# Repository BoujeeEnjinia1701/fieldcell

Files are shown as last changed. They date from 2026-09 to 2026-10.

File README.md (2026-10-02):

# FieldCell

     

**Area:** Situational Field Hardware · **TRL:** 3 of 9 (proof of concept on paper) · **Value-engineering target:** about $2,100 USD (estimated parts cost $2,101) · **Difficulty:** 3 of 5

Two-wheel hand cart carrying fold-out PV and a LiFePO4 bank, with an inverter and DC outlets, that one person can deploy in under 10 minutes.

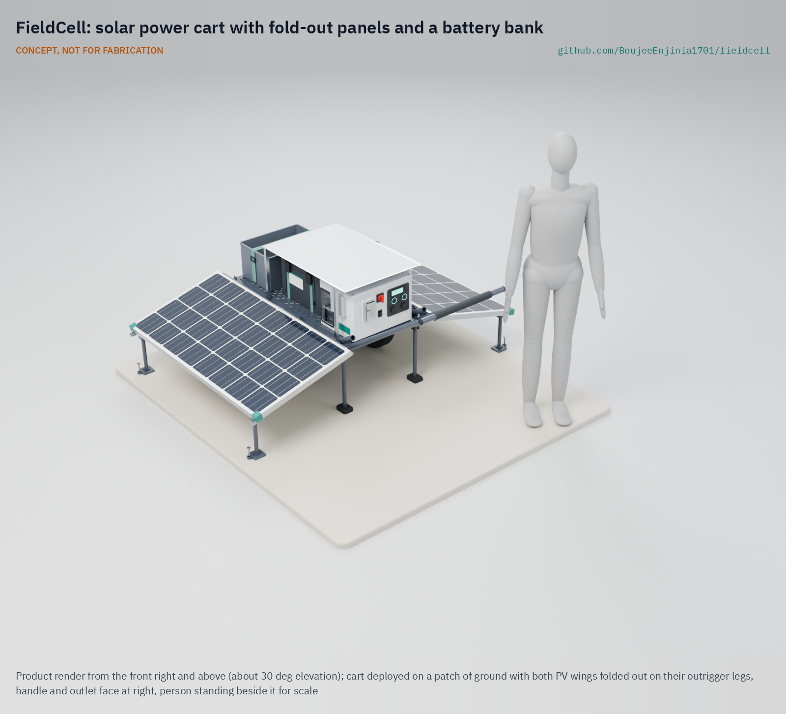
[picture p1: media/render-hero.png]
FieldCell: solar power cart with fold-out panels and a battery bank, product render


[Exploded render](media/render-exploded.png) · [Detail render](media/render-detail.png) · [Interactive 3D model](media/viewer.html) · [Concept blueprint (PDF)](media/concept-blueprint.pdf) · [General arrangement FCL-DWG-002 (PDF)](cad/drawings/FCL-DWG-002.pdf) · [Sizing calculations](docs/04-calcs/01-sizing.md) · [Prototype build plan](docs/05-build-plan.md) · [Design decisions](docs/06-design-decisions.md) · [Review note](docs/REVIEW.md)

## Concept rationale

Most field posts need a few hundred watts, not the several kilowatts of a generator, and they need it quietly, next to people, from the first hour. FieldCell puts about 1.3 kWh of LiFePO4 storage and 400 W of solar on a two-wheel cart whose sides are the panels themselves, so there is nothing to lay out, aim or cable on arrival: one person wheels it in, folds the wings down and switches on. The fixed east-west wings give up some energy against a sun-aimed panel in return for speed and a closed, protected box in travel.

It is open and garage-buildable because the organizations that deploy it, from volunteer fire brigades to small humanitarian teams, need to inspect, repair and adapt it where they work. A welded steel frame, off-the-shelf charge controller, inverter and outlets, and a priced, documented BOM mean it can be built and serviced with common tools and without custom electronics.

## Burning platform

Generators are the default for temporary power, and they kill. In the United States, portable generators were linked to 800 of 931 non-fire carbon monoxide deaths associated with engine-driven tools from 1999 to 2012, more than 85 % ([US Consumer Product Safety Commission, 2013](https://cpsc.gov/content/winter-warning-portable-generators-hold-top-spot-in-cpsc-report-on-carbon-monoxide-deaths)). The outages that send people to generators are getting longer: US electricity customers averaged 11 hours without power in 2024, nearly double the average of the previous decade, and major events such as Hurricanes Beryl, Helene and Milton accounted for 80 % of those hours ([US Energy Information Administration, 2025](https://www.eia.gov/todayinenergy/detail.php?id=66744)).

Where there is no grid at all, field teams start from nothing. In 2023, 666 million people still lacked electricity, 85 % of them in sub-Saharan Africa ([World Bank, *Tracking SDG 7*, 2025](https://www.worldbank.org/en/topic/energy/publication/tracking-sdg-7-the-energy-progress-report-2025)), so relief and survey crews there bring their own power or do without.

## Where it could be used

### By industry

| Industry | Use |
| --- | --- |
| Disaster response and emergency management | Quiet power for radios, lighting, laptops and chargers at incident command posts, shelters and search and rescue bases |
| Humanitarian aid | Registration desks, water points and clinics in camps where fuel is scarce and resupply is slow |
| Utilities and infrastructure | Daytime tool and battery charging for line, pipeline and telecom crews away from vehicle tracks |
| Environmental survey and conservation | Power for instruments, drones and camp electronics in protected areas where generators are unwelcome |
| Events and community resilience hubs | Shared phone charging, lighting and Wi-Fi in parks and schools during outages |
| Education | A teaching platform for PV, batteries, inverters and electrical safety |

### By country or region

| Country or region | Why it matters there |
| --- | --- |
| United States (Southeast and Gulf Coast) | South Carolina customers averaged nearly 53 hours without power in 2024, mainly from Hurricane Helene ([US EIA, 2025](https://www.eia.gov/todayinenergy/detail.php?id=66744)) |
| Philippines | An average of 20 tropical cyclones enter its area of responsibility each year, 8 or 9 of them crossing the country ([PAGASA](https://www.pagasa.dost.gov.ph/climate/tropical-cyclone-information)) |
| Pakistan | The 2022 monsoon floods affected an estimated 33 million people ([UN News, 2022](https://news.un.org/en/story/2022/08/1125752)) |
| Sub-Saharan Africa | Home to 85 % of the 666 million people without electricity in 2023 ([World Bank, 2025](https://www.worldbank.org/en/topic/energy/publication/tracking-sdg-7-the-energy-progress-report-2025)) |
| Caribbean (Puerto Rico and US Virgin Islands) | After Hurricanes Irma and Maria in 2017, restoring power to all customers whose structures were safe to reconnect took about 11 months in Puerto Rico and about 5 months in the US Virgin Islands ([US GAO, 2019](https://www.gao.gov/products/gao-19-296)) |

## What sparked the idea

The idea traces back to the US Marine Corps Experimental Forward Operating Base program, which equipped India Company, 3rd Battalion, 5th Marines in Sangin District, Afghanistan, with portable solar systems such as GREENS and SPACES. At Patrol Base Sparks, the unit reported that generators that typically burned more than 20 gallons (76 L) of fuel a day were down to 2.5 gallons (9.5 L), which meant fewer refuelling convoys exposed to roadside bombs ([DVIDS, January 6, 2011](https://www.dvidshub.net/news/63126/india-company-3-5-dark-horse-marines-use-solar-power-brighten-mission-accomplishment)). The same logic holds for a disaster zone, where every fuel run competes with rescue traffic. Those were military kits issued to trained units. FieldCell asks what an open, one-person version for civilian responders would look like: panels, battery and outlets on one cart, working minutes after arrival.

## Problem

Disaster responders and remote crews rely on noisy, fuel-hungry generators.

## Concept

Two-wheel hand cart carrying fold-out PV and a LiFePO4 bank, with an inverter and DC outlets, that one person can deploy in under 10 minutes.

FieldCell is the portfolio's mobile field-site unit: PV only, 1 kW AC, a one-person cart and its own 25.6 V pack. PowerBox is the household outage unit (multi-input, indoor, on a SwapCell pack), and SwapCell is the shared pack standard.

Full design precis: [docs/02-concept.md](docs/02-concept.md)

## Key components

- Folding PV panels 200 W (2)
- LiFePO4 bank 1.28 kWh (25.6 V 50 Ah)
- MPPT charge controller
- Inverter 1 kW
- Welded steel cart frame, 16 in flat-free wheels, detachable handle, folding stand legs
- IP65 battery case and IP54 electronics enclosure with thermostat filter fan
- Reflective sun shade over both enclosures, hinge line on a 20 mm spacer
- Two tie bars that hold the folded-up wings together for travel

The priced bill of materials is in [bom/bom.csv](bom/bom.csv) (about $2,101 at TRL 3, USD 1 over the $2,100 value-engineering target set on 2026-09-25, after the parts that make the design buildable; see the [design decisions register](docs/06-design-decisions.md)).

## Building the prototype

The [prototype build plan](docs/05-build-plan.md) (FCL-BLD-001) shows how to build the first FieldCell, component by component and step by step, with a making sketch for every made part and a picture for every assembly step. It is a plan, not a record of a build. The frame is welded from steel tube in a garage; the wings, shade and tie bars are cut and riveted from aluminium tube; the enclosures, electronics, wheels and modules are bought. Making the concept buildable added brackets, sockets, hinge tabs, tie bars and shade uprights (decision record FCL-DDR-003) and brought the cart to about 80 kg, inside the 82 kg limit set on 2026-10-02; the decisions are recorded in the [design decisions register](docs/06-design-decisions.md).

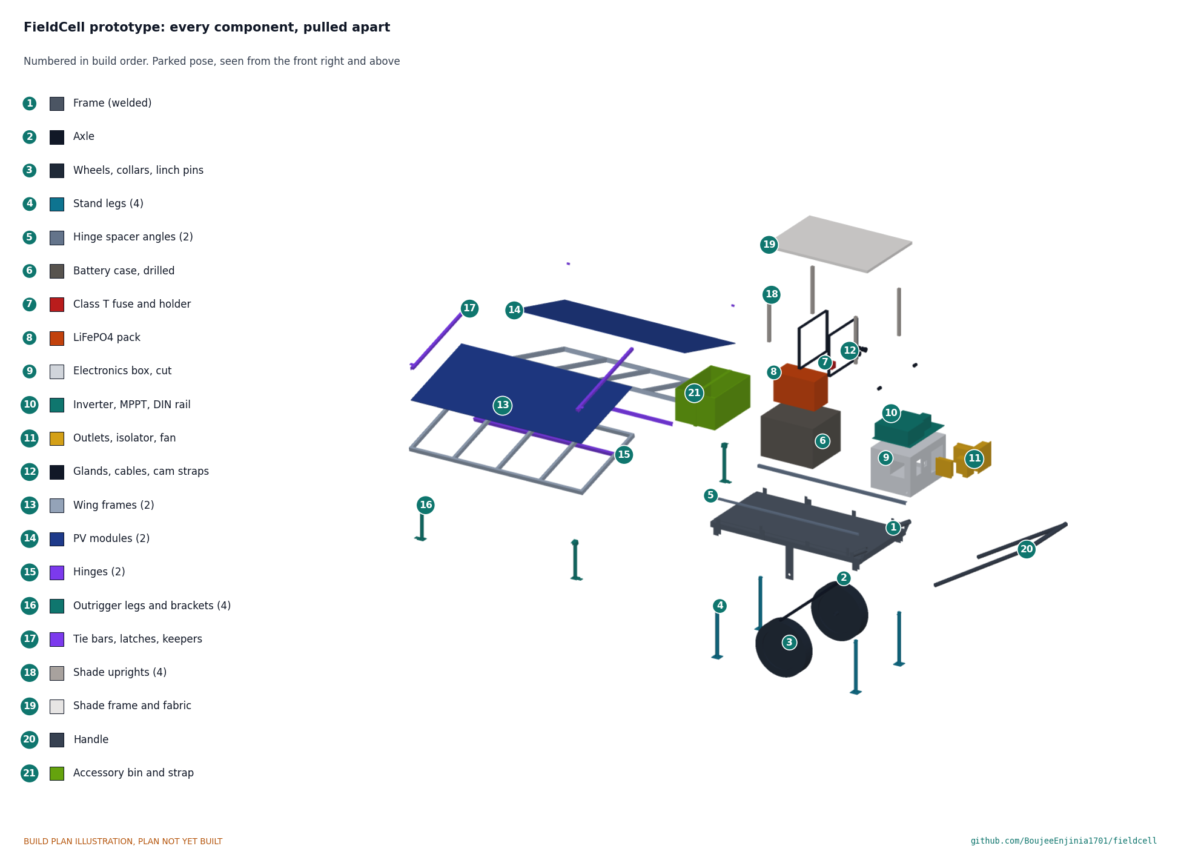
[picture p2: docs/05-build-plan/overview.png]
FieldCell prototype: every component pulled apart and numbered in build order


## Safety

> Contains a high-energy battery and AC output. Fuse every circuit and follow local electrical code.

## Repository layout

| Folder | Contents |
| --- | --- |
| `docs/` | Problem, concept, requirements, calculations and design decisions |
| `cad/src/` | build123d Python source, the source of truth for all geometry |
| `cad/step/`, `cad/stl/` | Exported models for FreeCAD, other CAD tools and printing |
| `cad/drawings/` | 2D sketches and dimensioned drawings |
| `bom/` | Bill of materials |
| `electronics/` | KiCad schematics and PCB layouts |
| `firmware/` | Microcontroller code |
| `media/` | Renders, perspectives and photos |
| `build-log/` | Dated prototyping notes |

## Documentation

Controlled documents follow the portfolio [documentation standard](.kit/STANDARDS.md). Each carries a document ID (FCL-PRC-001 for the precis), a version and a revision history. Branded PDFs are built with `python .kit/render.py` and attached to GitHub Releases when a document is tagged, for example `FCL-PRC-001/v1.0`.

## Credits

Designed by Amish Chadha. See [CONTRIBUTORS.md](CONTRIBUTORS.md) for roles. To cite this design, use [CITATION.cff](CITATION.cff) (GitHub shows it as "Cite this repository").

AI assistance (Claude) was used to accelerate concept renders, prototype documentation and first-pass sizing calculations. Design direction and all decisions are Amish Chadha's, recorded in this repository's decision records (`docs/decisions/`).

## Licenses

- **Hardware** (CAD, drawings, BOM, electronics): [CERN-OHL-S v2](LICENSE)
- **Software** (firmware, scripts, notebooks): [MIT](LICENSE-SOFTWARE)

A project of the [Design Molecule](https://designmolecule.com) lab.

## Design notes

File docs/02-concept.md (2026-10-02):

---
doc_id: FCL-PRC-001
title: FieldCell design precis
project: FieldCell
doc_type: Design precis
version: "0.7"
status: Draft
date: '2026-10-02'
author: Amish Chadha
license: CERN-OHL-S-2.0
revisions:
- version: "0.1"
  date: '2026-09-24'
  author: Amish Chadha
  change: Initial scaffold
- version: "0.2"
  date: '2026-09-24'
  author: Amish Chadha
  change: Populate to TRL 2 (architecture, first-order numbers, design choices, safety, media)
- version: "0.3"
  date: '2026-09-25'
  author: Amish Chadha
  change: TRL 3 update. Decisions of FCL-DDR-001 recorded; numbers replaced by FCL-CAL-001; parametric model, drawing FCL-DWG-002 and priced BOM
- version: "0.4"
  date: '2026-09-25'
  author: Amish Chadha
  change: Recommendations accepted by Amish (DDR-002)
- version: "0.5"
  date: '2026-10-01'
  author: Amish Chadha
  change: Constructable design (FCL-DDR-003); component table, numbers and safety notes follow FCL-CAL-001 v0.3; build plan FCL-BLD-001
- version: "0.6"
  date: '2026-10-01'
  author: Amish Chadha
  change: Budget treated as a value-engineering target
- version: "0.7"
  date: '2026-10-02'
  author: Amish Chadha
  change: "Mass and pull limits, charging inputs and portfolio positioning decided by Amish on 2026-10-02 (FCL-DEC-001)"
---

# FieldCell design precis

FieldCell is a two-wheel hand cart whose two sides are 200 W solar panels. For travel the panels stand up as the cart walls; on site they fold out as wings on outrigger legs. Between them sit a 1.28 kWh LiFePO4 pack, an MPPT charger, a 1 kW inverter and DC outlets. The TRL 3 calculations (FCL-CAL-001) show that it stores about 1.17 kWh a day from its own PV at 4 kWh/m²/day of global horizontal irradiation, carries a 0.9 kWh/day field load for 1.08 days without sun, and deploys in about 6.5 minutes. A reflective sun shade covers the battery and electronics enclosures, and the wing hinges sit on 20 mm spacers to clear the tyres. The design is constructable (FCL-DDR-003): every part can be made or bought and is fixed to its neighbours, as the prototype build plan FCL-BLD-001 shows. The parts that made it buildable bring the cart to about 80 kg against a 75 kg limit (R6) and the pull on a grass grade to 156 N against 150 N (R7), and the parts cost an estimated $2,101 against a $2,100 value-engineering target (R12, USD 1 over); how to close the mass and pull gaps is awaiting Amish and the savings worth trying are in FCL-DEC-001.

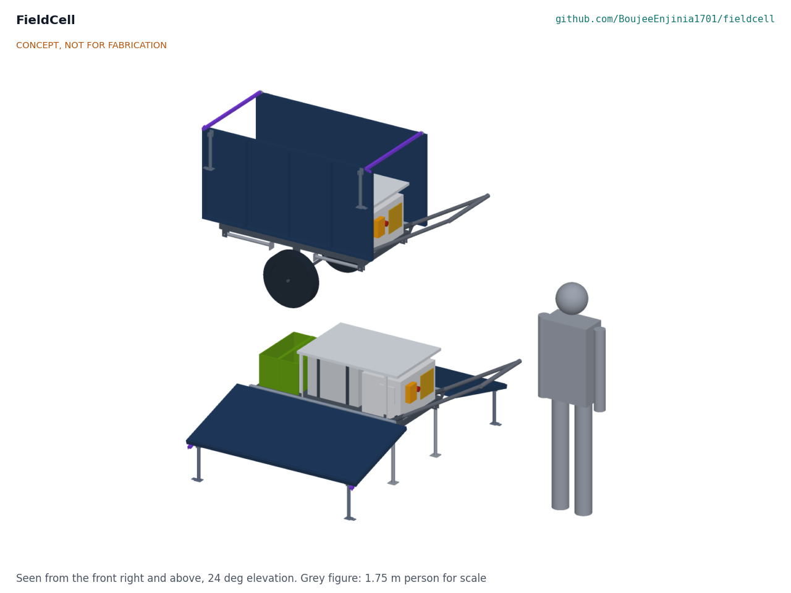
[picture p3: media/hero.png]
Hero render


*Figure 1. FieldCell deployed (front) and stowed for travel (behind), with a 1.75 m person for scale. Generated from the parametric model `cad/src/model.py`.*

## How it works

1. **Travel.** The wings stand upright as the cart sides, over the battery and electronics, held together at the top by two tie bars with over-centre latches. One person pulls or pushes the cart by the T-handle on two 16 in (406 mm) flat-free wheels. The sun shade sits on four uprights on the frame, 50 mm above the enclosures, and stays in place in travel. The center of gravity sits about 54 mm on the handle side of the axle, so the handle carries a light, positive load.
2. **Park.** Four stand legs fold down so the deck sits level at 460 mm.
3. **Deploy.** The tie bars unlatch and fold down the back of the left wing; each wing swings out on a continuous hinge, mounted on a 20 mm spacer angle bolted to tabs on the side rail, coming to rest 15° below horizontal on two fold-down outrigger legs. With the cart's long axis north to south, one wing faces east and one faces west. In wind, the four outrigger feet are staked.
4. **Charge.** The panels are pre-wired in parallel to the MPPT charge controller, which charges the 25.6 V pack. No cable is connected on site.
5. **Power.** The operator switches on the battery isolator and the inverter. Loads plug into the 120 V AC outlet (GFCI protected) and the DC panel (USB-C PD and 12 V sockets) on the handle end of the electronics box. A shunt monitor shows state of charge. A thermostat runs an IP54 filter fan when the box is warm, and the shade keeps direct sun off both enclosures.

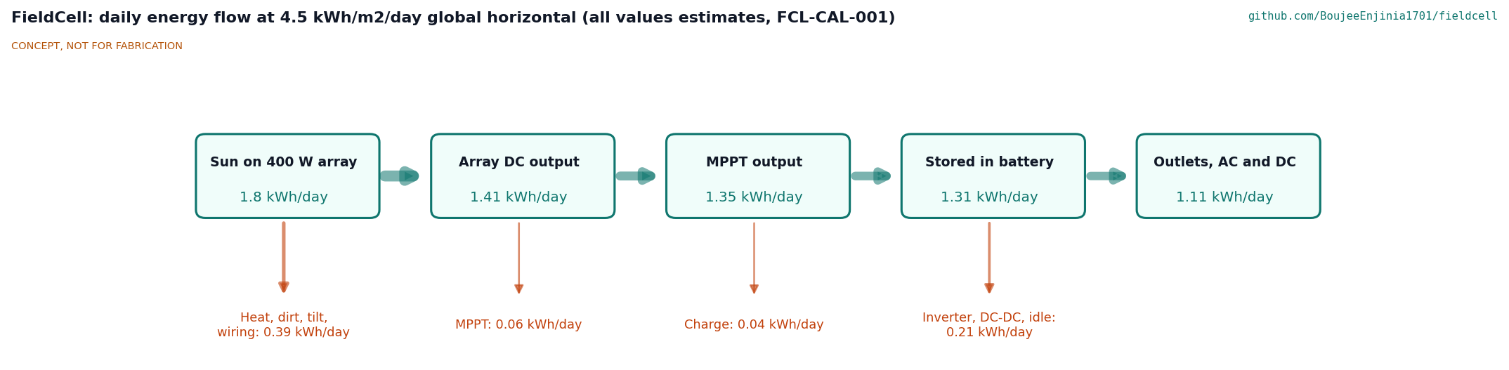
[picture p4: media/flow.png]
Energy flow


*Figure 2. Daily energy flow at 4.5 kWh/m²/day global horizontal irradiation. All values are estimates from FCL-CAL-001.*

## Main components

Numbers match the exploded view (Figure 3) and `bom/bom.csv`. Drawing FCL-DWG-002 gives the general arrangement and main dimensions.

*Table 1. Main components.*

| # | Component | Choice | Notes |
| --- | --- | --- | --- |
| 1 | Cart frame and axle | 40 x 40 x 1.5 mm steel square tube, 1,200 x 600 mm, expanded-metal deck on the cross tubes, braced axle brackets, 20 mm axle, hinge tabs, handle sockets, leg clevises | Welded steel, decided (FCL-DDR-001, D5); about 15.4 kg (FCL-DDR-003) |
| 2 | Wheels (2) | 16 in (406 mm) flat-free, 720 mm track | Flat-free, decided (D5); about 4 kg each |
| 3 | Handle | Steel T-handle, grip at 900 mm, in two welded sockets with quick-release pins | Detaches for vehicle transport |
| 4 | Stand legs (4) | Tube legs on welded clevises, folding along the rails, detent pins | Level the deck when parked |
| 5 | Battery enclosure | IP65 case, about 420 x 360 x 300 mm | Sits over the axle, lowest heavy item |
| 6 | LiFePO4 pack | 25.6 V 50 Ah (1.28 kWh), 100 A BMS with low- and high-temperature charge cutoff | 24 V system, decided (D1) |
| 7 | Electronics enclosure | IP54, about 320 x 460 x 300 mm, IP54 filter fan (about 40 m³/h) and exhaust filter | Outlet face toward the handle; thermostat filter fan decided (FCL-DDR-002) |
| 8 | MPPT charge controller | 100 V, 20 A | At most 15 A from 400 W |
| 9 | Inverter | 1 kW continuous, 2 kW surge, pure sine, high-frequency, 24 V input, 120 V 60 Hz | 120 V first, 230 V 50 Hz variant documented, decided (D4) |
| 10 | DC outlet panel | 2 x USB-C PD 100 W, 2 x 12 V sockets, 24 to 12 V 20 A converter | 440 W DC in total |
| 11 | AC outlet with GFCI | GFCI duplex (120 V), in-use cover; 30 mA RCD socket for the 230 V variant | |
| 12 | Fusing and disconnect | Class T 100 A main fuse in the battery case within 150 mm of the terminal, isolator on the outlet face, DC breakers, shunt monitor | Fuse position fixed by FCL-DDR-003 |
| 13 | PV wings (2) | 200 W semi-flexible module bonded to a 1,400 x 700 mm frame of 30 x 20 mm aluminium tube with three ribs, 35 mm deep, about 6.0 kg, 24 V class (Vmp about 36 V) | Parallel wiring, decided (D3) |
| 14 | Panel hinges, spacers and latches | 1.2 m piano hinge per side on a 20 × 20 × 2 mm aluminium angle spacer bolted to steel tabs on the rail; two over-center latches for the tie bars | Spacer raises the hinge line, decided (FCL-DDR-002); pinch points, see Safety |
| 15 | Outrigger legs (4) | Legs on riveted brackets under the wing's outer edge, folding flat under the wing, with stake loops and stakes; set the 15° tilt | Stakes required above about 9 m/s wind |
| 16 | Accessory and cable bin | Open bin, balances the electronics box | Cords, lights, stakes |
| 17 | Wiring and hardware | 16 mm² (6 AWG) battery cable, PV cable, glands, cam straps, fasteners | Battery cables, glands and straps modeled |
| 18 | Sun shade | Reflective aluminized fabric on a light aluminium frame, about 830 × 580 mm, on four 355 mm uprights bolted to the rails, about 1.55 kg | Over both enclosures, decided (FCL-DDR-002); lifts off to open the battery case |
| 19 | Wing tie bars (2) | 20 × 20 mm aluminium bars pivoted on the left wing, latched to the right wing across the tops in travel | Added by FCL-DDR-003 |

## Key numbers

All values are estimates from FCL-CAL-001 (`docs/04-calcs/sizing.py`), which checks every requirement.

*Table 2. Key numbers.*

| Quantity | Value | Basis | Requirement |
| --- | --- | --- | --- |
| Stored energy | 1.28 kWh nominal, 1.15 kWh usable | 25.6 V x 50 Ah; 90 % depth of discharge | R1 met |
| PV energy into battery | 1.17 kWh/day at 4 kWh/m²/day, 1.31 at 4.5, 1.46 at 5 (25 °C air) | 400 W x GHI x 0.729 (transposition 0.947, temperature 0.915, other losses) | R3 met |
| East-west penalty | About 14 % against one panel aimed south at latitude tilt | Clear-sky model at 15, 30 and 45° N | |
| Peak charge power | About 260 to 290 W | Noon, east-west wings | |
| Full recharge, 10 to 100 %, no load | 0.79 day at 5 kWh/m²/day | 1,152 Wh / daily yield | R3 met |
| Reference load from battery | 1,063 Wh/day | 897 Wh at the outlets, Table 4 | |
| Autonomy with no sun | 1.08 days | 1,152 / 1,063 Wh | R4 met |
| Battery current | 46 A at 1 kW AC; 66 A with full DC; 98 A surge | 24 V at the low end | R2 met |
| Total mass | About 80.0 kg | Table 5 | R6 met (2.0 kg under the 82 kg limit set on 2026-10-02) |
| Center of gravity | 54 mm toward the handle from the axle, 561 mm above ground | Table 5 | R6 |
| Handle force, travel | 34 N level; 14 to 54 N at a 5° pitch | CG offset x weight / 1,240 mm axle to grip | R6 met |
| Lateral static tip angle | 32.7° | atan(360 mm half-track / 564 mm CG height) | R7 met |
| Pull force, 10 % grade | 125 N (gravel) to 156 N (grass) | 785 N weight x (grade + rolling resistance) | R7 met (grass, 160 N limit set on 2026-10-02) |
| Ground clearance | 193 mm | Under the axle, legs folded | R7 met |
| Deploy and stow time | 6.5 and 5.5 min | Table 6 | R5 met |
| Deployed footprint | About 2.0 x 2.0 m including the handle | Model, wings at 15° | |
| Stowed size, handle off | 1,400 x 830 x 1,220 mm | Model | |
| Wing to tyre clearance, deployed | 28 mm | Model, 20 mm hinge spacer | |
| Electronics box at 45 °C ambient | About 53 °C with the fan and shade, 70 °C sealed and unshaded, at 1 kW | Section G of FCL-CAL-001 | R9 at risk |
| Pack under the shade, noon, 45 °C ambient | About 48 °C (55 °C unshaded) | Section G of FCL-CAL-001 | R9 at risk |
| Wing lift-off wind speed, unstaked | About 8.9 m/s | Normal force coefficient 1.2 on 0.98 m², wing weight 59 N | R10 met only staked |
| Parts cost | About $2,101 against the $2,100 value-engineering target | `bom/bom.csv` | **R12 over the value-engineering target by USD 1** |

### PV yield

FCL-CAL-001 reads "peak sun hours" as daily global horizontal irradiation (GHI) and converts it to the wings with a clear-sky transposition model. At 15° the east-west wings collect about 0.95 of GHI, nearly as much as a horizontal panel, but about 14 % less than one panel aimed south at latitude tilt; the penalty is larger in winter at high latitude. With the cells at about 47 °C in 25 °C air, the 400 W array delivers about 0.78 of its rating times GHI at its terminals and 0.73 into the battery. At 4.5 kWh/m²/day that is 1.80 kWh at rating, 1.41 kWh at the array, 1.35 kWh after the MPPT and 1.31 kWh into the battery (Figure 2).

### Load profile and days of autonomy

The reference load is a small field post: a responder team's comms and lighting, one laptop station, and occasional tool use.

*Table 3. Reference load profile (assumed).*

| Load | Power | Hours per day | Energy at outlet | Path |
| --- | --- | --- | --- | --- |
| LED area lighting | 30 W | 8 | 240 Wh | DC |
| Radio, phone and satellite messenger charging | 30 W | 8 | 240 Wh | DC |
| Laptop and Wi-Fi router | 50 W | 6 | 300 Wh | AC |
| Power tool or small pump | 700 W | 1/6 (10 min) | 117 Wh | AC |
| **Total** | | | **897 Wh** | |

*Table 4. Energy drawn from the battery (assumed efficiencies, FCL-CAL-001).*

| Path | At outlet | Efficiency | From battery |
| --- | --- | --- | --- |
| DC (USB-C and 12 V converters) | 480 Wh | 0.93 | 516 Wh |
| AC (inverter), including 10 W idle for 7 h | 417 Wh | 0.92 plus idle | 523 Wh |
| Standby and filter fan | | | 24 Wh |
| **Total** | **897 Wh** | **0.844 overall** | **1,063 Wh** |

With 1.15 kWh usable, the pack carries this load for 1.08 days with no sun. At 4 kWh/m²/day the PV stores 1.17 kWh/day, a surplus of about 10 %; at 4.5 the surplus is about 24 %. The system breaks even at about 3.6 kWh/m²/day. A run of cloudy days is not covered. Inverter idle draw is the most sensitive assumption: each extra 5 W costs about 3 % of the daily load.

### Mass and center of gravity

*Table 5. Mass budget, wings stowed, deck level. X is measured from the deck center toward the handle; the axle is at X = 30 mm. From FCL-CAL-001 v0.3.*

| Item | Mass (kg) | X (mm) | Z (mm) |
| --- | --- | --- | --- |
| Frame, deck and axle (welded steel) | 15.4 | 5 | 420 |
| Wheels, flat-free (2), collars, pins | 8.3 | 30 | 203 |
| Handle | 2.6 | 950 | 700 |
| Stand legs | 2.5 | 0 | 230 |
| Battery enclosure | 3.0 | 0 | 610 |
| LiFePO4 pack | 12.0 | 0 | 576 |
| Electronics enclosure, filter fan, inverter, MPPT, fusing, monitor and outlets | 11.3 | 430 | 568 |
| Accessory bin and cables | 4.0 | −420 | 560 |
| PV wings, stowed (2) | 12.0 | 0 | 845 |
| Hinges, latches, outriggers and stakes | 4.1 | 0 | 820 |
| Hinge spacers (2) | 0.5 | 0 | 484 |
| Sun shade, frame and uprights | 1.6 | 185 | 760 |
| Wing tie bars (2) | 0.5 | 0 | 1,205 |
| Wiring, hardware and straps | 2.3 | 200 | 600 |
| **Total** | **80.0** | **84** | **561** |

The center of gravity is 54 mm on the handle side of the axle. At the 900 mm grip the handle carries about 34 N (3.5 kgf), and it stays positive between 14 and 54 N if the user holds the cart 5° nose-up or nose-down. The load in the accessory bin is the trim: moving 4 kg of cords from the bin to the electronics end raises the handle force by about 27 N. Amish relaxed the R6 limit to 75 kg on 2026-09-25 to keep the decided steel frame and flat-free tyres (FCL-DDR-002). Making the design buildable (FCL-DDR-003) added the brackets, gussets, tabs, sockets, clevises, fixings, tie bars and shade uprights the massing model did not have, about 4.9 kg, so the cart is about 5 kg over the limit and the pull on a 10 % grass grade is 156 N against 150 N. A bolted aluminium frame would bring the cart to about 72.7 kg. How to close the gap is an open decision, awaiting Amish (FCL-DEC-001, item 2).

### Deployment sequence

*Table 6. Deploy and stow time estimates, one person.*

| Deploy step | Time | Stow step | Time |
| --- | --- | --- | --- |
| Turn the cart north to south, drop four stand legs | 1.0 min | Loads off, inverter off, isolator off | 0.5 min |
| Unlatch both tie bars, fold each down the left wing | 0.5 min | Pull four stakes | 1.0 min |
| Fold the first wing out, swing down its two outrigger legs | 1.5 min | Fold the first wing's outriggers, raise it | 1.5 min |
| Same for the second wing | 1.5 min | Same for the second wing | 1.5 min |
| Stake the four outrigger feet (when wind is expected) | 1.0 min | Swing both tie bars over and latch them | 0.5 min |
| Isolator on, check the monitor, inverter on, plug in loads | 1.0 min | Raise four stand legs | 0.5 min |
| **Total** | **6.5 min** | **Total** | **5.5 min** |

## Key design choices

- **Panels as the cart walls, in fixed east-west wings at 15°.** The wings protect the battery and electronics in travel and need no separate storage, cables or aiming on site; they cost about 14 % of the energy a south-aimed panel would collect. Decided by Amish, 2026-09-25 (FCL-DDR-001, D2).
- **24 V class panels in parallel.** With Vmp about 36 V each, the panels can be paralleled into one MPPT and still charge a 25.6 V pack, so the off-sun wing does not limit the other. At 70 °C cell the headroom above the absorption voltage is under 1 V, so the chosen module must have Vmp of at least 36 V at STC. Decided by Amish, 2026-09-25 (D3).
- **25.6 V battery system.** Halves the current of a 12.8 V system (46 A instead of about 90 A at 1 kW), allowing thinner cable and a smaller fuse, while 24 V inverters and MPPT controllers remain common. Decided by Amish, 2026-09-25 (D1).
- **120 V 60 Hz output first.** A 230 V 50 Hz variant swaps the inverter and uses a 30 mA RCD socket. Decided by Amish, 2026-09-25 (D4).
- **Welded steel frame and flat-free tyres.** Easiest garage build and no punctures on debris, at a mass cost that put the cart over the earlier 75 kg R6 limit. Decided by Amish, 2026-09-25 (D5), and kept on 2026-10-02 with R6 set at 82 kg (FCL-DEC-001).
- **SwapCell compatibility as a future option only.** A later variant could take a SwapCell 48 V pack in place of item 6, which would need a 48 V inverter and charger. It would rely on three SwapCell interface v0.3 items approved portfolio-wide: a wake method for hosts without CAN, a charge-while-discharging mode (FieldCell charges from PV while loads run) and a latch vibration rating for vehicles. Decided by Amish, 2026-09-25 (D6).
- **Heavy parts low and over the axle.** The battery sits directly over the axle; the electronics box and the accessory bin balance each other fore and aft. Kept as a layout rule, decided by Amish, 2026-09-25 (FCL-DDR-002).
- **Forced ventilation of the electronics box.** A thermostat-controlled IP54 filter fan (40 to 60 m³/h) and exhaust filter keep the box within about 10 K of ambient at 1 kW; a sealed box would reach about 70 °C at 45 °C ambient. Decided by Amish, 2026-09-25 (FCL-DDR-002).
- **Sun shade over the enclosures.** A reflective shade on four posts keeps direct sun off the battery case and electronics box, holding the pack at about 48 °C instead of 55 °C at 45 °C ambient, for about $30 and 1 kg. Decided by Amish, 2026-09-25 (FCL-DDR-002).
- **Hinge spacer.** A 20 mm aluminium angle under each hinge raises the hinge line from 470 to 490 mm and opens the deployed wing-to-tyre clearance from 8 to 28 mm. Decided by Amish, 2026-09-25 (FCL-DDR-002).
- **Irradiance basis.** "Peak sun hours" in R3 and R4 means daily global horizontal irradiation in kWh/m²/day. Confirmed by Amish, 2026-09-25 (FCL-DDR-002).

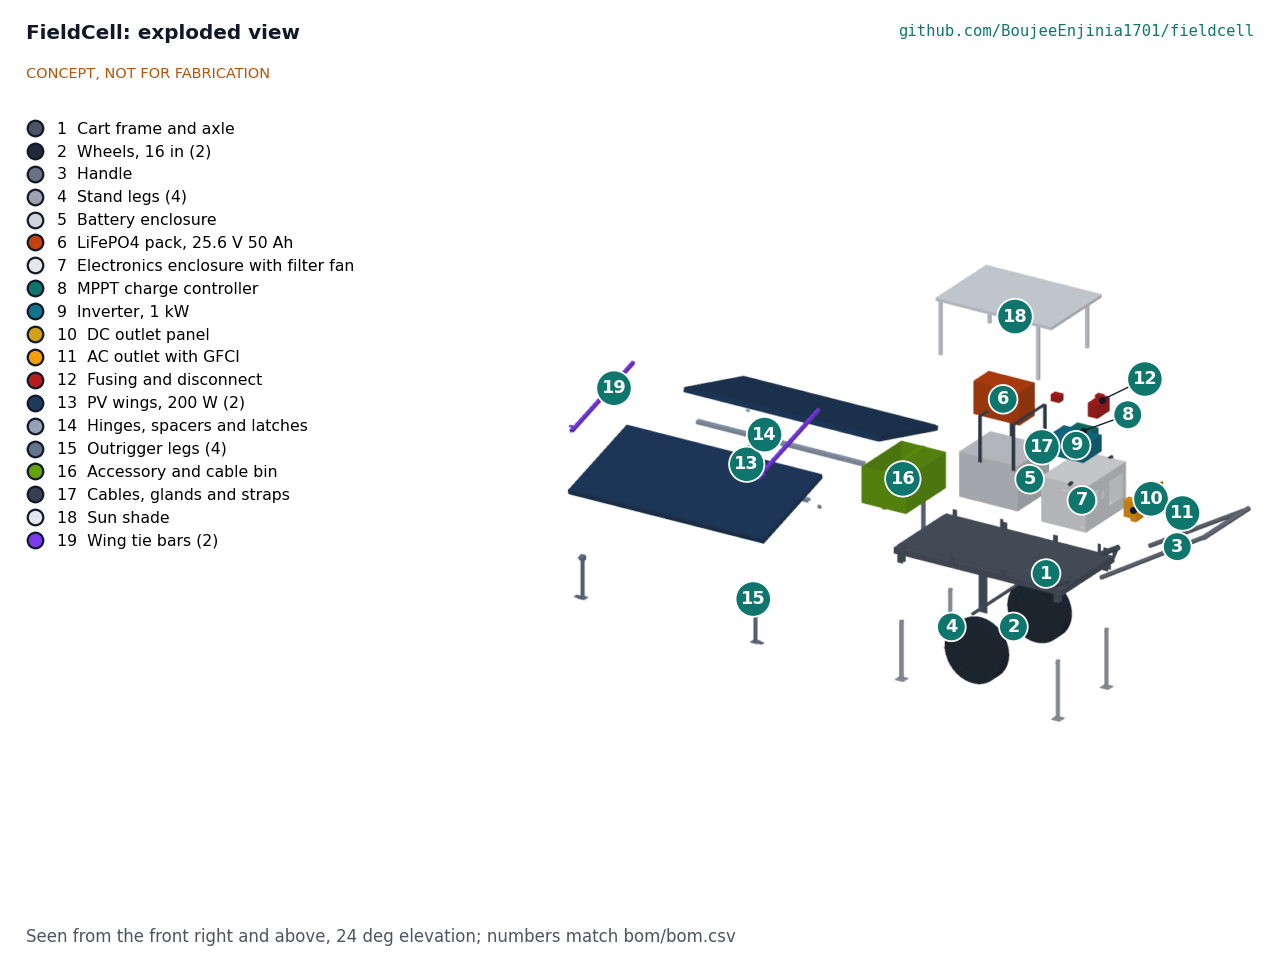
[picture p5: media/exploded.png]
Exploded view


*Figure 3. Exploded view with numbered callouts matching `bom/bom.csv`. The wings and their hinges, outriggers and tie bars (13, 14, 15, 19) are drawn off to the front so the boxes stay visible.*

## Safety

> **Safety:** FieldCell combines a 1.28 kWh lithium battery, 120 V or 230 V AC output, high-current DC wiring, always-live PV panels and a cart of about 75 kg with folding wings. Every one of these is hazardous if the design or the build is wrong.

- **Lithium battery.** Use a LiFePO4 pack with a BMS that protects against overcharge, over-discharge, overcurrent, short circuit and over-temperature, and blocks charging below 0 °C and above about 45 °C. Put a class T fuse within about 150 mm of the positive terminal; in the constructable design it sits inside the battery case beside the pack. Secure the pack so it cannot shift in a tip-over, keep the enclosure vented to outside air, and keep sharp objects and debris out of it. In noon sun at 45 °C ambient the pack can reach about 55 °C unshaded and about 48 °C under the sun shade, so keep the shade in place. Shipping a pack of this size is regulated as dangerous goods.
- **AC output (120 V or 230 V).** Protect every AC outlet with a GFCI (120 V) or a 30 mA RCD (230 V). Bond the inverter neutral and ground to the frame only as the inverter maker specifies for a stand-alone portable source. Use in-use covers in rain, and keep outlets off wet ground.
- **Not for building wiring.** FieldCell has no power inlet and must never be connected to building or grid wiring, including by a "suicide cord" into an outlet. Back-feed can kill utility workers and damage both systems. Any such connection is out of scope.
- **DC wiring and fusing.** Fuse every circuit at its source: main class T fuse at the battery, breakers for the inverter, MPPT and DC outlets, and a PV breaker as the array disconnect. Size cables for the fuse rating. A battery isolator must be reachable without tools. The 2 kW surge with full DC load draws about 118 A for a few seconds; the BMS and fuse must tolerate this.
- **PV panels are live whenever lit.** Open-circuit voltage is about 45 V per panel, up to about 50 V in cold weather, and cannot be switched off at the panel. Do not disconnect PV connectors under load, and cover or disconnect the panels before working in the electronics box.
- **Lifting and handling.** At about 80 kg the cart must not be lifted by one person. Use two people to load it into a vehicle, and remove the battery pack (12 kg) first when possible.
- **Tipping.** The lateral tip angle is about 32.6° when stowed; do not traverse slopes across the fall line, and keep the handle low when descending. When deployed, wings can lift in wind above about 9 m/s unless the outrigger feet are staked; stow the wings in high wind. A stowed cart can be blown over at about 21 m/s side wind.
- **Pinch points.** The wing hinges, tie bar latches and folding legs can trap fingers. The tie bars must be latched to hold the wings firmly in travel. The deployed wing clears the tyre by about 28 mm; keep fingers out of that gap when folding.
- **Heat.** The inverter and MPPT shed up to about 140 W inside the electronics box. Keep the filter fan and exhaust filter clear, and do not run at high load with the vents covered or with the sun shade removed.

## Open questions

- Mass, pull force and cost: about 80 kg and 156 N on a grass grade after the design was made buildable. Decided by Amish, 2026-10-02: R6 set at 82 kg and the R7 grass pull at 160 N, keeping steel and flat-free tyres; the prototype is weighed at TRL 4 and moves to a bolted aluminium frame if it is over 82 kg (FCL-DEC-001). The cost is $2,101 against the $2,100 value-engineering target (R12).
- Inverter derating data at 45 °C (R9) and supplier quotes for the pack, PV wings and inverter to set the real cost against the $2,100 value-engineering target. Decided by Amish, 2026-09-25 (FCL-DDR-002); to be obtained with supplier selection.
- Confirm the inverter idle draw and fan noise (R11) and the filter fan noise from datasheets.
- Whether an AC charger or a vehicle 12 V input should be added for cloudy periods. Decided by Amish, 2026-10-02: no AC charger, since a power inlet is ruled out by the safety case; the vehicle 12 V input is left out of the first prototype and may be offered later as a DC-to-DC charging option if the responder review asks for it (FCL-DEC-001).
- How FieldCell relates to PowerBox and SwapCell in the portfolio. Decided by Amish, 2026-10-02: FieldCell is the mobile field-site unit (PV only, 1 kW AC, one-person cart, own 25.6 V pack), PowerBox the household outage unit (multi-input, indoor, SwapCell pack) and SwapCell the shared pack standard (FCL-DEC-001).
- Handle geometry and grip height for users from 1.55 to 1.90 m tall.

Concept media: [blueprint sheet](../media/concept-blueprint.pdf), [cutaway](../media/cutaway.png), [interactive 3D model](../media/viewer.html). General arrangement: [FCL-DWG-002](../cad/drawings/FCL-DWG-002.pdf). Prototype build plan: [FCL-BLD-001](05-build-plan.md).

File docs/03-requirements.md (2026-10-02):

---
doc_id: FCL-REQ-001
title: FieldCell requirements
project: FieldCell
doc_type: Requirements
version: "0.7"
status: Draft
date: '2026-10-02'
author: Amish Chadha
license: CERN-OHL-S-2.0
revisions:
- version: "0.1"
  date: '2026-09-24'
  author: Amish Chadha
  change: Initial scaffold
- version: "0.2"
  date: '2026-09-24'
  author: Amish Chadha
  change: First measurable requirements for TRL 2
- version: "0.3"
  date: '2026-09-25'
  author: Amish Chadha
  change: Status of every requirement from FCL-CAL-001; R2 names 120 V 60 Hz for the first build (FCL-DDR-001); irradiance basis stated
- version: "0.4"
  date: '2026-09-25'
  author: Amish Chadha
  change: Recommendations accepted by Amish (DDR-002)
- version: "0.5"
  date: '2026-10-01'
  author: Amish Chadha
  change: Values and status from FCL-CAL-001 v0.3 for the constructable design (FCL-DDR-003); no target changed
- version: "0.6"
  date: '2026-10-01'
  author: Amish Chadha
  change: Budget treated as a value-engineering target
- version: "0.7"
  date: '2026-10-02'
  author: Amish Chadha
  change: "R6 set at 82 kg and the R7 grass pull at 160 N by Amish on 2026-10-02 (FCL-DEC-001); both now met on paper"
---

# FieldCell requirements

These are the requirements for the concept. The value and status columns come from the TRL 3 calculation note FCL-CAL-001 v0.3, which checks each one by calculation against the constructable design of FCL-DDR-003. Eight are met, none is not met, one is over its value-engineering target (R12 cost, by $1), one is at risk (R9) and two cannot be verified until test (R8 and R11). On 2026-10-02 Amish set the R6 mass limit at 82 kg and the R7 grass pull at 160 N, keeping the steel frame and flat-free tyres; the prototype is weighed at TRL 4 and moves to a bolted aluminium frame if it is over 82 kg (FCL-DEC-001); the cost savings worth trying for R12 are in its Value engineering section. On 2026-09-25 Amish accepted the TRL 3 recommendations (FCL-DDR-002): the R6 mass limit is relaxed from 70 kg to 75 kg, the value-engineering target behind R12 moves from $1,500 to $2,100, R3 and R4 are stated in global horizontal irradiation, and R8 and R9 name the filter fan and sun shade.

*Table 1. Requirements.*

| ID | Requirement | Target | Value at TRL 3 (FCL-CAL-001 v0.3) | Status | Verification |
| --- | --- | --- | --- | --- | --- |
| R1 | Store enough energy for a day of field use | 1.2 kWh nominal or more; 1.0 kWh usable or more | 1.28 kWh nominal, 1.15 kWh usable at 90 % depth of discharge | Met | Calculation; datasheet |
| R2 | Supply AC and DC loads | 1,000 W continuous pure sine AC at 120 V 60 Hz for the first build (230 V 50 Hz variant), 2,000 W surge; DC outlets 300 W or more in total (USB-C PD and 12 V) | 1 kW inverter by selection; 440 W DC; 66 A continuous battery current on a 100 A fuse and BMS | Met | Calculation; datasheets |
| R3 | Recharge from its own PV | 1.1 kWh/day or more into the battery at 4 kWh/m²/day of global horizontal irradiation (GHI, "peak sun hours"); full recharge from 10 % in one day at 5 kWh/m²/day GHI with no load | 1.17 kWh/day at 4 kWh/m²/day (1.09 in 40 °C air); full recharge in 0.79 day at 5 | Met | PV yield calculation; later logged trial |
| R4 | Carry a reference load through a day without sun | Reference load of 0.9 kWh/day at the outlets for 1 day or more with no sun; energy-neutral at 4 kWh/m²/day GHI or more | 1.08 days; +10 % surplus at 4 kWh/m²/day; break-even at 3.64 | Met | Load and energy balance; later logged trial |
| R5 | Deploy fast with one person | From arrival to power available in 10 min or less, one person, no tools; stow in 10 min or less | 6.5 min deploy, 5.5 min stow by task analysis, including the tie bars | Met | Task analysis; later timed trial |
| R6 | Movable by one person | Total mass 82 kg or less (relaxed from 70 kg to 75 kg in FCL-DDR-002 and to 82 kg on 2026-10-02, FCL-DEC-001); vertical handle force 10 to 150 N (never negative) over a 5° pitch either way; heaviest removable module 25 kg or less | 80.0 kg; 14 to 54 N; pack 12.0 kg | Met on paper (mass 2.0 kg under; to be weighed at TRL 4) | Mass budget and CG calculation; later weighing |
| R7 | Cross rough ground | 16 in (406 mm) wheels or larger; ground clearance 150 mm or more; climb a 150 mm step; pull force 150 N or less on a 10 % grade over gravel and 160 N or less over grass (grass relaxed from 150 N on 2026-10-02, FCL-DEC-001); static lateral tip angle 25° or more | 406 mm wheels; 193 mm clearance; step with about 149 N pull at the grip; 125 N gravel, 156 N grass; 32.7° | Met on paper (grass pull 4 N under) | Geometry and force calculation |
| R8 | Work in rain and dust | Electronics enclosure IP54 while operating, ventilated by a thermostat-controlled IP54 filter fan and exhaust filter (FCL-DDR-002); battery enclosure IP65; all cable entries through glands or sealed connectors | IP54 enclosure with IP54 filter fan and exhaust filter; IP65 case; glands, by selection | Not verifiable at TRL 3 | Design review; later spray and dust test |
| R9 | Stay safe across field temperatures | Operate at −10 to 45 °C ambient; BMS blocks charging below 0 °C cell temperature; inverter derating known at 45 °C; reflective sun shade over both enclosures when deployed (FCL-DDR-002) | Charge block by BMS selection; electronics box about 53 °C at 45 °C ambient with the fan and shade (70 °C sealed, unshaded); pack under the shade about 48 °C at 45 °C ambient, so charging stops only above about 42 °C ambient; derating data not yet obtained | At risk | Thermal estimate; datasheets |
| R10 | Stay put in wind when deployed | Wings and cart stable to 15 m/s (54 km/h) with the four outrigger feet staked or ballasted; stow instruction above that | Staked: 28 N pull-out per foot at 15 m/s (50 N with a 1.5 factor); unstaked wings lift at about 8.9 m/s | Met (staked) | Wind load calculation |
| R11 | Be quiet | 45 dB(A) or less at 1 m at 500 W load | About 41 dB(A) from assumed fan levels, not datasheet values | Not verifiable at TRL 3 | Datasheets; later sound level measurement |
| R12 | Be electrically safe and affordable | Every circuit fused at its source; GFCI (120 V) or 30 mA RCD (230 V) on all AC outlets; battery disconnect reachable without tools; no inlet or path to building wiring; parts cost at or below the value-engineering target of $2,100 | Safety provisions met by design (class T fuse inside the battery case, within 150 mm of the terminal); parts about $2,101 | Safety provisions met by design; **over the value-engineering target by USD 1** | Design review; priced BOM |

## Assumptions

- "Peak sun hours" in R3 and R4 is daily global horizontal irradiation in kWh/m²/day, the figure most climate data give. FCL-CAL-001 converts it to the east-west wings with a transposition ratio of about 0.95. Confirmed by Amish, 2026-09-25 (FCL-DDR-002).
- 4 to 5 kWh/m²/day covers clear-season sites at low and middle latitudes; a cloudy week or a high-latitude winter is not covered by R3 or R4.
- The reference load in R4 is defined in FCL-PRC-001, Table 3: lighting, radio and phone charging, a laptop and router, and short power-tool bursts.
- Usable battery capacity is 90 % of nominal, for LiFePO4 cells with a conservative BMS.
- "Arrival" in R5 means the cart has been wheeled to the chosen spot; choosing the spot is not timed.
- The target in R12 is `budget_usd` in `project.yaml`, a hypothetical control target that keeps the design thinking along a value-engineering lens. It moved from $1,500 to $2,100 (BOM plus a small contingency) by Amish's decision of 2026-09-25 (FCL-DDR-002). Supplier quotes for the pack, PV wings and inverter will give the real cost.
- The R6 mass limit of 82 kg (set on 2026-10-02) keeps the decided steel frame and flat-free tyres and leaves a 2 kg margin over the 80.0 kg constructable cart; above 82 kg at weighing the frame becomes bolted aluminium. The cart is a two-person lift either way; the handle force is what one person feels, and it stays within limits. The R7 grass pull limit of 160 N follows the same decision.

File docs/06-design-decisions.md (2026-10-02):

---
doc_id: FCL-DEC-001
title: FieldCell design decisions register
project: FieldCell
doc_type: Design decisions register
version: "0.3"
status: Draft
date: '2026-10-02'
author: Amish Chadha
license: CERN-OHL-S-2.0
revisions:
  - version: "0.1"
    date: '2026-10-01'
    author: Amish Chadha
    change: Register opened with the open decisions of FCL-DDR-001 to 003 and the review note, items to confirm when parts are bought, and decisions made
  - version: "0.2"
    date: '2026-10-01'
    author: Amish Chadha
    change: Budget treated as a value-engineering target
  - version: "0.3"
    date: '2026-10-02'
    author: Amish Chadha
    change: "Amish approved the recommendations for all eight open decisions (FCL-DDR-003 accepted); moved to decisions made"
---

# FieldCell design decisions register

Every design decision still to be made, and every decision made, in one place. Each decision is argued in full in its decision record under `docs/decisions/`; this register is the index Amish works from. The build plan (`docs/05-build-plan.md`) describes the design as it stands and does not list open decisions.

## Open decisions

None. All open decisions were decided on 2026-10-02.

## To confirm when parts are bought

*Table 1. Items to confirm when parts are bought.*

| # | What to confirm | Why it matters | Source |
| --- | --- | --- | --- |
| 1 | The solar module is no larger than 1,380 x 680 mm, has Vmp of 36 V or more at standard test conditions, has a back that takes structural tape, and leads long enough to reach the electronics box | Sets the 10 mm rim on the wing frame and the charge headroom at 70 °C | FCL-DDR-003, P7; FCL-DDR-001, D3; FCL-CAL-001 [B4] |
| 2 | The wheel hub is about 60 mm long with a 20 mm bore and bearings | Sets the spacer collar length (37.5 mm) and the axle length (820 mm) | FCL-DDR-003, P3 |
| 3 | The electronics box's mounting plate, its bosses, and the cut-out templates of the DC panel, GFCI and in-use cover, isolator, filter fan and exhaust filter | They set the cut-outs and the layout on the plate | FCL-DDR-003, P11 |
| 4 | The inverter (about 270 x 210 x 110 mm) and charge controller (about 150 x 140 x 70 mm) fit the mounting plate with 10 mm between parts | The layout is drawn for these sizes | FCL-DDR-003, P11 |
| 5 | The battery case has a flat end wall for two M25 glands 150 mm up, and room beside the pack for the class T fuse holder (about 60 x 50 x 45 mm) | The fuse must be within 150 mm of the positive terminal | FCL-DDR-003, P11, P12 |
| 6 | The piano hinge leaves are about 26 x 1.5 mm and the knuckle no more than 8 mm across | The pin sits 4.5 mm above the panel face; a bigger knuckle needs more | FCL-DDR-003, P6 |
| 7 | The over-centre latch and its keeper close on the 12 mm the model allows | Sets the tie bar length (731 mm) | FCL-DDR-003, P9 |
| 8 | The inverter's derating at 45 °C, no-load draw of 10 W or less, and fan noise | R9, R4 and R11 rest on these figures | FCL-DDR-002, A4; FCL-CAL-001 [D6], [I2] |
| 9 | The pack's battery management system peak rating and the class T fuse curve cover about 118 A for a few seconds; charging blocked below 0 °C and above 45 °C | Surge with full DC load | FCL-CAL-001 [B2] |
| 10 | Supplier quotes for the pack, the wings and the inverter | They replace the indicative prices and show the real cost against the value-engineering target | FCL-DDR-002, A1 |

## Value engineering

Value-engineering target: USD 2,100 (a hypothetical control target, not a limit). Estimated cost of the constructable design: USD 2,101 (USD 1 over the target). Main cost drivers and savings worth trying:

- The largest lines are the two PV wings (USD 460), the pack (USD 300) and the inverter (USD 220).
- Making the design buildable took the BOM from USD 2,051 to USD 2,101: frame steel +USD 12, wheel collars and linch pins +USD 5, outrigger brackets +USD 6, two latches fewer and new fixings -USD 6, cam straps and PV glands +USD 15, shade uprights +USD 9 and tie bars +USD 9.
- The USD 1 gap is well inside the accuracy of indicative prices. Supplier quotes for the pack, wings and inverter are the first saving to try.
- Webbing straps with cam buckles in place of the tie bars were the other place to look for a small saving; the tie bars were kept on 2026-10-02.

## Decisions made

*Table 2. Decisions made.*

| Date | Decision | Decided by | Record |
| --- | --- | --- | --- |
| 2026-09-25 | TRL 2 review items D1 to D8: 25.6 V 50 Ah pack, fixed east-west wings at 15° as the cart walls, 24 V class panels in parallel, 120 V 60 Hz first, welded steel frame and flat-free tyres, SwapCell as a future variant only, budget held until quotes, disaster response first | Amish: "proceed with all of your recommendations across all batches. Make sure we don't proceed to TRL 4 on any of them." | FCL-DDR-001 |
| 2026-09-25 | Budget raised to $2,100; R6 limit relaxed to 75 kg; thermostat filter fan; reflective sun shade; 20 mm hinge spacer; "peak sun hours" read as global horizontal irradiation; heavy parts low and over the axle | Amish: "i accept all your recommendations, go with them across all repos." | FCL-DDR-002 |
| 2026-09-25 | TRL 4 on hold: no building, testing or purchasing | Amish, same instruction as D1 to D8 | FCL-DDR-001 |
| 2026-09-26 | FieldCell chosen for the first batch of product renders | Amish (words not recorded) | `docs/REVIEW.md`, session 2026-09-26 |
| 2026-09-30 | Make the design physically buildable while drawing the build plan; record outstanding decisions in this register, not in the build plan. The changes made under this instruction (FCL-DDR-003) are open for Amish's review (Table 1, item 1) | Amish: "If you are realising that the design cannot be built as per concept - fix the design assumptions to match and be physically feasible as you draw the illustrations." and "don't log outstanding decisions in this build plan - that is not the place for it. that should be in a separate design document logged and named as such" | FCL-DDR-003 (Draft) |
| 2026-10-02 | Design for construction accepted: the changes P1 to P13 as made (open item 1) | Amish: "i approve your recommendations for all 555 open decisions." | FCL-DDR-003, Table 1 |
| 2026-10-02 | Mass and pull: steel frame and flat-free tyres kept; R6 set at 82 kg and the R7 grass pull at 160 N (sharpened from the 80 kg first proposed, to keep a margin); the prototype is weighed at TRL 4 and moves to the bolted aluminium frame (option b) if it is over 82 kg (open item 2) | Amish: "i approve your recommendations for all 555 open decisions." | FCL-DDR-003, A1; FCL-CAL-001 [E3], [E5], [F1]; FCL-REQ-001 R6 and R7 |
| 2026-10-02 | Stowed wings held by the two tie bars with over-centre latches, as modelled (option a) (open item 3) | Amish: "i approve your recommendations for all 555 open decisions." | FCL-DDR-003, A3 |
| 2026-10-02 | The shade lifts off on four wing bolts to open the battery case, for service only (option a) (open item 4) | Amish: "i approve your recommendations for all 555 open decisions." | FCL-DDR-003, A4 |
| 2026-10-02 | Seek a responder organization now, for a paper review of the deployment sequence and load profile only; first candidate to approach a US volunteer disaster response organization such as Team Rubicon, since the first build is 120 V 60 Hz (open item 5) | Amish: "i approve your recommendations for all 555 open decisions." | FCL-DDR-001, O1 |
| 2026-10-02 | Positioning: FieldCell is the mobile field-site unit (PV only, 1 kW AC, one-person cart, own 25.6 V pack), PowerBox the household outage unit (multi-input, indoor, SwapCell pack) and SwapCell the shared pack standard; one paragraph saying so goes in each README (open item 6) | Amish: "i approve your recommendations for all 555 open decisions." | FCL-DDR-001, O2 |
| 2026-10-02 | No AC charger; the vehicle 12 V input is left out of the first prototype and may be offered later as a DC-to-DC charging option if the responder review asks for it (open item 7) | Amish: "i approve your recommendations for all 555 open decisions." | FCL-DDR-001, O3 |
| 2026-10-02 | Appearance model rebuilt from the constructable model and re-rendered on Amish's Mac, with the clear side window as a render aid only (option a) (open item 8) | Amish: "i approve your recommendations for all 555 open decisions." | `docs/REVIEW.md`, sessions 2026-09-26 and 2026-10-01; FCL-DDR-003 |

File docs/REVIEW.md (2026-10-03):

# Review note: FieldCell

## Session 2026-09-24: /populate to a strong TRL 2

### What was done

- `docs/01-problem.md` (FCL-PRB-001 v0.2): the problem, users and context, constraints, out of scope, prior work (described without links), open questions.
- `docs/03-requirements.md` (FCL-REQ-001 v0.2): 12 measurable requirements (R1 to R12) with targets, concept estimates and planned verification.
- `docs/02-concept.md` (FCL-PRC-001 v0.2): how it works, 17-item component table, first-order numbers (PV yield, load profile and autonomy, mass and center of gravity, deploy time, wind), design choices, safety, open questions.
- `cad/src/concept_media.py`: massing model (frame and axle, two wheels, handle, stand legs, battery enclosure and pack, electronics enclosure with MPPT, inverter, outlets and fusing, two PV wings deployed on hinges and outrigger legs, accessory bin). The hero also shows the same cart stowed for travel. The script computes and prints the mass budget, center of gravity and energy flow.
- `media/`: hero with the 1.75 m figure, blueprint sheet FCL-DWG-001 (PNG and PDF), cutaway, exploded view with BOM callouts, energy flow diagram (estimates marked), `model.glb` and `viewer.html`.
- `bom/bom.csv`: 17 lines with indicative prices, numbered to match the exploded view; `bom/bom-notes.md`.
- `README.md`: hero image and links line.
- `docs/pdf/`: branded PDFs of the three controlled documents.

### Key results (estimates, to be checked at TRL 3)

| Quantity | Estimate | Requirement |
| --- | --- | --- |
| Stored energy | 1.28 kWh nominal, about 1.15 kWh usable | R1 met |
| PV into battery | 1.12 to 1.40 kWh/day at 4 to 5 peak sun hours (0.754 array derating) | R3 met, thin at 4 h |
| Autonomy, 0.9 kWh/day reference load | about 1.1 days with no sun; about 9 % surplus at 4 h | R4 met, thin |
| Deploy time | about 6 min, one person | R5 met |
| Mass | about 68.5 kg against a 70 kg limit | R6 met, thin |
| Center of gravity | about 63 mm toward the handle from the axle; handle force 17 to 52 N | R6 met |
| Pull force, 10 % grade | about 110 to 135 N against 150 N | R7 met, thin |
| Lateral tip angle | about 32 degrees | R7 met |
| Parts cost | about $1,462 against $1,500 | R12 met, 2.5 % margin |

Requirements not met or not yet shown:

- **R10 (wind):** unstaked wings may lift at about 9 m/s. The requirement is met only with the four outrigger feet staked or ballasted.
- **R8 and R9 (weather and temperature):** design intent only. Venting the inverter heat while keeping the electronics box IP54 is unresolved.
- **R11 (noise):** depends on the inverter fan; unverified.
- Several margins are thin (R3, R4, R6, R7, R12). The energy balance at 4 peak sun hours is the main technical risk.

### Proposed, awaiting Amish

1. Battery system voltage: 25.6 V 50 Ah (recommended), 12.8 V 100 Ah, or 51.2 V. **Decided by Amish, 2026-09-25: go with recommendation** (FCL-DDR-001).
2. Wing layout: fixed east-west wings at 15 degrees (recommended, fastest), or detachable panels on kickstands aimed at the sun (about 10 to 15 % more energy, 3 to 5 min slower). **Decided by Amish, 2026-09-25: go with recommendation** (FCL-DDR-001).
3. Panels: 24 V class (Vmp about 36 V) wired in parallel into one MPPT (recommended), rather than 12 V class panels in series. **Decided by Amish, 2026-09-25: go with recommendation** (FCL-DDR-001).
4. AC output: 120 V 60 Hz for the first build (recommended), with a 230 V 50 Hz variant documented. **Decided by Amish, 2026-09-25: go with recommendation** (FCL-DDR-001).
5. Frame and wheels: welded steel with flat-free tyres (recommended for a garage build and debris), or bolted aluminium (about 4 to 5 kg lighter) and pneumatic tyres. **Decided by Amish, 2026-09-25: go with recommendation** (FCL-DDR-001).
6. SwapCell: record compatibility with a SwapCell 48 V pack as a future variant only; the concept is not designed around it. **Decided by Amish, 2026-09-25: go with recommendation** (FCL-DDR-001).
7. Budget: keep $1,500 (parts about $1,462, no contingency) or raise to about $1,750 to cover price variation, stakes, tools and spares. Recommendation: keep $1,500 for now and decide after supplier quotes at TRL 3. `project.yaml` is unchanged. **Decided by Amish, 2026-09-25: go with recommendation** (FCL-DDR-001). Superseded by FCL-DDR-002 A1 ($2,100).
8. First user group: disaster response (recommended), humanitarian field teams or remote crews; and whether to seek a responder organization to review the deployment sequence. First user group: disaster response,**Decided by Amish, 2026-09-25: go with recommendation** (FCL-DDR-001). Responder organization: no recommendation, stays Proposed, awaiting Amish.
9. Portfolio overlap: how FieldCell relates to PowerBox and SwapCell. No recommendation; stays Proposed, awaiting Amish.

### Safety concerns

- 1.28 kWh lithium pack: BMS with low-temperature charge cutoff, class T fuse at the terminal, secured and vented enclosure; shipping is regulated as dangerous goods.
- 120 V or 230 V AC output outdoors: GFCI or 30 mA RCD on every outlet, neutral bonding per the inverter maker, in-use covers.
- Must never be connected to building wiring; there is no inlet, and back-feed is a lethal hazard to utility workers.
- PV is live whenever lit (about 45 V open circuit per panel).
- 68 kg cart: two-person lift into vehicles; tipping on cross-slopes; wing lift in wind; pinch points at hinges and latches.
- Heat build-up in a sealed electronics box.

### Recommended next step

Review this note and the media, and decide the proposals above, especially items 1 to 3 and 7. If approved, run `/advance-trl3` to check the PV yield, energy balance, thermal and wind loads by calculation, and to produce the parametric model and drawing sheet.

## Session 2026-09-25: TRL 3

Amish's instruction for this session (2026-09-25): "proceed with all of your recommendations across all batches. Make sure we don't proceed to TRL 4 on any of them." FieldCell now claims TRL 3 (proof of concept on paper). TRL 4 is on hold by Amish's instruction.

### What was done

- `docs/decisions/0001-trl2-review-decisions.md` (FCL-DDR-001 v0.1): the eight TRL 2 review items with a recommendation recorded as decided by Amish, 2026-09-25, and five items that stay open.
- `docs/04-calcs/01-sizing.md` (FCL-CAL-001 v0.1) and `docs/04-calcs/sizing.py`: first-principles sizing with stated assumptions: stored energy; battery current, cable, PV voltage window; a clear-sky transposition model for the east-west wings at 15, 30 and 45° N; temperature derating; load and autonomy; mass and center of gravity from the model's tube geometry; pull force, step climb, tip angle and frame and axle stress; enclosure and battery thermal estimates; wind on the wings and the cart; deploy and stow time; noise; BOM total. The script imports the model's `PARAMS` and prints every number the note quotes, tagged [A1] to [K1].
- `cad/src/model.py`: parametric build123d model (frame of hollow tube, axle, wheels, handle, legs, enclosures with filter fan, contents, hinged PV wings deployed or stowed, outriggers, bin), exporting `cad/step/fieldcell-deployed.step`, `fieldcell-stowed.step`, `frame.step`, `pv-wing.step`, `battery-enclosure.step`, `electronics-enclosure.step` and matching STL files in `cad/stl/`.
- `cad/src/sheets.py` and `cad/drawings/FCL-DWG-002.svg`, `.pdf`, `.png`: general arrangement at Rev P1, scale 1:25, with overall dimensions drawn from the model, the stowed cart in the isometric view and a main-dimensions box. The sheet carries "CONCEPT, NOT FOR FABRICATION" and "PRELIMINARY, NOT FOR FABRICATION". The concept sheet remains FCL-DWG-001.
- `bom/bom.csv` and `bom/bom-notes.md`: all 17 lines priced with a supplier type; total $2,006 against the $1,500 budget.
- `cad/src/concept_media.py` now builds the media from `model.py` and takes its figures from the calc script; all media in `media/` were regenerated and checked by eye; temporary `media/_views*` folders were deleted.
- FCL-PRB-001, FCL-PRC-001 and FCL-REQ-001 revised to v0.3 (decisions recorded, numbers replaced by FCL-CAL-001, requirement status column); `README.md` updated to TRL 3 with links; `project.yaml` set to `trl: 3`, `trl_target: 3`, with the evidence files listed. PDFs are in `docs/pdf/`.

### Requirements (FCL-CAL-001, Table 8)

6 met, 2 not met, 2 at risk, 2 not verifiable at TRL 3.

| ID | Status | Value against target |
| --- | --- | --- |
| R6 | **Not met** | 73.5 kg against 70 kg. Handle force 14 to 50 N and 12 kg pack are within limits. The decided steel frame (12.8 kg) and flat-free wheels (8 kg) are the cause; TRL 2 budgeted 68.5 kg |
| R12 | **Not met** | Parts $2,006 against $1,500 (+34 %). Safety provisions met by design |
| R7 | At risk | Pull force 144 N on grass on a 10 % grade against 150 N; step climbed with about 136 N at the grip; clearance 193 mm; tip 32.9° |
| R9 | At risk | Electronics box about 54 °C at 45 °C ambient at 1 kW with a filter fan (70 °C sealed); battery case in noon sun about 10 K above ambient, so charging is blocked in the hottest hours |
| R8 | Not verifiable at TRL 3 | IP54 enclosure with IP54 filter fan and filter, IP65 case, by selection |
| R11 | Not verifiable at TRL 3 | About 41 dB(A) at 1 m from assumed fan levels |
| R1 | Met | 1.28 kWh nominal, 1.15 kWh usable |
| R2 | Met | 1 kW AC, 440 W DC; 66 A continuous on a 100 A fuse |
| R3 | Met | 1.17 kWh/day into the battery at 4 kWh/m²/day GHI (1.09 in 40 °C air); full recharge 0.79 day at 5 |
| R4 | Met | 1.08 days with no sun; +10 % surplus at 4 kWh/m²/day; break-even at 3.64 |
| R5 | Met | 6.0 min deploy, 5.0 min stow by task analysis |
| R10 | Met | Staked: 27 N pull-out per foot at 15 m/s (49 N factored); unstaked wings lift at 9.2 m/s |

Other key numbers: east-west penalty about 14 % against a south-aimed panel (10 % was assumed at TRL 2); PV Vmp headroom at 70 °C cell only 0.9 V above what the MPPT needs; deployed wing to tyre clearance 8 mm; stowed cart overturns in about 20 m/s side wind; stowed size with the handle off 1,400 x 784 x 1,170 mm. Every TRL 2 number in the docs was checked against the script and corrected where it differed (FCL-CAL-001, "Checks against earlier figures").

### Decisions recorded (FCL-DDR-001)

Decided by Amish, 2026-09-25, going with the recommendation: D1 25.6 V 50 Ah battery; D2 fixed east-west wings at 15° (wings as cart walls); D3 24 V class panels in parallel; D4 120 V 60 Hz first, 230 V variant documented; D5 welded steel frame and flat-free tyres; D6 SwapCell as a future variant only (a future variant would cite SwapCell interface v0.3 items: wake without CAN, charge-while-discharging, latch vibration rating); D7 keep `budget_usd` at $1,500 until supplier quotes; D8 disaster response as the first user group. No requirement target was relaxed; `budget_usd` is unchanged.

### Proposed, awaiting Amish

Still open from TRL 2 (no recommendation was made):

1. Whether to seek a responder organization to review the deployment sequence and load profile, and which one (O1).
2. How FieldCell relates to PowerBox and SwapCell in the portfolio (O2).
3. Whether to add an AC charger or a vehicle 12 V input for cloudy periods (O3).
4. Heavy parts low and over the axle as a layout rule (O4); recommendation: keep it. **Decided by Amish, 2026-09-25: go with recommendation** (FCL-DDR-002).

New from TRL 3:

5. **Budget (R12).** Options: (a) raise `budget_usd` to about $2,100 (BOM plus about 5 % contingency); (b) cost-down to about $1,600 with generic inverter, MPPT and monitor, at a risk to idle draw, noise and reliability; (c) keep $1,500 and cut the PV to one wing, which breaks R3 and R4. Recommendation: (a), after quotes for the pack, the PV wings and the inverter. `project.yaml` is unchanged. **Decided by Amish, 2026-09-25: go with recommendation** (FCL-DDR-002). `budget_usd` is now 2,100.
6. **Mass (R6).** Options: (a) relax the R6 mass limit to 75 kg, keeping the decided steel frame and flat-free tyres (the handle force is what one person feels, and it stays within limits; the cart is a two-person lift either way); (b) change to a bolted aluminium frame, about 67.4 kg, which reverses D5 and adds cost; (c) pneumatic tyres, about 71.1 kg, still over. Recommendation: (a), with a note that R7 pull force on grass is then at its limit. **Decided by Amish, 2026-09-25: go with recommendation** (FCL-DDR-002). R6 limit is now 75 kg.
7. **Electronics box ventilation (R8, R9).** Adopt a thermostat-controlled IP54 filter fan (40 to 60 m³/h) with an IP54 exhaust filter, already priced in BOM line 7 and modeled. Recommendation: adopt. **Decided by Amish, 2026-09-25: go with recommendation** (FCL-DDR-002).
8. **Sun shade (R9).** Add a light reflective shade over the battery and electronics enclosures when deployed (about $30 and 1 kg, not yet in the BOM or model), and obtain inverter derating data at 45 °C. Recommendation: add at the next revision. **Decided by Amish, 2026-09-25: go with recommendation** (FCL-DDR-002). Shade added; derating data on hold with supplier selection.
9. **Hinge spacer.** Raise each hinge line by a 20 mm spacer to open the 8 mm wing-to-tyre clearance. Recommendation: adopt; the model's `hinge_z` parameter is left at 470 mm until decided. **Decided by Amish, 2026-09-25: go with recommendation** (FCL-DDR-002). `hinge_z` is now 490 mm.
10. **"Peak sun hours" basis (R3, R4).** Read as daily global horizontal irradiation in kWh/m²/day, as FCL-CAL-001 does. Recommendation: confirm. **Decided by Amish, 2026-09-25: go with recommendation** (FCL-DDR-002).

### Safety concerns

- 1.28 kWh LiFePO4 pack: class T fuse at the terminal, BMS with low- and high-temperature charge cutoff; the pack can reach about 55 °C in noon sun at 45 °C ambient, so shading matters. Dangerous-goods rules for shipping.
- 120 V AC outdoors: GFCI on every outlet, neutral bonding per the inverter maker, in-use covers; no inlet and no connection to building wiring, ever.
- DC surge: 2 kW surge with full DC load is about 118 A for seconds; the BMS peak rating and fuse curve must be confirmed.
- PV is live whenever lit (about 45 V, up to about 50 V cold).
- 73.5 kg cart: two-person lift; tipping on cross-slopes; wing lift above about 9 m/s unstaked; stowed cart can blow over at about 20 m/s; pinch points at hinges, latches and the 8 mm wing-to-tyre gap.
- Heat: up to about 140 W inside the electronics box at 1 kW; a sealed box would reach about 70 °C at 45 °C ambient.

### Other notes

- No existing TRL 4 material was found (`build-log/` holds only its README; `electronics/` and `firmware/` are empty). None was created. STANDARDS section 9 asks for a TRL change to be recorded in the build log; no build-log entry was written this session, since the brief did not name one.
- No unchecked citations were listed at TRL 2 (prior work is described without links), so no web verification was needed. BOM prices are indicative estimates by supplier type, not quotes.
- The deliverable list in `.claude/commands/advance-trl3.md` names the drawing DWG-001; because the concept sheet already uses FCL-DWG-001, the general arrangement is FCL-DWG-002, as this session's brief directs.

### Recommended next step

Stay at TRL 3. TRL 4 is on hold by Amish's instruction. Decide items 5 to 10 above, starting with the budget and the mass limit, and get supplier quotes for the pack, the PV wings and the inverter (including idle draw, fan noise and 45 °C derating data), then revise FCL-CAL-001 and the BOM on paper.

For reference only, TRL 4 would need: a lab test report (TST, `environment: lab`) on a built cart or key subassemblies (PV yield logged against irradiance, inverter idle draw and enclosure temperature at 1 kW, noise at 500 W, mass and handle force, deploy and stow timed trials, wing lift and stake pull-out), build-log entries, and the purchasing and build work that goes with them. None of this has been started.

## Session 2026-09-25: recommendations accepted

Amish wrote on 2026-09-25: "i accept all your recommendations, go with them across all repos." Every open item with a recommendation is now **Decided by Amish, 2026-09-25: go with recommendation**, recorded in `docs/decisions/0002-recommendations-accepted.md` (FCL-DDR-002 v0.1). The TRL 2 items above are also marked decided (FCL-DDR-001, now v0.2).

### Decisions applied and what changed

| # | Decision | Before | After |
| --- | --- | --- | --- |
| A1 | Raise the budget (option a) | `budget_usd` $1,500; BOM $2,006, 34 % over | `budget_usd` $2,100; BOM $2,051, $49 (2.4 %) contingency |
| A2 | Relax the R6 mass limit (option a) | 70 kg limit; 73.5 kg | 75 kg limit; 75.06 kg after A4 and A5 |
| A3 | Adopt the thermostat IP54 filter fan | Proposed, already in BOM item 7 and the model | Decided; R8 wording names it |
| A4 | Add a reflective sun shade | None; pack about 55 °C, box about 54 °C at 45 °C ambient and 1 kW | BOM item 18 ($30, 1 kg) and model part; pack about 48 °C, box about 53 °C |
| A5 | 20 mm hinge spacer | `hinge_z` 470 mm; wing to tyre 8 mm; stowed height 1,170 mm; BOM item 14 $45 | `hinge_z` 490 mm; 28 mm; 1,190 mm; $60 with two aluminium angles (0.53 kg) |
| A6 | "Peak sun hours" is GHI in kWh/m²/day | Assumption, proposed | R3 and R4 restated in kWh/m²/day GHI |
| A7 | Heavy parts low and over the axle | Proposed (O4) | Kept as a layout rule |

Other knock-on numbers (FCL-CAL-001 v0.2): CG height 557 to 564 mm; handle force 14 to 50 N to 14 to 52 N; tip angle 32.9 to 32.6°; pull on grass 144 to 147 N; step pull 136 to 138 N. Energy, electrical, wind lift, deploy and noise figures are unchanged.

Files changed: `project.yaml`, `README.md`, `bom/bom.csv`, `bom/bom-notes.md`, `cad/src/model.py` (and all STEP and STL files), `cad/src/sheets.py` and `cad/drawings/FCL-DWG-002.*` (Rev P2), `cad/src/concept_media.py` and all of `media/`, `docs/04-calcs/sizing.py` and FCL-CAL-001 v0.2, FCL-PRB-001 v0.4, FCL-PRC-001 v0.4, FCL-REQ-001 v0.4, FCL-DDR-001 v0.2, FCL-DDR-002 v0.1. PDFs in `docs/pdf/` were rebuilt, and the older-version PDFs removed.

### Requirement status (FCL-CAL-001 v0.2)

7 met, 1 not met, 2 at risk, 2 not verifiable at TRL 3 (before: 6 met, 2 not met).

| ID | Status | Value against target |
| --- | --- | --- |
| R6 | **Not met** | 75.06 kg against 75 kg (0.06 kg over, within estimate accuracy); handle force 14 to 52 N; pack 12 kg |
| R7 | At risk | Pull 147 N on grass against 150 N; step at 138 N; clearance 193 mm; tip 32.6° |
| R9 | At risk | Box 53 °C at 45 °C ambient with fan and shade; pack about 48 °C under the shade, so charging stops above about 42 °C ambient; inverter derating data not yet obtained |
| R8 | Not verifiable at TRL 3 | IP54 box with decided filter fan; IP65 case |
| R11 | Not verifiable at TRL 3 | About 41 dB(A) at 1 m from assumed levels |
| R1, R2, R3, R4, R5, R10, R12 | Met | As before; R12 now met at $2,051 against $2,100 |

### Proposed, awaiting Amish

Still open, no recommendation was made:

1. Whether to seek a responder organization to review the deployment sequence and load profile, and which one (O1).
2. How FieldCell relates to PowerBox and SwapCell in the portfolio (O2).
3. Whether to add an AC charger or a vehicle 12 V input for cloudy periods (O3).

New from this session:

4. **Close the 0.06 kg R6 gap.** Options: (a) specify the sun shade at 0.9 kg or less (fabric on a lighter frame), which meets R6 with about 0.04 kg margin; (b) set the limit at 76 kg; (c) accept the figure as within estimate accuracy and settle it by weighing at TRL 4. Recommendation: (a), since it costs nothing and leaves the decided frame and tyres untouched.

### Cross-repo actions

None. No decision in this session needs a change in another repo (D6 on SwapCell was settled in FCL-DDR-001).

### Safety concerns

Unchanged from the TRL 3 session, with two updates: the cart is now about 75 kg (two-person lift), and the deployed wing to tyre gap is 28 mm instead of 8 mm, which reduces but does not remove the pinch point. The shade must stay in place in hot weather to keep the pack below its charge limit.

### TRL 4

TRL 4 remains on hold by Amish's instruction. `trl: 3` and `trl_target: 3` are unchanged. Supplier quotes, inverter derating data from a chosen supplier, building, weighing and testing are recorded as decided or needed but not started.

### Recommended next step

Decide item 4 above. Otherwise stay at TRL 3 until Amish lifts the TRL 4 hold.

## Session 2026-09-26: sources strengthened

- "Where it could be used", country table: the uncited "Caribbean and Central America" row is replaced by "Caribbean (Puerto Rico and US Virgin Islands)", citing US GAO report GAO-19-296 (2019): after Hurricanes Irma and Maria, restoring power to all customers with structures safe for reconnection took about 11 months in Puerto Rico and about 5 months in the US Virgin Islands. Old source: none. The link was opened on 2026-09-26.
- All other rows, "Concept rationale", "Burning platform" and "What sparked the idea" already rested on primary or reputable secondary sources and are unchanged. No budget change. No controlled doc changed.

## Session 2026-09-26: product appearance model and photoreal renders

Amish chose FieldCell for the first batch of product renders on 2026-09-26. This session adds an appearance model for photoreal product renders. It changes no controlled document, no parameter in `cad/src/model.py`, no BOM line and no budget figure.

### What was done

- `cad/src/product_model.py` (new): `product_parts()` returns 100 named parts with colour, material, BOM line, group and explode offset, built from `PARAMS`, `derived()` and the model.py geometry. It also defines `TITLE` and `RENDER_VIEWS` (hero, exploded, detail). What it adds over the massing model:
  - Graphite powder-coated frame with tube end plugs and an expanded-metal deck pattern; axle brackets with rounded ends.
  - Flat-free tyres with rounded shoulders and a staggered tread, dished steel rims with lightening holes, hub caps.
  - T-handle with a foam grip, end caps and quick-release pins; stand legs with clamp blocks and rubber feet.
  - PV wings as a finished module: 8 x 4 cell grid with clipped corners and busbars on a white backsheet, aluminium backing frame with ribs, teal corner guards, junction box underneath.
  - Knuckled continuous hinges on the 20 mm spacer; outrigger feet with stake loops and stakes.
  - Sun shade as reflective fabric on an aluminium flat-bar frame with posts and clips.
  - Battery case with lid parting line, lid ribs, four latches, carry handle, pressure vent, rating label and gland plate; LiFePO4 pack with terminal covers and label.
  - Electronics box with lid parting line, lid screws, louvered intake fan and exhaust filter grilles, a teal rating label and a clear side window onto the finned inverter, the MPPT on its heat sink and the DC breakers and class T fuse on a DIN rail.
  - Outlet face toward the handle: DC panel with two USB-C PD ports (lit rings), two 12 V sockets with rubber caps and the lit battery monitor; GFCI duplex with test and reset buttons under a clear in-use cover; battery isolator knob; inverter rocker with a lit indicator.
  - Two battery cables with glands between the battery case and the electronics box; accessory bin with rim lip, teal webbing tie-down strap, buckle and a coiled cord.
  - Context: a compact ground patch and the shared clay mannequin (1.75 m, "stand") beside the handle end.
- Views: hero (front right, about 30 deg elevation, deployed on the ground patch with the person), exploded (front right, about 28 deg) and detail (front right, about 22 deg, power system only: outlet face, side window and battery case). For the detail view to frame the power system closely, the battery case, pack, electronics box, its contents, outlet face and cables are in group "internal"; the cart, wings, shade and bin are in "shell".
- `README.md`: hero image now points to `media/render-hero.png`, with a link to `media/render-exploded.png`. The render files are produced separately.

### Where the appearance model differs from model.py

Each item is Proposed, awaiting Amish.

1. **Hinge spacer tabs.** In model.py the hinge spacer (y 320 to 340 mm) does not touch the side rail (outer face at y 300 mm). The appearance model bridges the gap with four aluminium tabs per side. Recommendation: add the tabs (or move the spacer inboard onto the rail) at the next model revision.
2. **In-use cover depth.** The clear weatherproof cover over the GFCI outlet stands 38 mm proud of the box face, against the 12 mm outlet envelope in model.py. Recommendation: accept and enlarge the envelope; it stays clear of the handle.
3. **Isolator, inverter switch and monitor locations.** model.py does not place the battery isolator, the inverter switch or the shunt monitor. The appearance model puts the isolator knob and inverter rocker (with indicator) on the outlet face between the AC and DC panels, and the monitor at the top of the DC panel. Recommendation: adopt, since the concept requires the isolator reachable without tools.
4. **Electronics box side window.** The render shows a clear window in the front (-Y) wall to show the internals; the BOM enclosure has none. Recommendation: treat it as a render aid only, unless a windowed IP54 enclosure is found at a similar price, because a window adds solar gain to a box already at risk on R9.
5. **Battery cables and glands (item 17, not modeled).** Drawn as two cables between facing walls of the battery case and the electronics box, 120 mm above the deck. Recommendation: accept as the indicative route.
6. **Stake loops.** The outrigger stake loops stand about 26 mm outside the 80 mm foot plates. Recommendation: accept; the deployed footprint change is negligible.

### TRL

This is an appearance model only: no tolerances, no fabrication detail, concept, not for fabrication. `trl` stays 3 and TRL 4 remains on hold.

## Session 2026-09-27: kit 1.5.0 and image quality

- Kit 1.5.0 synced: STANDARDS v1.5 (sections 12 to 15: product renders, storefront images and image quality, public release, authorship and signing), `.kit/cards.py`, `.kit/image_qc.py`, `.kit/release_gate.py`, issue templates, and the `/render-product` and `/release` commands. `CLAUDE.md` now matches `.kit/CLAUDE.md`.
- Every `media/render-*.png` recaptioned from its original render with the new layout: the title, concept label and repository sit in a band above the render and the view note in a band below it, each line wrapped to the image width, so no text overlaps other text or the render or runs off the image. `media/card.png` and `media/social-preview.png` regenerated with the same rules.
- `python .kit/image_qc.py` and `python .kit/release_gate.py` pass. trl stays 3.

## Session 2026-10-01: kit 1.7.0, constructable design and prototype build plan

Kit 1.7.0 installed (`.kit/`, `.claude/commands/`; `CLAUDE.md` now matches `.kit/CLAUDE.md`). Following Amish's 2026-09-30 instruction ("If you are realising that the design cannot be built as per concept - fix the design assumptions to match and be physically feasible as you draw the illustrations."), the design was checked part by part in build123d, made buildable, and the illustrated build plan and the design decisions register were written. `design_state: constructable` is set in `project.yaml`. `trl` stays 3.

### Design changes made for construction (FCL-DDR-003, Draft, open for Amish's review)

1. Deck: expanded steel sheet laid on the cross tubes between the rails (it cut 5 mm into them); tubes 5 mm lower, deck top still 460 mm.
2. Rail ends capped with 3 mm plates.
3. Axle brackets: 60 x 5 mm plates stopping under the rails (they cut 10 mm into them), braced by 5 mm gussets; 820 mm welded axle through wheel bores, with spacer collars, washers and linch pins.
4. Stand legs: on welded 3 mm clevis pairs under the rail centre line, M10 pivot, detent pin, folding along the rail (they had no pivot).
5. Handle: two welded 33.7 mm sockets with gussets on the rail ends at 30.5°, legs pinned in them (the concept had no joint).
6. Hinge line: eight steel tabs welded to the rails carry the decided 20 x 20 x 2 mm spacer angle (it stood 20 mm clear of the rails); a real 1.2 m piano hinge, pin 4.5 mm above the panel face so the wing lies where the concept put it (28 mm over the tyre).
7. Wings: module bonded to a 1,400 x 700 mm frame of 30 x 20 x 1.5 mm aluminium tube with three ribs (a solid block in the concept); about 6.0 kg each.
8. Outrigger legs: riveted U brackets under the wing's outer member, M8 pivot, 50 mm feet with stake loops along the cart; fold flat under the wing.
9. Two tie bars hold the stowed wings together at the top with over-centre latches (the latches had nothing to latch to, since the stowed wing's inner face is the solar module); two latches instead of four.
10. Sun shade: on four 355 mm uprights bolted to tabs on the rails (the posts stood in mid air); frame 830 x 580 mm; lifts off to open the battery case.
11. Electronics: inverter, charge controller and DIN rail side by side on the mounting plate (the fusing sat on the charge controller); outlets, isolator, fan and exhaust filter through cut-outs; class T fuse moved into the battery case within 150 mm of the terminal; isolator on the outlet face.
12. Electronics box 10 mm nearer the handle so 60 mm separates the boxes (50 mm could not take two M25 gland domes); two M25 glands each side, two M16 PV glands.
13. Fixings: cam straps over the battery case, four floor bolts for the electronics box, bin strap through the deck.

`cad/src/model.py` now runs 96 constructability checks in the parked and travel poses (`--check`); all pass. STEP and STL regenerated in `cad/step/` and `cad/stl/`.

### Files

- New: `docs/05-build-plan.md` (FCL-BLD-001 v0.1), `docs/06-design-decisions.md` (FCL-DEC-001 v0.1), `docs/decisions/0003-design-for-construction.md` (FCL-DDR-003 v0.1), `cad/src/build_plan_media.py`, `cad/drawings/FCL-DWG-101` to `111` (11 making sketches), `docs/05-build-plan/` (overview, 9 joint close-ups, 17 step pictures, frame layout, electronics box cut-outs, wiring).
- Changed: `cad/src/model.py`, `cad/src/concept_media.py` (BOM groups, wing group drawn to the front in the exploded view), `cad/src/sheets.py` and `cad/drawings/FCL-DWG-002` (Rev P4), all `media/` concept images, `media/model.glb`, `docs/04-calcs/sizing.py`, FCL-CAL-001 v0.3, FCL-PRC-001 v0.5, FCL-REQ-001 v0.5, `bom/bom.csv` (line 19 added), `bom/bom-notes.md`, `project.yaml`, `README.md` (links line and "Building the prototype").

### Key results (FCL-CAL-001 v0.3)

- Mass 75.06 to 79.99 kg: R6 **not met** by 5.0 kg. Handle force 14 to 54 N.
- Pull on a 10 % grass grade 147 to 156 N: R7 **not met** (was at risk). Step pull 149 N.
- BOM $2,051 to $2,101: R12 **over the value-engineering target** by USD 1. Safety provisions met by design.
- Deploy 6.5 min, stow 5.5 min (R5 met); unstaked wing lift 8.9 m/s; stowed size 1,400 x 830 x 1,220 mm; wing-to-tyre 28 mm unchanged.
- Status: 6 met, 2 not met (R6, R7), 1 over its value-engineering target (R12), 1 at risk (R9), 2 not verifiable at TRL 3 (R8, R11).

### Proposed, awaiting Amish

All open decisions are now in the design decisions register (`docs/06-design-decisions.md`): accepting FCL-DDR-003; mass and pull (relax to 80 kg and 160 N, or an aluminium frame); tie bars or straps; shade lift-off; O1 to O3 from FCL-DDR-001; and updating the appearance model and renders. The 2026-09-25 item "close the 0.06 kg R6 gap" is superseded by the mass decision. The budget is not a decision: `budget_usd` stays $2,100 as a value-engineering target, and the savings worth trying are in the register's Value engineering section (2026-10-01 wording pass).

### Stale until regenerated on Amish's Mac

The appearance model was rebuilt on 2026-10-02 (see the section "Approved follow-ups carried out"). The photoreal renders, `media/card.png` and `media/social-preview.png` are made on Amish's Mac next and are not in this working copy.

### Safety concerns

The cart is now about 80 kg: a two-person lift. The class T fuse is inside the battery case, so pulling the fuse means lifting the shade and opening the case; the isolator on the outlet face remains the everyday disconnect. Unstaked wings lift at about 9 m/s. Tie bars must be latched for travel.

### Recommended next step

Amish to review FCL-DDR-003 and decide items 1 and 2 of the register (accept the construction changes, the mass and pull gap). TRL 4 stays on hold.

## Session 2026-10-02: open decisions decided

Amish approved every recommendation for the open decisions on 2026-10-02: "i approve your recommendations for all 555 open decisions."

### Decisions recorded

Eight, all moved to "Decisions made" in FCL-DEC-001 (open items 1 to 8): design for construction accepted (FCL-DDR-003, P1 to P13); steel frame and flat-free tyres kept with R6 set at 82 kg and the R7 grass pull at 160 N, the prototype weighed at TRL 4 and moved to a bolted aluminium frame if over 82 kg; tie bars with over-centre latches; the shade lifts off for battery service; a responder organization sought now for a paper review, with a US volunteer disaster response organization such as Team Rubicon as the first candidate to approach; FieldCell positioned as the mobile field-site unit beside PowerBox (household outage unit) and SwapCell (shared pack standard); no AC charger, and no vehicle 12 V input in the first prototype; the appearance model to be rebuilt from the constructable model, with the clear side window as a render aid only.

### Documents changed

- `docs/06-design-decisions.md` FCL-DEC-001 v0.3: decisions made; open decisions section now reads "None".
- `docs/decisions/0003-design-for-construction.md` FCL-DDR-003 v0.3: accepted (status Draft kept); A1 sharpened, A3 and A4 as recommended; requirement status after the decision.
- `docs/03-requirements.md` FCL-REQ-001 v0.7: R6 restated at 82 kg and R7 at 160 N on grass; both met on paper; summary counts.
- `docs/04-calcs/01-sizing.md` FCL-CAL-001 v0.5: R6 and R7 status and the summary against the new limits; no figures changed.
- `docs/02-concept.md` FCL-PRC-001 v0.7: R6 and R7 status; open questions on mass, charging inputs and positioning answered.
- `docs/01-problem.md` FCL-PRB-001 v0.5: responder review question answered.
- `docs/05-build-plan.md` FCL-BLD-001 v0.3: R6 and R7 first checks against the new limits; FCL-DDR-003 shown as accepted.
- `README.md`: positioning paragraph in the Concept section; build plan paragraph cites the 82 kg limit.

### Follow-up actions to carry approved decisions into the design

1. Decision 2 (calculations): set the R6 limit to 82 kg and the R7 grass pull limit to 160 N in `docs/04-calcs/sizing.py` so that `results.csv` matches FCL-CAL-001.
2. Decision 6 (docs): add the matching positioning paragraph to the PowerBox and SwapCell READMEs.
3. Decision 8 (model, pictures): rebuild `cad/src/product_model.py` from the constructable model and re-render on Amish's Mac, keeping the clear side window as a render aid only; regenerate `media/card.png` and `media/social-preview.png`.

### Points found in the review

- R6 has now been relaxed twice (70 to 75 kg in DDR-002, and option (a) would take it to 80 kg), and an 80 kg limit against a 79.99 kg model has no margin at all.
- The 2026-10-01 review notes the cart is now a two-person lift at about 80 kg, while the pitch still says one person can deploy it; deploying is still one person, but loading it onto a vehicle is not.

## Approved follow-ups carried out (2026-10-02)

Amish approved all follow-up actions from the open-decision sign-off on 2026-10-02. Results for FieldCell:

1. Decision 2, calculations: done. `docs/04-calcs/sizing.py` now uses the 82 kg R6 limit and the 160 N grass limit for R7, so its printed margins match FCL-CAL-001 (mass margin +2.01 kg; grass pull 156 N against 160 N). There is no `results.csv` in this repo; the script prints its results. FCL-CAL-001 is now v0.6 (safety box cites the 80 kg cart). No requirement status changed and no figure changed.
2. Decision 6, positioning paragraph in the PowerBox and SwapCell READMEs: not done here, it lives in other repos (see Cross-repo actions). The FieldCell README already carries its own paragraph.
3. Decision 8, appearance model: done. `cad/src/product_model.py` now takes the constructable hardware straight from `cad/src/model.py`: the two wing tie bars with their pivot brackets, over-centre latches and keepers; the four shade uprights and their rail tabs (the shade lifts off on four wing bolts); hinge tabs, handle sockets, stand leg clevises and pivot bolts, axle collars and linch pins, outrigger brackets and bolts; the class T fuse and the battery cam straps. The old floating shade posts are gone. The clear side window stays as a render aid only. Render scenes exported to `/home/claude/renders/fieldcell` (hero, exploded, detail, with `fieldcell__jobs.json`). `media/card.png` and `media/social-preview.png` are regenerated on Amish's Mac with the renders.

Model, BOM, mass, cost and drawings are unchanged (82 kg and 160 N are limits, not design changes), so the general arrangement, concept media and build plan pictures were not regenerated. Cost stays USD 2,101 against the USD 2,100 target (USD 1 over).

### Cross-repo actions

- PowerBox README: add the matching positioning paragraph (FieldCell is the mobile field-site unit; PowerBox the household outage unit; SwapCell the shared pack standard).
- SwapCell README: add the same paragraph.

### Documents changed

`docs/04-calcs/01-sizing.md` FCL-CAL-001 v0.6; `docs/04-calcs/sizing.py`; `cad/src/product_model.py`; this review note.

## 2026-10-02: photoreal renders redone on the constructable design

Rendered with Blender Cycles on Amish's Mac from the updated appearance model; captioned with `.kit/photo_caption.py`; `media/card.png` and `media/social-preview.png` regenerated with `.kit/cards.py`. Views: hero, exploded, detail. image_qc passes. Appearance deviations are those logged above as proposed, awaiting Amish.

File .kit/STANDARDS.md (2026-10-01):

---
doc_id: OHP-STD-001
title: Documentation and drawing standard
project: Open Hardware Portfolio
doc_type: Standard
version: "1.7"
status: Released
date: 2026-09-30
author: Amish Chadha
license: CC-BY-SA-4.0
revisions:
  - version: "1.0"
    date: 2026-09-24
    author: Amish Chadha
    change: First release of the standard
  - version: "1.1"
    date: 2026-09-24
    author: Amish Chadha
    change: Adopt Technology Readiness Levels (section 9) for project maturity
  - version: "1.2"
    date: 2026-09-24
    author: Amish Chadha
    change: Portfolio phase cap (section 10), concept media standard (section 11), CLAUDE.md guardrails
  - version: "1.3"
    date: 2026-09-24
    author: Amish Chadha
    change: Scale figure, interactive 3D viewer and flow diagrams added to concept media; session slash commands
  - version: "1.4"
    date: 2026-09-26
    author: Amish Chadha
    change: Every sheet and render names the project and its GitHub repository; overall dimensions, ISO centre lines and 300 dpi PNG on sheets; titles name the device and view labels state the viewing direction; optional photoreal renders with Blender
  - version: "1.5"
    date: 2026-09-27
    author: Amish Chadha
    change: Product renders (section 12), storefront images and image quality check (section 13), public release and release gate (section 14), authorship, citation and commit signing (section 15)
  - version: "1.6"
    date: 2026-09-29
    author: Amish Chadha
    change: Licensing metadata with REUSE (section 16), Zenodo DOI and Software Heritage archiving (section 17), release gate checks REUSE and a single CITATION.cff license, archive.py
  - version: "1.7"
    date: 2026-09-30
    author: Amish Chadha
    change: Concept and constructable design states; design decisions register (DEC) kept apart from the build plan; prototype build plan (BLD, section 18) with pictures by component is required TRL 3 evidence; every repo targets TRL 3 during the populate phase; build_views.py; /to-trl3 and /build-plan commands
---

# Documentation and drawing standard

Every project in the portfolio uses this standard, so that each precis, write-up and sketch looks the same and carries its own version history. The standard ships as a kit in each repo's `.kit/` folder. The kit version is in `.kit/KIT_VERSION`.

## 1. Document types and IDs

Every controlled document has a unique ID in the form `PRJ-TYP-NNN`.

- `PRJ` is the three-letter project code listed in section 7.
- `TYP` is the document type code from the table below.
- `NNN` is a sequence number within that project and type, starting at 001.

| Code | Type | Typical file |
| --- | --- | --- |
| PRC | Design precis | `docs/02-concept.md` |
| PRB | Problem statement | `docs/01-problem.md` |
| REQ | Requirements | `docs/03-requirements.md` |
| CAL | Calculation or sizing note | `docs/04-calcs/*.md` |
| DDR | Design decision record | `docs/decisions/*.md` |
| BOM | Bill of materials | `bom/bom.csv` |
| DWG | Drawing or sketch sheet | `cad/drawings/*.svg` |
| BLD | Prototype build plan (section 18) | `docs/05-build-plan.md` |
| DEC | Design decisions register (section 18) | `docs/06-design-decisions.md` |
| TST | Test plan or test report (front matter adds `environment: lab` or `relevant`) | `docs/05-tests/*.md` |

Example: `TBK-PRC-001` is the ThermaBrick design precis.

## 2. Revision scheme

| Artifact | While in draft | When released | Change after release |
| --- | --- | --- | --- |
| Documents | 0.1, 0.2, 0.3 ... | 1.0 | 1.1 for minor edits, 2.0 for a design change |
| Drawings | Rev P1, P2 ... (preliminary) | Rev A | Rev B, C ... |

- Every change to a controlled document adds a row to its revision history before the commit.
- The `version` field in front matter always equals the newest row in `revisions`. The renderer rejects a document where they differ.
- Status is one of `Draft`, `In review`, `Released` or `Superseded`. Draft and In review documents print with a status band on every page.
- Every release is tagged in Git as `<doc_id>/v<version>`, for example `TBK-PRC-001/v1.0`. Drawings are tagged `TBK-DWG-001/revA`.
- Git history is the full audit trail. The in-document revision table is the human-readable summary.

## 3. Document front matter

Every Markdown document under version control starts with this block:

```yaml
---
doc_id: TBK-PRC-001
title: ThermaBrick design precis
project: ThermaBrick
doc_type: Precis
version: "0.1"
status: Draft
date: 2026-09-24
author: Amish Chadha
license: CERN-OHL-S-2.0
revisions:
  - version: "0.1"
    date: 2026-09-24
    author: Amish Chadha
    change: Initial draft
---
```

Quote version numbers so YAML keeps `1.0` as text instead of turning it into a number. List revisions newest last.

## 4. Writing style

- Chicago Manual of Style.
- No em dashes. Restructure the sentence instead.
- Lead each section with its conclusion, then support it.
- SI units throughout, in the form `12 kW`, `450 °C`, `3.2 m`. Imperial values may follow in parentheses.
- Number every figure and table ("Figure 2", "Table 1") and give each a caption.
- State every assumption in the calculation that depends on it.
- Put safety notes in a blockquote starting with **Safety:**.

## 5. Visual identity

| Element | Specification |
| --- | --- |
| Typeface | IBM Plex Sans for text, IBM Plex Mono for code and values (SIL Open Font License, bundled in `.kit/fonts`) |
| Ink | `#111827` |
| Secondary text | `#4B5563` |
| Rules and grid | `#D1D5DB` |
| Accent (one only) | `#0F766E` teal |
| Document page | US Letter, 20 mm margins |
| Drawing sheet | ANSI B landscape (431.8 x 279.4 mm) |
| Footer | Document ID, version, status, license and designmolecule.com on every page |

## 6. Drawing and sketch conventions

- Units are millimeters unless the title block says otherwise.
- Third-angle projection, marked with the symbol in the title block.
- Line weights: visible outlines 0.5 mm, hidden lines 0.25 mm dashed, center lines 0.18 mm chain.
- The title block contains the project, title, drawing number, revision, scale, units, projection, sheet, author, date, material or notes, and license.
- Every sheet and every render names the project and its GitHub repository (from `repo:` in `project.yaml`), at the top of the sheet and in the title block, so a printed or forwarded sheet is never anonymous.
- The drawing title names the device, not only the drawing type (for example "Handheld near-infrared resin scanner: general arrangement").
- Every view label states its scale and viewing direction (for example "Scale 1:1; side elevation looking along +Y"), and every isometric or render states where it is seen from.
- Orthographic views generated with `add_ortho` carry overall dimensions (length and depth on the top view, height on the front view) and ISO 128 centre lines on cylinders; hidden lines are dashed. Tolerances are not shown before TRL 4.
- Sheets are exported as SVG, PDF and a 300 dpi PNG.
- The revision table in the top right of the sheet lists every revision.
- Concept sketches use the same sheet and title block and carry the label "CONCEPT, NOT FOR FABRICATION".
- Geometry comes from `cad/src/*.py` (build123d). Sheets are generated by `.kit/drawing.py` and never edited by hand.

## 7. Project codes

| Code | Project | Code | Project | Code | Project |
| --- | --- | --- | --- | --- | --- |
| TBK | ThermaBrick | PCF | PicoFlow | HLT | HelioLite |
| CCB | CharCube | DRN | DustRunner | TRT | TremorTrace |
| STC | StepCue | FXH | FlexHand | CPD | ColdPod |
| SCL | SunClave | STR | SteamRoot | GGD | GrainGuard |
| SDL | SeedLine | ZBX | ZeerBox | RMS | RootMesh |
| DWD | DewDrive | SSK | StillStack | PPR | PotPress |
| WWT | WaterWatch | LMF | LumaFlow | FCL | FieldCell |
| CNP | ConePro | CVC | CulvertCrawl | EGD | EmberGuard |
| SNF | SnapFrame | CGM | CargoMule | SCM | StepClimber |
| SWC | SwapCell | PLP | PalletPilot | FTK | FlatTrike |
| WWK | WaterWalker | GRR | GrowRider | SSP | SunSpoke |
| SGN | StepGen | PBX | PowerBox | WML | WasteWise-ml |
| WSC | WasteWise Scan | RFE | ReflowEconomy | | |
| OHP | Portfolio-wide | | | | |

## 8. Build and publish

- `python .kit/render.py` checks every controlled document and renders it to `docs/pdf/<doc_id>_v<version>.pdf`.
- `python .kit/drawing.py` (called from each project's `cad/src/sheets.py`) builds drawing sheets as SVG and PDF in `cad/drawings/`.
- The GitHub Action in `.github/workflows/docs.yml` runs the checks on every push and attaches PDFs to a GitHub Release whenever a release tag is pushed.
- Public releases follow section 14: `python .kit/release_gate.py` must pass, and the release tag is `v0.<TRL>.0` (for example `v0.3.0` at TRL 3).

## 9. Technology Readiness Level (TRL)

Each project states its maturity as a Technology Readiness Level on the NASA and US DOE 1 to 9 scale. The TRL rates this specific design, not the underlying technology. A sand battery is commercial elsewhere, but a new sand battery design starts at TRL 2 until evidence shows otherwise.

| TRL | Definition | Evidence the repo must contain |
| --- | --- | --- |
| 1 | Basic principles observed | Problem statement (PRB) |
| 2 | Technology concept formulated | Draft precis (PRC) and requirements (REQ) |
| 3 | Analytical or experimental proof of concept | Calculation note (CAL), working build123d model with STEP export, drawing sheet (DWG), priced BOM with every unit cost filled in, prototype build plan (BLD) with pictures, `design_state: constructable` |
| 4 | Components validated in the lab | Test report (TST) with `environment: lab`, build log entries |
| 5 | Validated in a relevant environment | Test report (TST) with `environment: relevant` |
| 6 | System prototype demonstrated in a relevant environment | Precis at version 1.0 or later with status Released, a drawing at a lettered revision (Rev A or later), and a system-level TST with `environment: relevant` |
| 7 to 9 | Operational demonstration through proven in service | Beyond portfolio scope; claim only with a named deployment partner and evidence |

Rules:

- `project.yaml` records `trl` (current level), `trl_target` (the level the current effort aims for) and `trl_evidence` (the files that support the claim).
- `python .kit/render.py --check` fails if the evidence for the claimed TRL is missing. CI runs this check on every push.
- Documentation alone cannot go past TRL 3. TRL 4 and above require hardware and a test report.
- TRL and visibility are independent. A repo can be public at TRL 3 as a documented design ready to build.
- A change of TRL is recorded in the build log with the date and the evidence that justified it.

## 10. Portfolio phase and TRL cap

`.kit/PHASE.yaml` sets the current phase. During the **populate** phase every repo is capped at **TRL 3**: `trl` and `trl_target` may not exceed 3, and the check fails if they do. Every repo targets the cap: `trl_target` must equal 3, so a new repo is taken all the way to TRL 3 (scaffold, populate and advance, see `/to-trl3`). Work that belongs to TRL 4 or later (building or testing hardware, test articles, test plans and reports, build-log entries, purchasing lists, PCB layouts) must not be started. The prototype build plan (BLD, section 18) is TRL 3 paper work and is required. Where it already exists it is kept, flagged in the check output, and not extended. Only Amish changes `PHASE.yaml`.

Every repo carries a `CLAUDE.md` with the working rules for AI sessions: the TRL cap, decision rights (nothing is recorded as decided unless Amish decided it), one step per session, and a mandatory `docs/REVIEW.md` before stopping.

## 11. Concept media

Every repo at TRL 2 or above explains its idea visually. Media are generated from a build123d massing model with `.kit/concept.py`, never drawn by hand, so they stay in step with the design.

| File | Required | Purpose |
| --- | --- | --- |
| `media/hero.png` | TRL 2+ | Shaded isometric render with a 1.75 m person for scale; the website card image |
| `media/concept-blueprint.png` and `.pdf` | TRL 2+ | Blueprint concept sheet: orthographic and isometric views, scale, key figures, title block |
| `media/model.glb` and `media/viewer.html` | TRL 2+ | Interactive 3D viewer (glTF plus model-viewer) for the website |
| `media/cutaway.png` | When the inside matters | Section view showing internal parts |
| `media/exploded.png` | Recommended | Exploded view with numbered callouts matching the BOM |
| `media/flow.png` | When energy or material moves | System, energy or material flow diagram with losses |

Session commands in `.claude/commands/` (`/populate`, `/advance-trl3`, `/rein-in`, `/refresh-media`) carry the standard prompts, so every Claude Code session starts from the same instructions.

At TRL 2 a massing model is enough: correct overall proportions and main components. All concept media carry "CONCEPT, NOT FOR FABRICATION". The check warns when required media are missing at TRL 2 and fails at TRL 3.

## 12. Product renders

Every repo at TRL 3 shows the product as it would look, not only as a massing model.

- `cad/src/product_model.py` is the appearance model. It defines `product_parts()` (named parts with a shape and a material), `TITLE` ("Name: what it is") and `RENDER_VIEWS`. It is for renders only: every main dimension comes from `cad/src/model.py`, never typed in again.
- Where the appearance model departs from `model.py` (a chamfer, a label, a fastener drawn for realism), record the deviation in `docs/REVIEW.md` as "Proposed, awaiting Amish".
- Scale comes from context, not from a floating figure: a hand or forearm for handheld objects, and the posed mannequin (`mannequin()` in `.kit/context_parts.py`: stand, walk, push, ride, sit, reach) for anything a person uses at body scale.
- Renders are made with `.kit/export_views.py` (one scene per view) and `.kit/photoreal.py` (Blender Cycles), then captioned with `.kit/photo_caption.py`. Files are `media/render-<view>.png`; `media/render-hero.png` is required.
- Every caption names the project, the repository and the viewing direction, and carries "CONCEPT, NOT FOR FABRICATION".
- Captions never sit on the render. `.kit/photo_caption.py` adds a header band (title, concept label, repository) above the render and a footer band (view note) below it, wraps every line to the image width, and steps the font down to a floor before adding a line.
- The README opens with `media/render-hero.png`.
- Software-only and scene repositories (no single product) may use a scene render as the hero instead of a product model.

## 13. Storefront images

Two images, both made from `media/render-hero.png` by `python .kit/cards.py .`:

| File | Size | Purpose |
| --- | --- | --- |
| `media/card.png` | 800 x 800 | Square thumbnail for the organization profile page |
| `media/social-preview.png` | 1280 x 640, under 1 MB | GitHub social preview, shown when a repository link is shared |

- The social preview shows the area, name, one-line description, the first sentence of the pitch, the brand line and the repository address. Design Molecule repos read "Design Molecule · open hardware concept, TRL n"; OpenRatio repos read "OpenRatio · research and educational prototype, TRL n".
- GitHub has no API for the social preview. Upload it under the repository's Settings, Social preview, on release day.
- Regenerate both images whenever `render-hero.png` changes.

### Image quality

Every render, card and social preview must be clear and readable. `python .kit/image_qc.py` checks each one, and the release gate blocks on any failure:

| Check | Rule |
| --- | --- |
| Layout | Made by the current `photo_caption.py` or `cards.py`, which store the text layout in the PNG |
| Text inside the image | Every line at least 1.2 % of the image width from each edge; nothing runs off the side |
| No overlap | No line of text touches another line, and no caption text sits on the render |
| Text size | Render captions at least 1.05 % of the image width in pixel height (17 px at 1600 px); social preview text at least 16 px |
| Resolution | Renders at least 1200 px wide; card 800 x 800; social preview 1280 x 640 and under 1 MB |
| Sharpness | The render is not blurred or upscaled (edge sharpness at least 15 on the `image_qc.py` scale) |

Long titles and notes wrap to more lines rather than shrinking below the floor. The social preview shortens the pitch sentence with an ellipsis only if it cannot fit at the smallest size.

## 14. Public release

A repository goes public only when Amish approves it, and only after `python .kit/release_gate.py` passes. The gate checks:

1. `render.py --check` passes (document control, TRL cap, concept media).
2. Storefront: hero render, card, social preview under 1 MB, README leading with the hero, and every image passing the image quality check (section 13).
3. Issue templates in `.github/ISSUE_TEMPLATE/`: question, build report, design suggestion. The build report template restates that the design is a TRL 3 concept, not released for fabrication (OpenRatio: a research and educational prototype, not a medical device).
4. `CITATION.cff` valid, with an author ORCID.
5. License files match `project.yaml`.
6. No em dashes in the repository's own text.
7. BioMedical and OpenRatio repos use soft, non-clinical wording: "research and educational prototype, not a medical device".
8. No secrets anywhere in the history (gitleaks).
9. No links to sibling repositories that are still private.
10. REUSE files present (`REUSE.toml`, `LICENSES/`, `.github/workflows/reuse.yml`) and `reuse lint` passes (section 16).
11. `CITATION.cff` names exactly one license, because Zenodo rejects a list (section 17).

It warns, without blocking, when the README lacks a Safety heading or a "not for fabrication" statement, when `CITATION.cff` has no DOI yet, and when the README lacks the Zenodo DOI, REUSE or Software Heritage badge, so a person can confirm.

On release day, per repository:

- A signed, annotated tag `v0.<TRL>.0` on `main`.
- A GitHub release with short notes (what it is, TRL, status, licenses, how to cite) and a design pack, `<repo>-v0.<TRL>.0-design-pack.zip`, holding `cad/step`, `cad/drawings`, `docs/pdf`, `bom`, README, licenses and `CITATION.cff`.
- Description from the first sentences of `pitch` (350 characters at most), website `https://designmolecule.com` (OpenRatio: `https://openratio.ai`), topics from `project.yaml`.
- Before the first release, the repository is switched on in Zenodo (section 17), so the release is archived and gets a DOI.
- Visibility switched to public last, after the release exists.
- The social preview uploaded and the organization profile updated with the new cards.
- After the release: the concept DOI written to `CITATION.cff` and a Software Heritage save requested (section 17).

The internal working files (`CLAUDE.md`, `.kit/CLAUDE.md`, `.claude/commands/`, `docs/REVIEW.md`) stay public, and open "Proposed, awaiting Amish" items stay visible as open questions (Amish, 2026-09-27).

## 15. Authorship, citation and signing

- Amish Chadha is the author of every design, ORCID 0009-0000-8079-7141. Commits are authored as Amish Chadha <amish@designmolecule.com>.
- `CITATION.cff` lists Amish (with ORCID) first, then any credited contributors; `CONTRIBUTORS.md` and the README Credits section agree with it.
- `CITATION.cff` names one license: the hardware license (CERN-OHL-S-2.0), or the software license in a software-only repository. The full split between hardware and software licenses lives in `REUSE.toml` and the README. Once the repository is archived, `CITATION.cff` carries the concept DOI in `doi:`.
- Work done with Claude carries the trailer `Co-Authored-By: Claude <noreply@anthropic.com>` (with the model name), and the README Credits section says designs are developed with AI assistance.
- Every commit and tag pushed to GitHub is signed with Amish's SSH signing key, so GitHub shows it as Verified. Commits prepared elsewhere are re-signed on Amish's Mac before they are pushed.
- Once a repository is public, its history is never rewritten.

## 16. Licensing metadata (REUSE)

Every file states its copyright and license in a machine-readable way, following the REUSE Specification 3.3 (https://reuse.software). A repository is set up with:

```
python .kit/archive.py reuse
```

This writes three things and adds the REUSE and Software Heritage badges to the README badge line:

- `REUSE.toml`, built from the licenses in `project.yaml`. Everything is under the hardware license by default. Scripts, firmware, notebooks, web viewers, workflows and agent commands are under the software license. `cad/` and `electronics/` stay under the hardware license even where they are written as Python. The bundled IBM Plex fonts are OFL-1.1 (IBM Corp.). Copyright is "<first commit year> Amish Chadha".
- `LICENSES/`, with the full text of each license used (`reuse download`). The root `LICENSE` and `LICENSE-SOFTWARE` files stay for GitHub's license detection.
- `.github/workflows/reuse.yml`, which runs the REUSE check (fsfe/reuse-action) on every push and drives the README badge.

A new kind of file that falls outside these rules gets a new annotation in `REUSE.toml` rather than a header comment. `reuse lint` must pass before every commit that adds files, and the release gate enforces it.

## 17. Archiving and DOI (Zenodo and Software Heritage)

Every public repository is archived twice, so the design stays citable and retrievable if GitHub changes.

Zenodo (a citable DOI for each release):

1. Amish's Zenodo account is linked to GitHub. Before the first release, Amish switches the repository on in Zenodo (Account, GitHub). Only Amish changes Zenodo or GitHub settings.
2. Run `python .kit/archive.py zenodo`: it makes sure `CITATION.cff` names one license and adds the Zenodo DOI badge, which uses the GitHub repository ID and always points at the latest version. Zenodo reads its metadata (title, authors with ORCID, license, keywords) from `CITATION.cff`, and rejects the whole archive when that file lists several licenses.
3. Publish the GitHub release (section 14). Zenodo archives it within minutes and mints two DOIs: a version DOI for that release and a concept DOI that stands for all versions.
4. Check the Zenodo record: title, author and ORCID, license, keywords. If Zenodo shows "Citation metadata load failed", fix `CITATION.cff`, validate it with cffconvert and publish a new patch release (for example `v0.3.2`); a failed release is never re-used.
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

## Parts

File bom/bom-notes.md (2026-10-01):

# BOM notes

Prices are indicative TRL 3 estimates (2026) by supplier type, not quotes. Item numbers match the exploded view (`media/exploded.png`) and the component table in FCL-PRC-001. Item 18 (sun shade) was added on 2026-09-25 and item 19 (wing tie bars) on 2026-10-01.

The 19 lines total about $2,101 (checked by `docs/04-calcs/sizing.py`, FCL-CAL-001 section J), $1 over the $2,100 `budget_usd` in `project.yaml`, with no allowance for tools, spares or shipping. Amish raised the budget from $1,500 to $2,100 on 2026-09-25 (FCL-DDR-002); whether to raise it again is an open decision (FCL-DEC-001, item 3). Supplier quotes for the pack, PV wings and inverter will settle it.

Changes for the constructable design (FCL-DDR-003, 2026-10-01), $2,051 to $2,101:

- Item 1, frame: braced axle brackets, hinge tabs, handle sockets, leg clevises, end caps, shade upright tabs and a longer axle ($85 to $97).
- Item 2, wheels: spacer collar, washer and linch pin per wheel ($40 to $42.50 each).
- Items 3, 4, 12, 13, 16: specifications made definite; class T fuse moved into the battery case; the wing frame (item 13) is now a made part.
- Item 14: two latches instead of four, with hinge and tab fixings ($60 to $54).
- Item 15: riveted clevis bracket and pivot bolt per outrigger leg ($8 to $9.50 each).
- Item 17: two cam straps and two PV glands ($90 to $105).
- Item 18: four uprights replace the 50 mm posts ($30 to $39).
- Item 19, wing tie bars, added (2 x $4.50).

Changes from Amish's decisions of 2026-09-25 (FCL-DDR-002), $2,006 to $2,051:

- Item 18, sun shade, added ($30).
- Item 14 now includes two 20 mm aluminium angle hinge spacers ($45 to $60).
- Item 7, the thermostat filter fan and exhaust filter, is now decided rather than proposed.

Changes from the TRL 2 BOM ($1,462) to the first TRL 3 BOM ($2,006):

- PV wings (item 13) are now 200 W semi-flexible modules on a light aluminium frame, about $230 each, instead of $135 rigid panels. A rigid glass 200 W panel weighs about 11 to 12 kg and would push the cart about 10 kg further over its mass limit.
- Electronics enclosure (item 7) now includes an IP54 filter fan and exhaust filter, which the thermal estimate needs.
- Fusing and monitoring (item 12), DC outlets (item 10), inverter (item 9), MPPT (item 8), battery case (item 5) and wiring (item 17) were re-estimated upward to typical prices for parts of adequate quality, for example an inverter with a low no-load draw.
- The frame tube wall is 1.5 mm, and each outrigger now includes its stake.

The pack (item 6), the PV wings (item 13) and the inverter (item 9) are about half the total, so their quotes decide the budget. Make items are priced at material cost only. FieldCell does not use a shared SwapCell pack, so the portfolio rule that SwapCell packs are priced once in the SwapCell repo does not change this BOM.

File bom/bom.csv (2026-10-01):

item | qty | spec | supplier | unit_cost_usd | make_buy | notes
1 Cart frame and axle | 1 | 40 x 40 x 1.5 mm steel square tube (about 4 m) with four 3 mm end caps, 1,200 x 600 mm frame; expanded-metal deck sheet 1,200 x 520 mm on the cross tubes; 20 mm bright steel axle 820 mm long; two 60 x 5 mm axle bracket plates with 5 mm gussets; eight 30 x 3 mm hinge tabs; two 33.7 x 2.6 mm handle sockets with 4 mm gussets; four pairs of 3 mm stand leg clevis plates; four shade upright tabs | Local steel supplier (steel stockholder) | 97.00 | make | Material cost only; welded steel decided 2026-09-25; construction parts added under FCL-DDR-003
2 Wheels 16 in flat-free | 2 | 16 in (406 mm) flat-free polyurethane tyre on steel rim, 20 mm bore with bearings, about 90 mm wide, hub about 60 mm long, load rating 100 kg or more; with a 26 mm spacer collar, a 20 mm washer and a linch pin per wheel | Farm supply or hand-truck parts retailer | 42.50 | buy | Indicative price; flat-free decided 2026-09-25; about 4 kg each (assumed); collar, washer and linch pin added under FCL-DDR-003
3 Handle | 1 | 28 x 1.5 mm steel tube handle legs and 32 x 1.5 mm grip tube, welded, with foam grip and two quick-release pins into the frame sockets | Local steel supplier (steel stockholder) | 22.00 | make | Material cost only
4 Stand legs | 4 | 25 x 2 mm steel tube leg 387 mm long, 60 x 60 x 5 mm foot plate, M10 pivot bolt with nyloc nut and a spring detent pin | Local steel supplier (steel stockholder) | 8.00 | make | Material cost and fixings; pivot on welded clevis plates (FCL-DDR-003)
5 Battery enclosure | 1 | IP65 rugged polypropylene case about 420 x 360 x 300 mm with gland plate and pressure vent | Online retailer (protective case maker) | 85.00 | buy | Indicative price
6 LiFePO4 pack | 1 | 25.6 V 50 Ah (1.28 kWh), 100 A BMS with low-temperature charge cutoff and 45 C high-temperature charge cutoff | Battery distributor (LiFePO4 specialist) | 300.00 | buy | Indicative price; 25.6 V system decided 2026-09-25
7 Electronics enclosure with filter fan | 1 | IP54 polycarbonate enclosure about 320 x 460 x 300 mm; IP54 24 V filter fan (about 40 m3/h) with thermostat and matching IP54 exhaust filter | Electrical distributor | 105.00 | buy | Indicative price; thermostat filter fan adopted by Amish 2026-09-25 (FCL-DDR-002)
8 MPPT charge controller | 1 | 100 V 20 A MPPT for 12/24 V battery, LiFePO4 profile, temperature-compensated off | Solar distributor | 110.00 | buy | Indicative price
9 Inverter 1 kW | 1 | 1,000 W pure sine high-frequency, 2,000 W surge, 24 V input, 120 V 60 Hz, no-load draw 10 W or less, temperature-controlled fan | Solar distributor | 220.00 | buy | Indicative price; 120 V 60 Hz decided 2026-09-25 (230 V 50 Hz variant documented)
10 DC outlet panel | 1 | 2 x USB-C PD 100 W modules (24 V input), 2 x 12 V sockets, 24 to 12 V 20 A converter, sealed panel | Online retailer (marine and RV electrical) | 100.00 | buy | Indicative price
11 AC outlet with GFCI | 1 | 20 A GFCI duplex receptacle (120 V), weatherproof in-use cover and box | Electrical distributor | 40.00 | buy | Indicative price; 30 mA RCD socket for the 230 V variant
12 Fusing and disconnect | 1 | Class T 100 A fuse and holder (inside the battery case, within 150 mm of the positive terminal), battery isolator on the outlet face, DIN rail with DC breakers for inverter, MPPT, DC panel and PV, shunt battery monitor | Solar distributor | 180.00 | buy | Indicative price
13 PV wings 200 W | 2 | 200 W semi-flexible monocrystalline module (Vmp about 36 V, Voc about 45 V), about 1,380 x 680 mm, bonded with structural tape to a made frame of 30 x 20 x 1.5 mm aluminium rectangular tube (1,400 x 700 mm perimeter and three ribs), about 6 kg | Solar distributor | 230.00 | make | Indicative price (module about $190 plus frame material about $40); 24 V class in parallel decided 2026-09-25; frame defined under FCL-DDR-003
14 Panel hinges, spacers and latches | 1 | Two 1.2 m stainless continuous hinges (26 mm leaves, 1.5 mm), each screwed to a 1.2 m 20 x 20 x 2 mm aluminium angle spacer bolted to four steel tabs on the side rail; two over-centre latches with keepers for the tie bars | Hardware store | 54.00 | buy | Indicative price; 20 mm hinge spacer adopted by Amish 2026-09-25 (FCL-DDR-002); tabs, bolts and two latches per FCL-DDR-003
15 Outrigger legs | 4 | 25 x 2 mm steel tube leg 269 mm long with a 50 x 50 x 4 mm foot plate and stake loop, aluminium clevis bracket riveted under the wing frame, M8 pivot bolt, spring detent and one 300 mm steel stake; sets the 15 degree tilt | Local steel supplier (steel stockholder) | 9.50 | make | Material cost, fixings and stake; clevis bracket added under FCL-DDR-003
16 Accessory and cable bin | 1 | Open plastic bin about 320 x 460 x 240 mm with a tie-down strap through the deck | Hardware store | 20.00 | buy | Indicative price
17 Wiring and hardware | 1 | 16 mm2 (6 AWG) battery cable and lugs, four M25 glands (two on each box), two M16 PV glands, 4 mm2 PV cable and connectors, two cam straps for the battery case, fasteners | Electrical distributor | 105.00 | buy | Indicative price; cam straps and PV glands added under FCL-DDR-003
18 Sun shade | 1 | Reflective aluminized fabric about 830 x 580 mm laced to a 20 x 20 x 1.5 mm aluminium tube frame, on four 20 x 20 x 1.5 mm aluminium uprights about 355 mm long bolted to tabs on the side rails, with locating pins; over the battery and electronics enclosures; about 1.6 kg | Online retailer (outdoor and camping) | 39.00 | buy | Indicative price; added by Amish's decision 2026-09-25 (FCL-DDR-002); uprights replace the 50 mm posts (FCL-DDR-003)
19 Wing tie bars | 2 | 20 x 20 x 1.5 mm aluminium square tube about 730 mm long, pivot bracket (3 mm aluminium) and M6 pivot bolt; holds the stowed wings together at the top | Local metal supplier | 4.50 | make | Material cost only; added under FCL-DDR-003

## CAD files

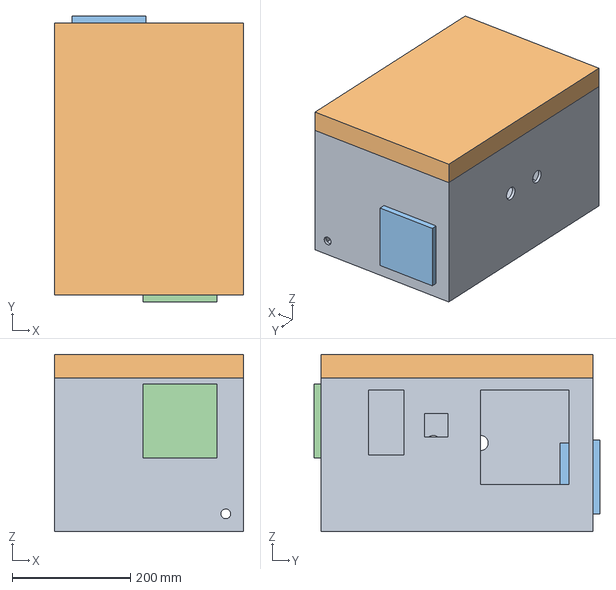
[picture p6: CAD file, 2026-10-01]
cad/step/electronics-enclosure.step
320.0 x 484.0 x 300.0 mm

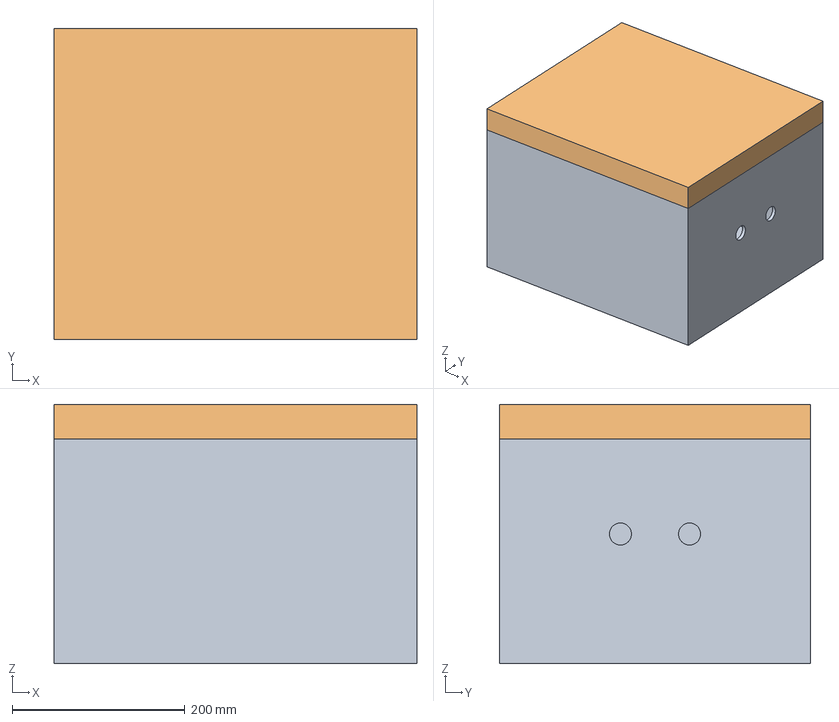
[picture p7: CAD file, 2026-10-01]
cad/step/battery-enclosure.step
420.0 x 360.0 x 300.0 mm

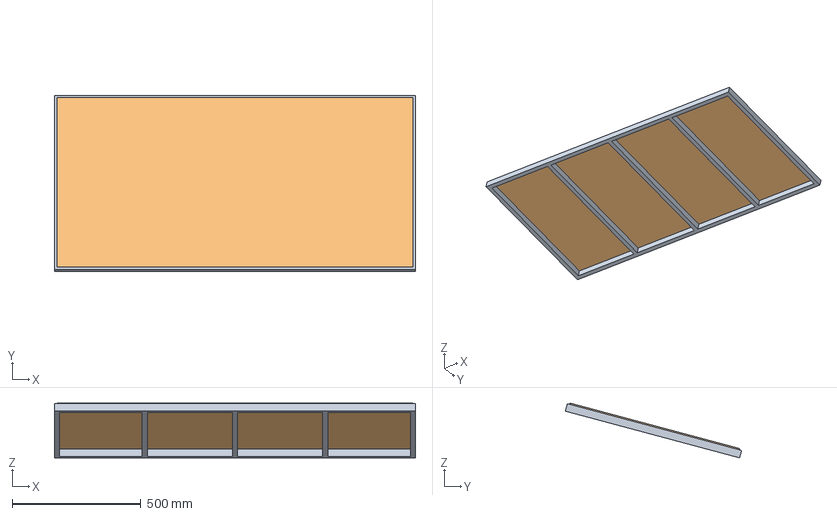
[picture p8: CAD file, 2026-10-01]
cad/step/pv-wing.step
1400.0 x 683.9 x 212.4 mm

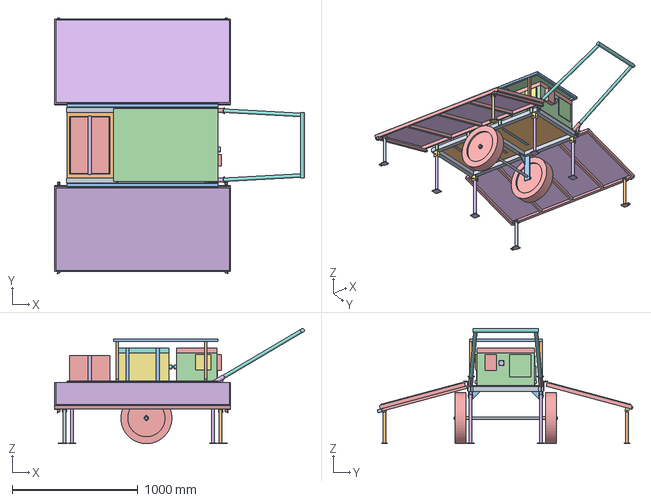
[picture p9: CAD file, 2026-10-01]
cad/step/fieldcell-deployed.step
1986.0 x 2030.5 x 916.0 mm

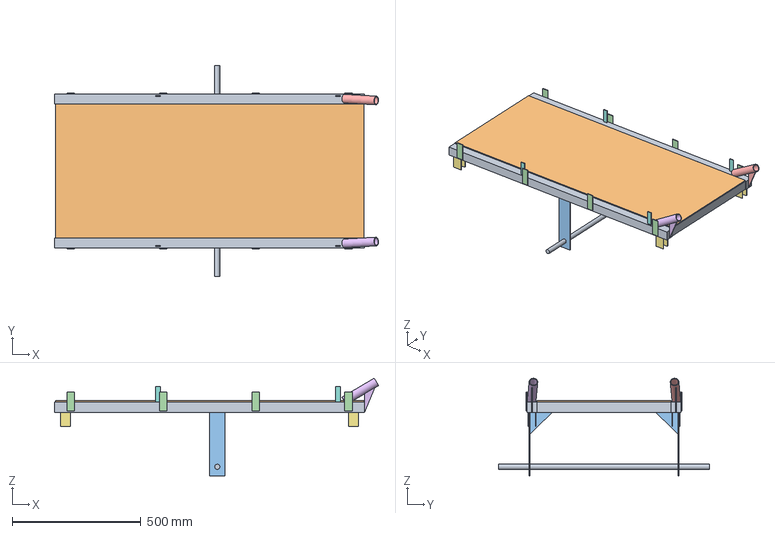
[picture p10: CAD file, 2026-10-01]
cad/step/frame.step
1259.8 x 820.0 x 379.3 mm

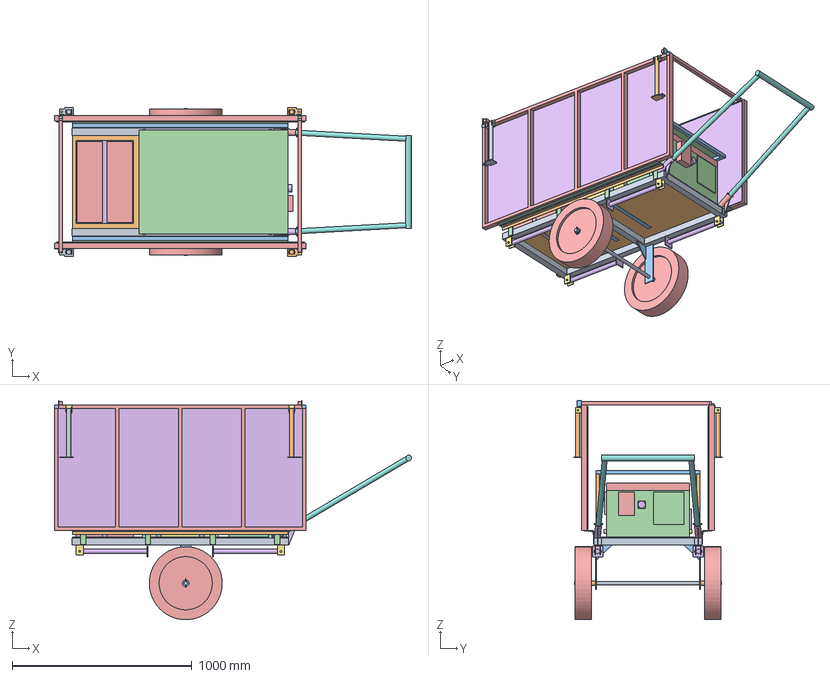
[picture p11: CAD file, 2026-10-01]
cad/step/fieldcell-stowed.step
1986.0 x 829.9 x 1219.9 mm

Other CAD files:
cad/stl/battery-enclosure.stl
cad/stl/electronics-enclosure.stl
cad/stl/fieldcell-deployed.stl
cad/stl/fieldcell-stowed.stl
cad/stl/frame.stl
cad/stl/pv-wing.stl

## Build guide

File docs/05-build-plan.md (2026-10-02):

---
doc_id: FCL-BLD-001
title: FieldCell prototype build plan
project: FieldCell
doc_type: Build plan
version: "0.3"
status: Draft
date: '2026-10-02'
author: Amish Chadha
license: CERN-OHL-S-2.0
revisions:
  - version: "0.1"
    date: '2026-10-01'
    author: Amish Chadha
    change: First build plan; design made constructable (FCL-DDR-003)
  - version: "0.2"
    date: '2026-10-01'
    author: Amish Chadha
    change: Budget treated as a value-engineering target
  - version: "0.3"
    date: '2026-10-02'
    author: Amish Chadha
    change: "First checks for R6 and R7 against the limits set by Amish on 2026-10-02 (82 kg, 160 N on grass); FCL-DDR-003 accepted"
---

# FieldCell prototype build plan

**Plan, not yet built.** How to build the first proof-of-concept prototype, component by component. Building and testing to it is TRL 4 work. Decisions still to be made are kept in the design decisions register ([docs/06-design-decisions.md](06-design-decisions.md)), not here.

## 1. What you are building

Figure 1. Every component, pulled apart and numbered in build order

*Figure 1. Every component pulled apart and numbered in build order. The wings and their parts (13 to 17) are drawn off to the front so the boxes stay visible.*

The prototype is one FieldCell cart: a welded steel frame on two 16 in wheels, carrying a battery case and an electronics box under a reflective shade, with two solar wings hinged along its sides. Parked, the wings fold out on legs at 15° and the cart stands on four legs; for travel the wings fold up as the cart sides and two tie bars hold them together at the top. Figure 1 shows the 21 components in the order you make or fit them. The made parts are the frame, axle, stand legs, handle, hinge spacer angles, wing frames, outrigger legs, tie bars and shade; the battery case and electronics box are bought and drilled or cut. The rest is bought: wheels, battery pack, charge controller, inverter, outlets, fusing, hinges, latches, solar modules, bin, cables and fixings. The work is cutting, drilling and MIG welding steel tube and plate, cutting, drilling and riveting aluminium tube and angle, cutting plastic enclosures, and wiring bought parts with crimped lugs. The parts cost about $2,101 from the bill of materials, against a value-engineering target of $2,100. The finished cart weighs about 80 kg: a two-person lift.

> **Safety:** The prototype holds a 1.28 kWh lithium iron phosphate battery, makes 120 V AC, carries up to about 100 A of DC and has solar panels that are live whenever light falls on them. Keep the class T fuse out until section 6 says otherwise, never connect FieldCell to building wiring, and never charge the pack below 0 °C or above 45 °C. Welding needs a welding helmet, gloves, a fire watch and a clear floor. Cut steel and aluminium edges are sharp: deburr everything. The finished cart is about 80 kg: lift it with two people and keep fingers out of the hinges and folding legs.

## 2. What changed to make it buildable

The concept showed what the cart does; some of its parts could not be made or fixed as drawn. Each change below keeps what the cart does, and all of them are recorded in decision record FCL-DDR-003, accepted by Amish on 2026-10-02.

*Table 1. Changes from the concept.*

| Component | The concept had | The buildable design has | Why |
| --- | --- | --- | --- |
| Deck | A sheet inside the frame, cutting into the cross tubes | An expanded steel sheet laid on the cross tubes between the rails; tubes 5 mm lower, deck top still 460 mm (Figure 2) | The sheet is carried, not hung |
| Axle and wheels | Axle ending at the wheel centres; wheels with no bore; brackets cut into the rails | A welded 820 mm axle through braced brackets; each wheel between a spacer collar and a washer, held by a linch pin (Figure 5) | A fixed axle with bearings in the bought wheels |
| Stand legs | Legs touching the rails, no pivot | Legs on welded clevis plates with a pivot bolt and detent pin, folding along the rail (Figure 7) | The legs fold as the concept says |
| Handle | Tubes running into the frame end with no joint | Two welded sockets with gussets; the handle legs drop in and are pinned (Figure 26) | The handle still detaches |
| Hinge line | Spacer angles standing 20 mm clear of the rails; hinge inside the wing | Steel tabs welded to the rails carry the spacer angle; a real piano hinge with its pin just above the panel face (Figure 9) | The wing sits exactly where the concept put it, 28 mm over the tyre |
| Wings | A solid block | A module bonded to a frame of aluminium tube with three ribs (Figure 17) | The backing frame made definite |
| Outrigger legs | Pushed into the wing, no fixing | A riveted U bracket, a pivot bolt and a detent; the leg folds flat under the wing (Figure 19) | They fold and lock |
| Wing latches | Latches with nothing to latch to | Two tie bars across the tops of the stowed wings, with an over-centre latch (Figures 21 and 22) | Nothing may press on the solar face, which faces in when stowed |
| Sun shade | Posts in mid air beside the boxes; the shade blocked the battery lid | Four uprights bolted to tabs on the rails; the shade lifts off (Figure 24) | It stands on the frame and comes off for service |
| Electronics | Parts stacked on each other and drawn outside the box wall; class T fuse far from the battery | Parts side by side on the mounting plate, outlets and fans through cut-outs; class T fuse in the battery case (Figure 14) | Every part fixed; the fuse within 150 mm of the battery terminal |
| Box spacing | 50 mm between the boxes: the glands did not fit | Electronics box 10 mm nearer the handle; 60 mm gap with two glands each side (Figure 12) | A straight cable run |
| Fixings | Boxes and bin loose on the deck | Cam straps, four floor bolts and a bin strap | Nothing moves on rough ground |

## 3. Making the components

Make and check each component before the assembly step that needs it. Sizes are in millimetres. "Front" is the bin end and "handle end" is the other; "left" and "right" are as seen standing behind the handle looking forward along the cart (the right wing is on your right). Workshop tolerance is 1 mm unless a step says otherwise; drawings do not carry tolerances before TRL 4.

### 3.1 Frame

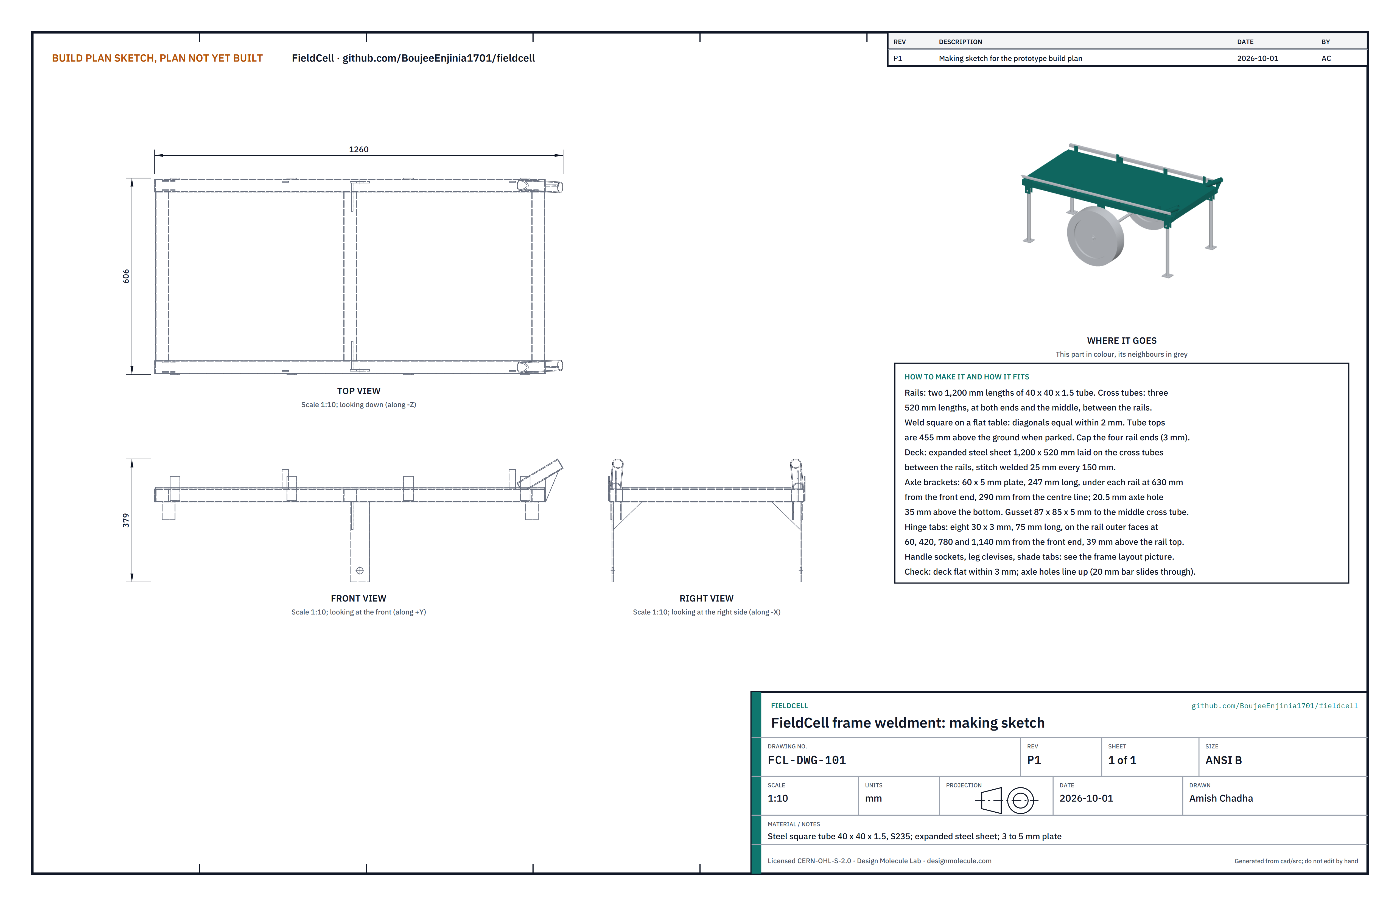
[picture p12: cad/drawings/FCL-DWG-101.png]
Figure 2. Making sketch of the frame


*Figure 2. Frame making sketch (FCL-DWG-101).*

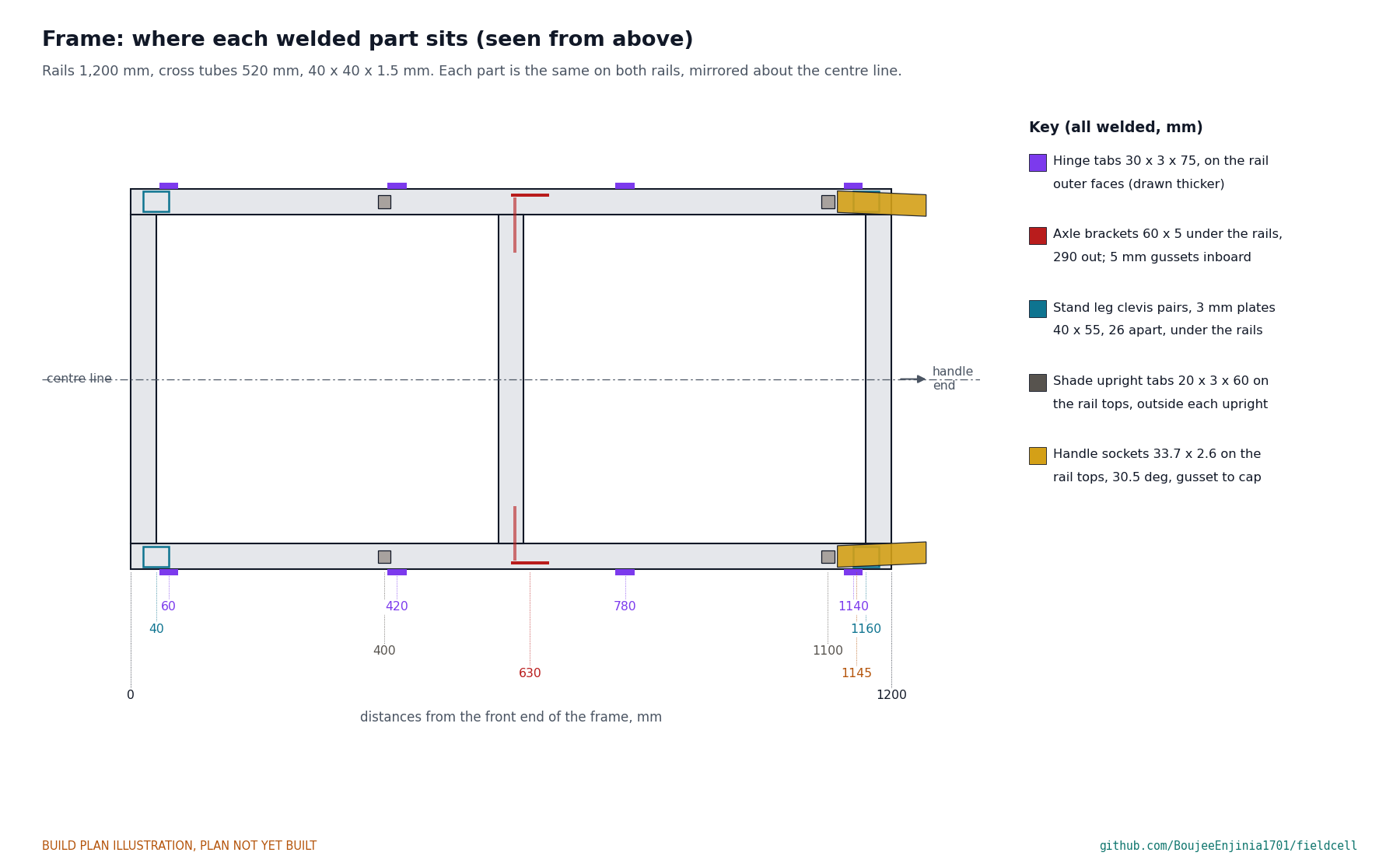
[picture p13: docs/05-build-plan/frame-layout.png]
Figure 3. Where each welded part sits on the frame


*Figure 3. Where each welded part sits, measured from the front end of the frame.*

**What it is and what it is made from.** The welded steel frame everything sits on: two rails, three cross tubes, a deck sheet, and the small plates and tubes the other parts bolt to. Steel square tube 40 x 40 x 1.5 mm (S235 or similar), expanded steel sheet (about 4.5 kg per square metre), steel flat bar and plate 3 to 5 mm, and steel tube 33.7 x 2.6 mm.

**How to make it.**

1. Cut two rails 1,200 long and three cross tubes 520 long from 40 x 40 x 1.5 tube; square the ends.
2. On a flat table, set the rails 600 apart outside to outside, with the cross tubes between them at the two ends and in the middle (centres at 20, 600 and 1,180 from the front end). Tack, check the diagonals are equal within 2 mm, then weld all round.
3. Weld a 40 x 40 x 3 end cap on each of the four rail ends.
4. Deck: cut expanded steel sheet to 1,200 x 520, lay it on the cross tubes between the rails and stitch weld 25 mm every 150 mm to the cross tubes and the rail inner faces.
5. Axle brackets: cut two 60 x 5 plates 247 long; drill a 20.5 hole on the centre line 35 from one end. Weld one under each rail, square to it, hole end down, plate centre 630 from the front end and 290 from the centre line (it sits under the outer half of the rail). Cut two right-angle triangles 87 x 85 from 5 plate and weld one between the inboard face of each bracket and the underside of the middle cross tube.
6. Hinge tabs: cut eight 75 lengths of 30 x 3 flat bar; drill a 5.5 hole 11 below one end. Weld four to the outer face of each rail, upright, hole end up, bottom end 4 above the rail underside, centred 60, 420, 780 and 1,140 from the front end. Their tops stand 39 above the rail top.
7. Stand leg clevises: cut sixteen 40 x 55 plates from 3 plate; drill a 10.5 hole 20 from one end and a 6.5 detent hole 30 below it. Weld them in pairs under each rail, 26 apart inside, centred on the rail centre line, 40 from each rail end (Figure 3), holes lined up. Drill a second 6.5 detent hole in each plate, 30 from the pivot hole toward the middle of the cart, for the folded position.
8. Handle sockets: cut two 150 lengths of 33.7 x 2.6 tube; mitre one end at 30.5° so it sits flat on the rail top. Weld each on a rail top, centred on the rail, its axis meeting the rail top 1,145 from the front end, leaning toward the handle end at 30.5° and turned in by 3° (the handle legs close from 560 to 480 apart). Weld a 4 mm triangular gusset from the end cap to the underside of each socket. Drill an 8.5 hole across each socket 120 up its axis for the quick-release pin.
9. Shade upright tabs: four 60 lengths of 20 x 3 flat bar with a 6.5 hole 30 from the top; weld upright on the rail tops, on the outer side of where each upright stands (400 and 1,100 from the front end, 280 out from the centre line).
10. Clean the welds, deburr, prime and paint.

**How it fits the parts next to it.** The axle passes through both bracket holes (Figure 5). The battery case, electronics box and bin sit on the deck. The hinge spacer angles bolt to the outside of the tabs (Figure 9). The stand legs hang between the clevis plates (Figure 7). The shade uprights stand on the rail tops against their tabs (Figure 24). The handle legs drop into the sockets (Figure 26).

**Check before moving on.** The deck is flat within 3 mm; a 20 mm bar slides through both bracket holes at once; the tab holes line up along a straight line on each side.

### 3.2 Axle

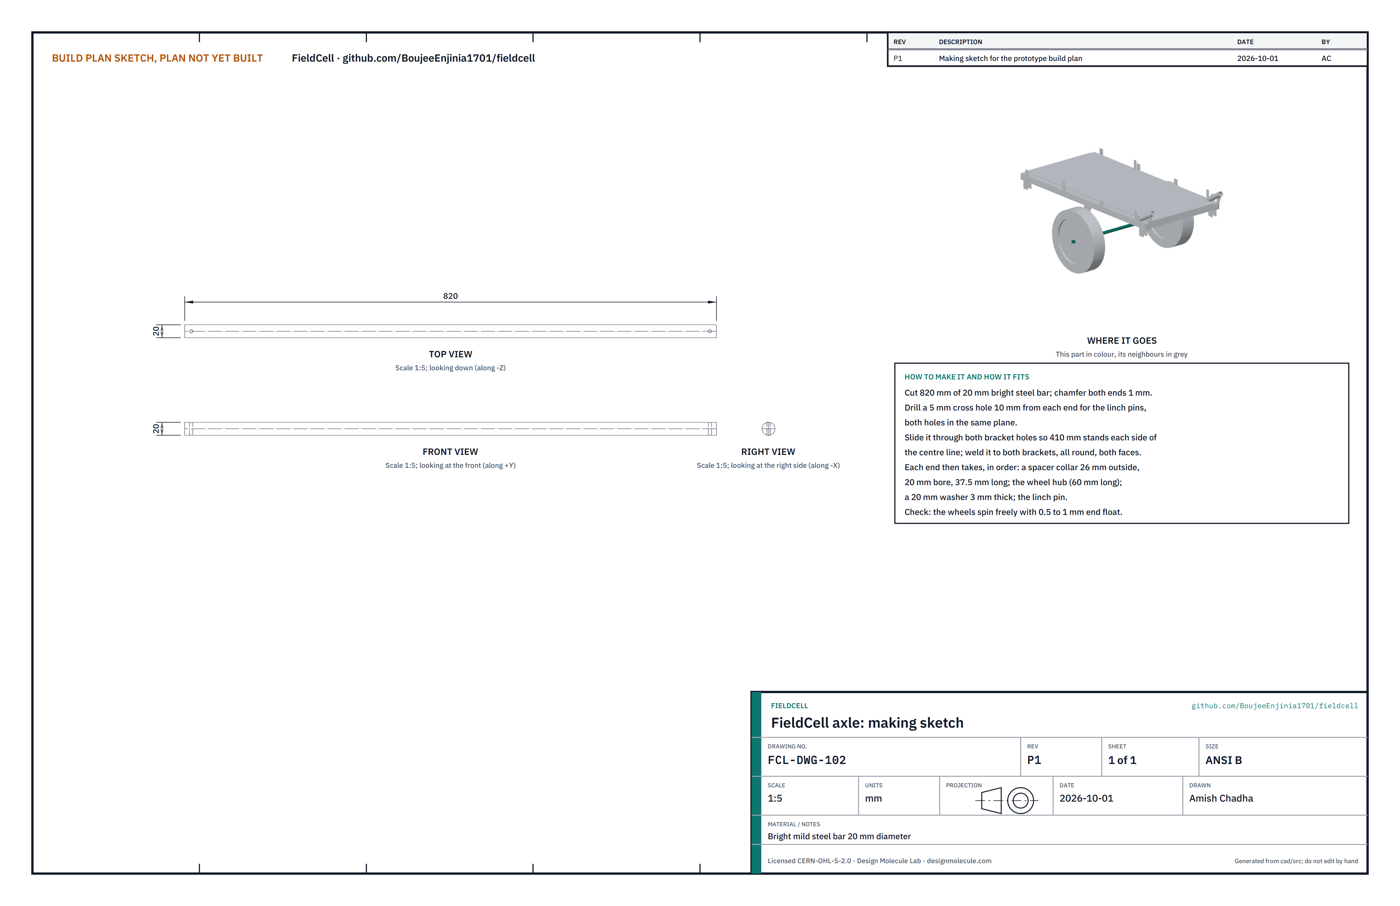
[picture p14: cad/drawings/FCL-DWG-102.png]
Figure 4. Making sketch of the axle


*Figure 4. Axle making sketch (FCL-DWG-102).*

**What it is and what it is made from.** A fixed axle welded to both brackets; the wheels turn on their own bearings. Bright mild steel bar 20 mm diameter.

**How to make it.**

1. Cut 820 of 20 bar; chamfer both ends 1 mm.
2. Drill a 5 cross hole 10 from each end, both in the same plane.
3. Slide it through both brackets so 410 stands each side of the centre line, cross holes vertical, and weld it to both faces of both brackets.

**How it fits the parts next to it.**

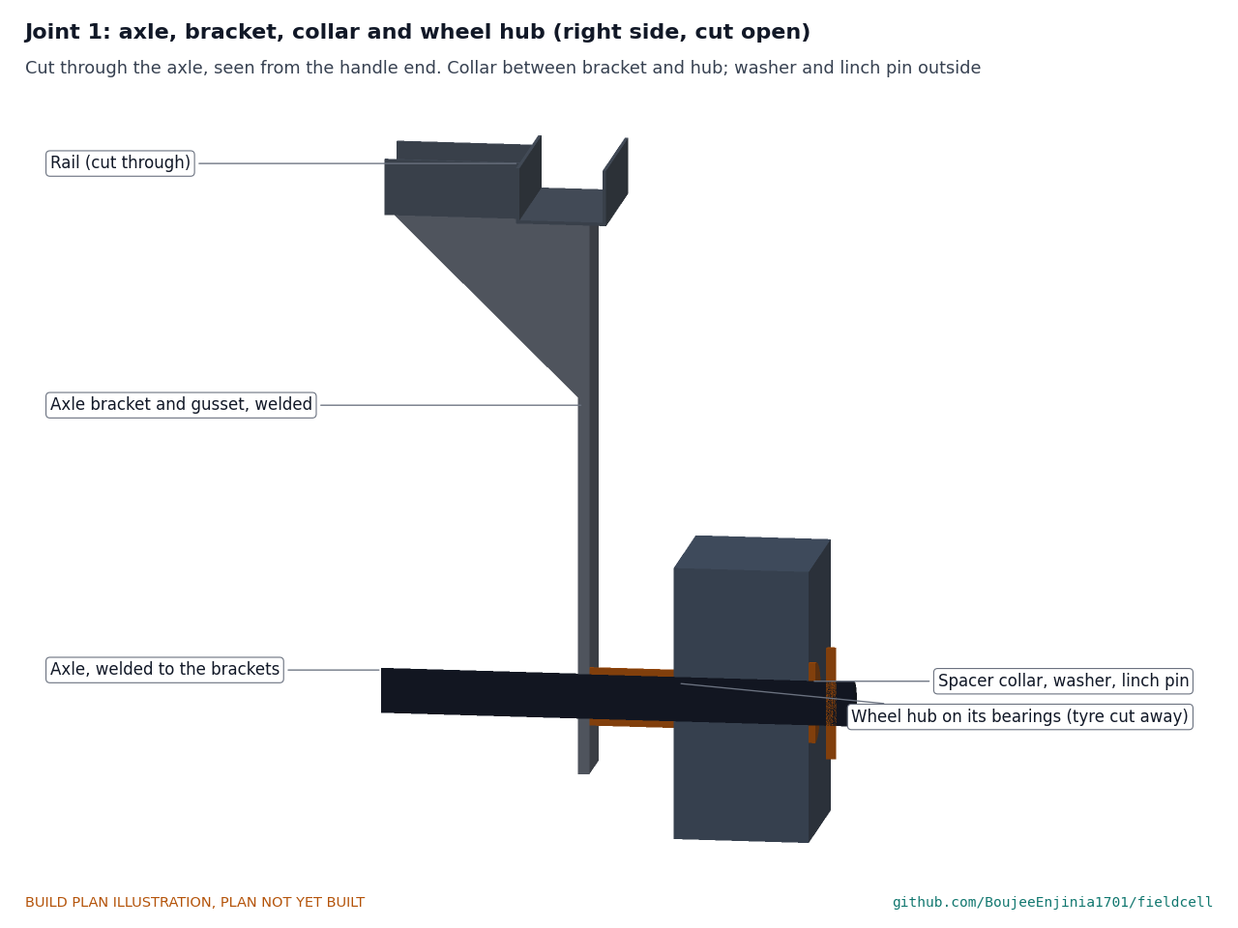
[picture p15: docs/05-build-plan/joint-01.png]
Figure 5. Joint 1: axle, bracket, collar and wheel hub


*Figure 5. Cut through the axle: the spacer collar sits between the bracket and the wheel hub; the washer and linch pin hold the hub on.*

Each end takes, in order from the bracket: a spacer collar 26 outside, 20 bore, 37.5 long; the wheel (hub 60 long, 20 bore with bearings); a 20 washer 3 thick; the linch pin through the cross hole.

**Check before moving on.** Both wheels spin freely with 0.5 to 1 mm of end float.

### 3.3 Stand legs (make 4)

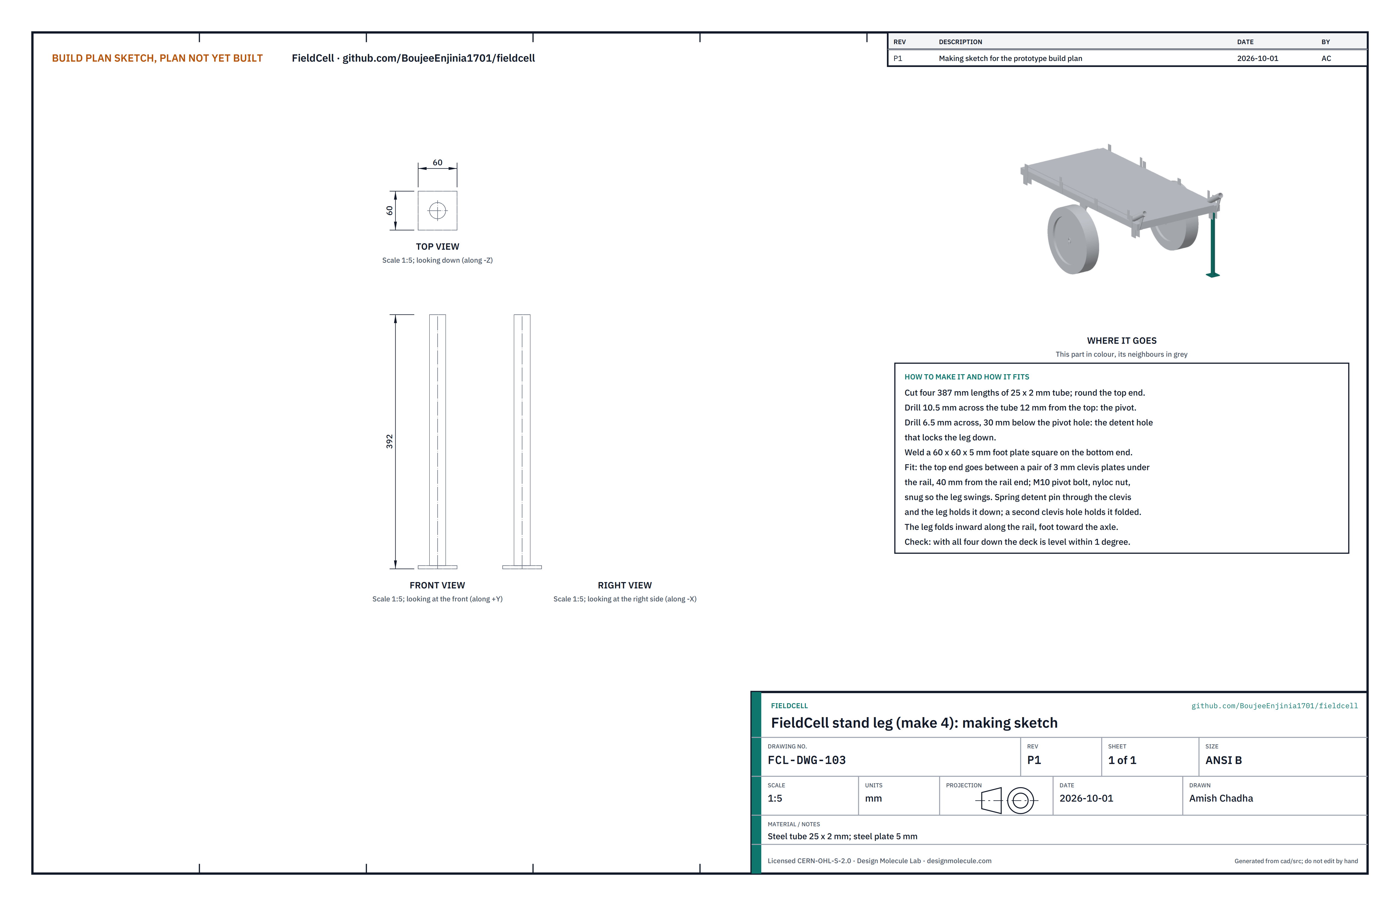
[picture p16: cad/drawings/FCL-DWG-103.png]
Figure 6. Making sketch of the stand leg


*Figure 6. Stand leg making sketch (FCL-DWG-103).*

**What it is and what it is made from.** The four legs that hold the deck level when parked. Steel tube 25 x 2 mm and 5 mm plate.

**How to make it.**

1. Cut four 387 lengths of 25 x 2 tube; round one end.
2. Drill 10.5 across the tube 12 from the rounded end (pivot), and 6.5 across 30 below it (detent).
3. Weld a 60 x 60 x 5 foot square on the other end.

**How it fits the parts next to it.**

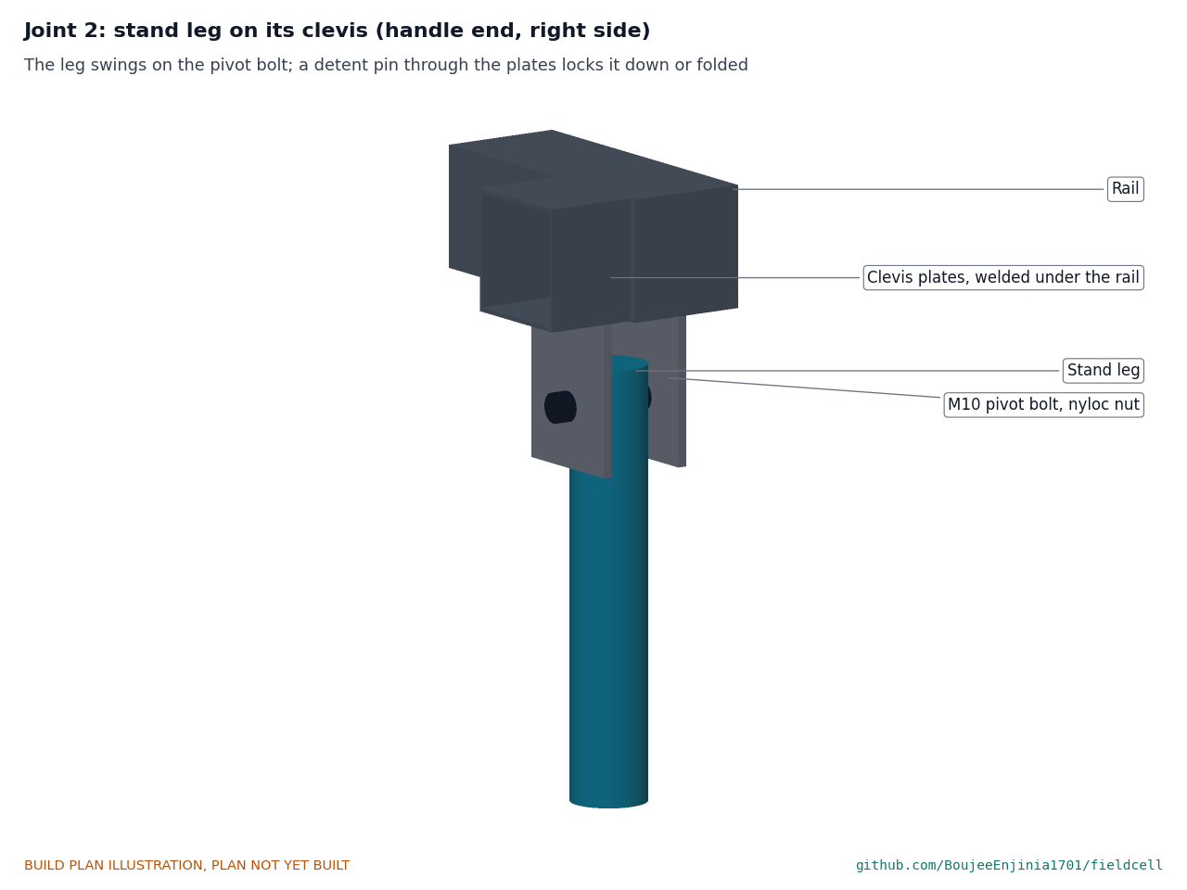
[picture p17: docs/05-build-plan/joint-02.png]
Figure 7. Joint 2: stand leg on its clevis


*Figure 7. The leg hangs between the clevis plates on an M10 bolt; a spring detent pin through the plates and the leg locks it.*

The rounded end goes between a pair of clevis plates; an M10 bolt with a nyloc nut, snug so the leg swings. Down, the detent pin goes through the lower plate holes and the leg. Folded, the leg swings inward along the rail, foot toward the axle, and the pin goes through the second plate holes; it then clears the wheels by 8 mm and the rail by 5 mm.

**Check before moving on.** With all four legs down on a flat floor the deck is level within 1° and the wheels just touch the floor.

### 3.4 Hinge spacer angles (make 2)

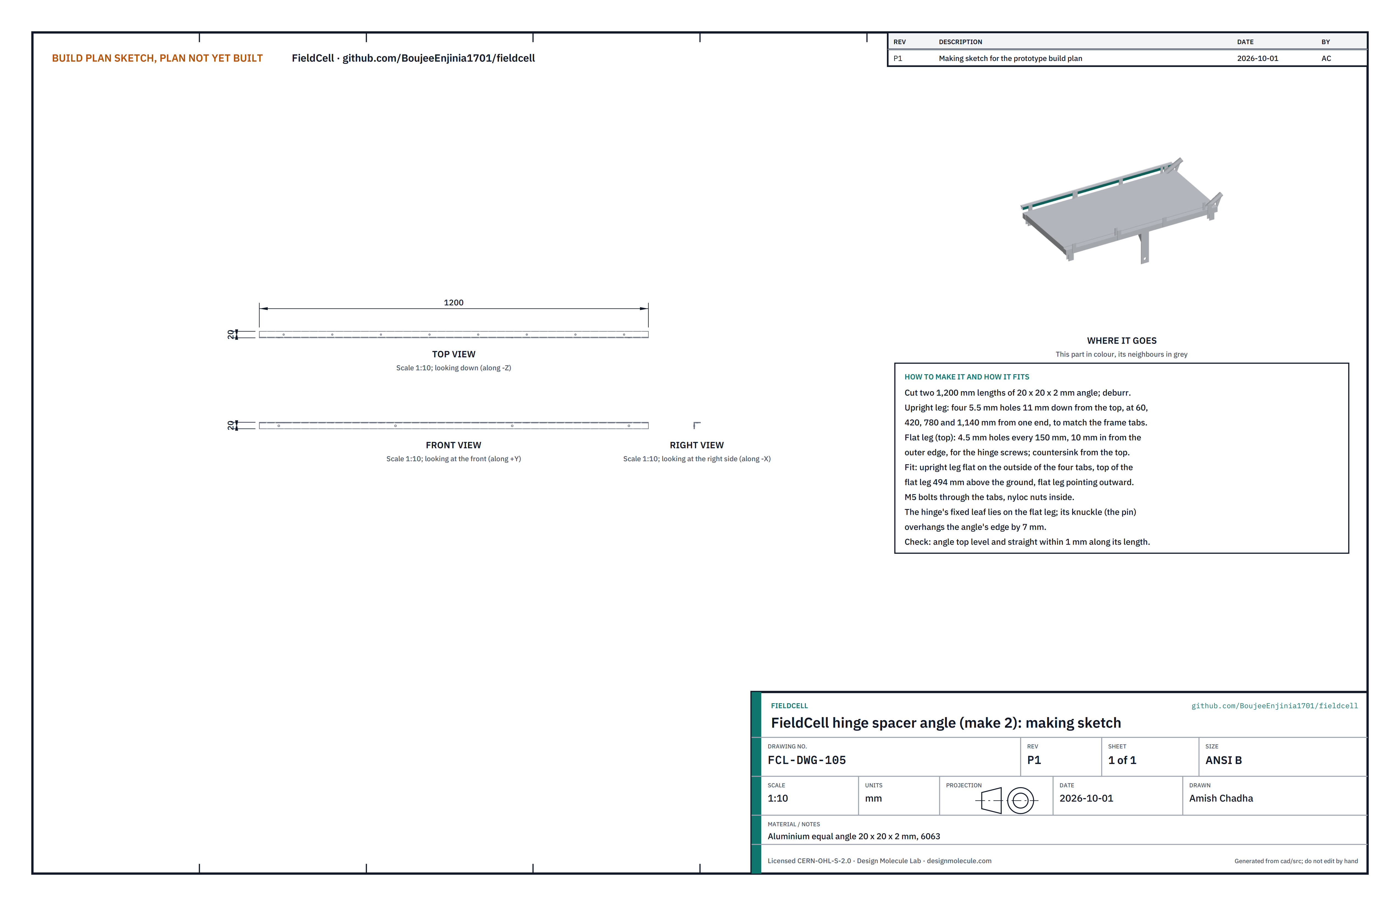
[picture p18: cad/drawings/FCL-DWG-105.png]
Figure 8. Making sketch of the hinge spacer angle


*Figure 8. Hinge spacer angle making sketch (FCL-DWG-105).*

**What it is and what it is made from.** The aluminium angle along each side rail that carries the hinge 20 mm higher than the rail, so the folded-out wing clears the tyre. Aluminium equal angle 20 x 20 x 2 mm, 6063 class.

**How to make it.**

1. Cut two 1,200 lengths; deburr.
2. Upright leg: four 5.5 holes 11 below the top, at 60, 420, 780 and 1,140 from one end.
3. Flat leg: 4.5 holes every 150, starting 75 from one end, 10 in from the outer edge; countersink from the top.

**How it fits the parts next to it.**

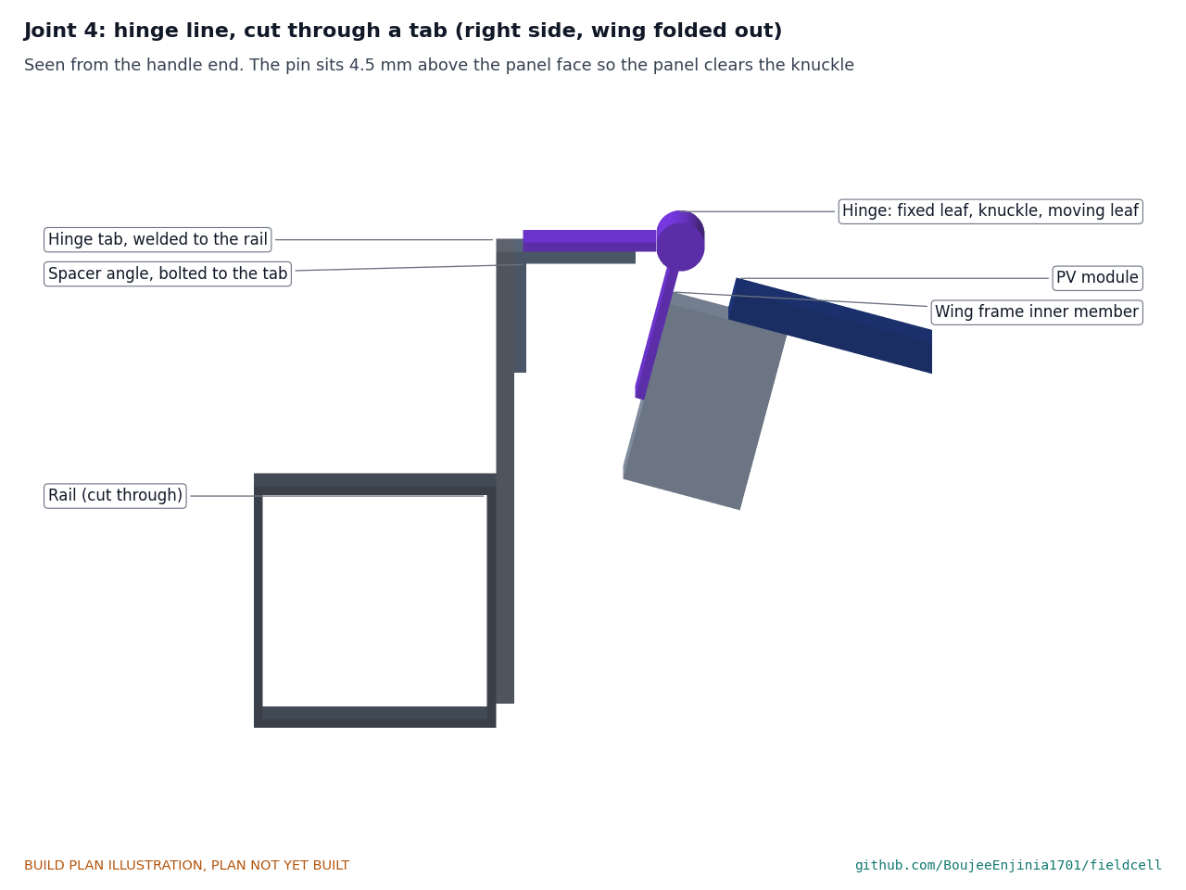
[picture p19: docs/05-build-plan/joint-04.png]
Figure 9. Joint 4: the hinge line, cut through a tab


*Figure 9. Seen from the handle end, cut through a tab: tab welded to the rail, angle bolted to the tab, hinge on the angle, wing on the hinge.*

The upright leg lies flat on the outside of the four tabs, its flat leg pointing outward and its top flush with the tab tops, 494 above the ground; M5 bolts through each tab, nyloc nuts inside. The hinge's fixed leaf lies on the flat leg with its knuckle just beyond the angle's edge.

**Check before moving on.** The angle top is straight and level within 1 mm along its length.

### 3.5 Battery case, drilled

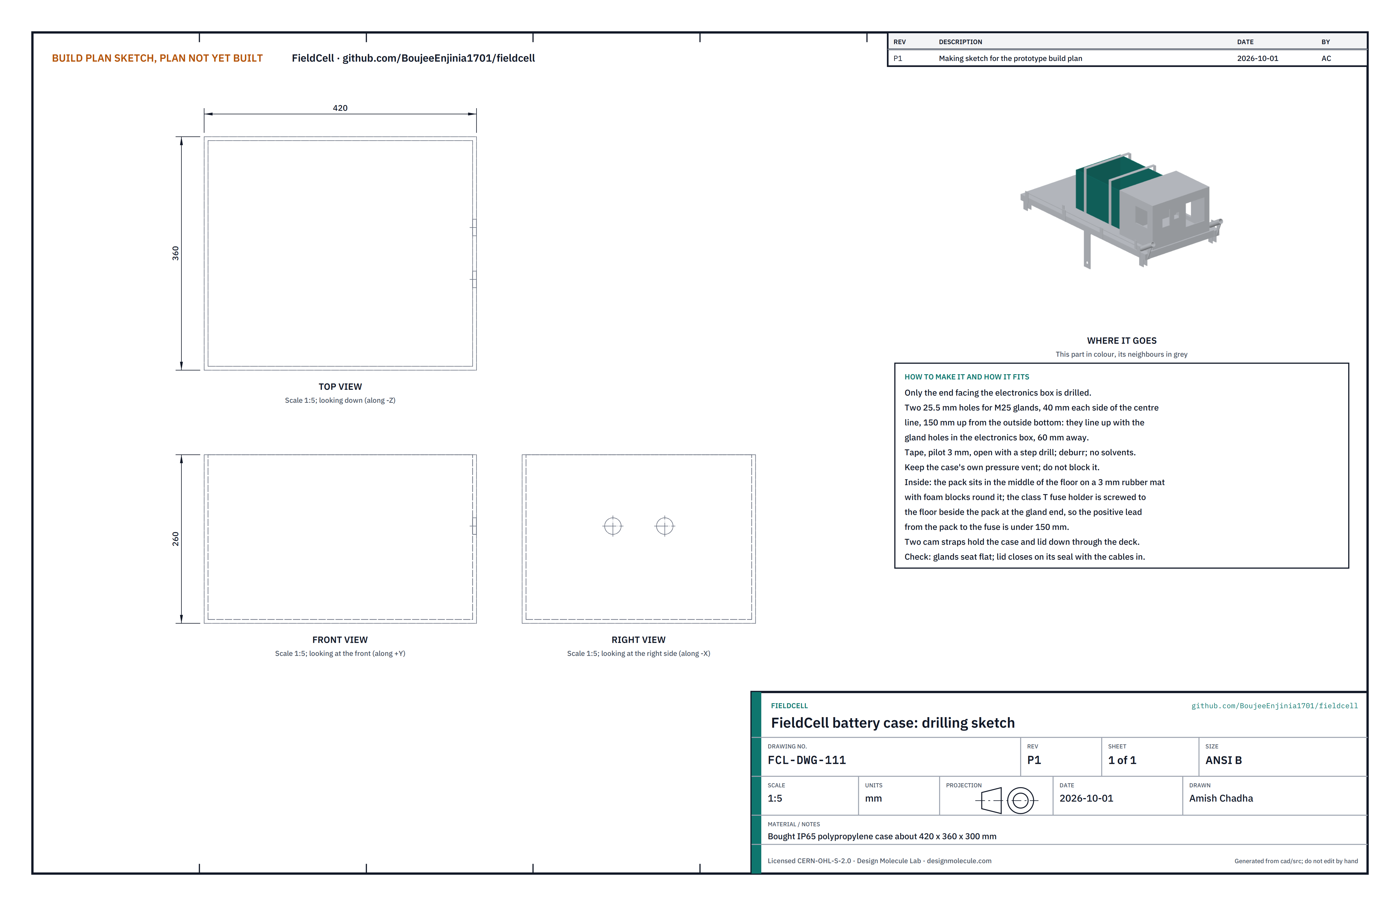
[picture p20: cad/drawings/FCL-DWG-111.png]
Figure 10. Drilling sketch of the battery case


*Figure 10. Battery case drilling sketch (FCL-DWG-111).*

**What it is and what it is made from.** A bought IP65 polypropylene case, about 420 x 360 x 300 with a lid, a pressure vent and room for the pack, the class T fuse and foam. Only its end facing the electronics box is drilled.

**How to make it.**

1. Tape the end wall. Mark two holes 40 each side of the centre line, 150 up from the outside bottom.
2. Pilot 3, open to 25.5 with a step drill at low speed, deburr; no solvents.
3. Fit two M25 cable glands, seal outside, nut inside.
4. Inside, lay a 3 rubber mat on the floor. Screw the class T fuse holder to the floor beside where the pack will stand, at the gland end, so the lead from the pack's positive terminal to the fuse is under 150 long.

**How it fits the parts next to it.**

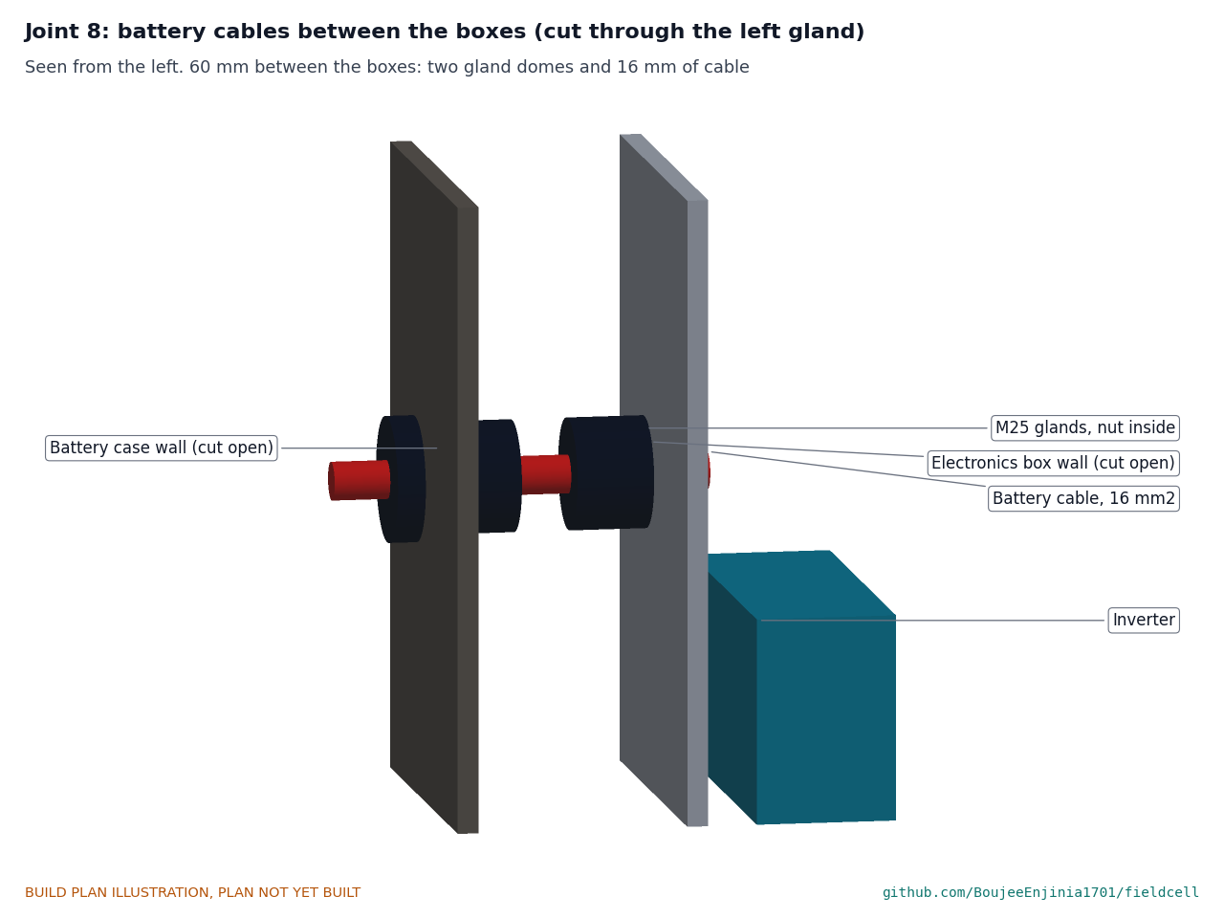
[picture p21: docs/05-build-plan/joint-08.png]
Figure 11. Joint 8: battery cables between the boxes


*Figure 11. 60 mm between the boxes: two gland domes and a short straight run of 16 mm² cable.*

The case stands on the deck centred on the middle cross tube, gland end toward the handle, held by two cam straps that go over the lid and through the deck. Its glands line up with those in the electronics box.

**Check before moving on.** Each gland seats flat; the lid closes on its seal.

### 3.6 Electronics box, cut and fitted out

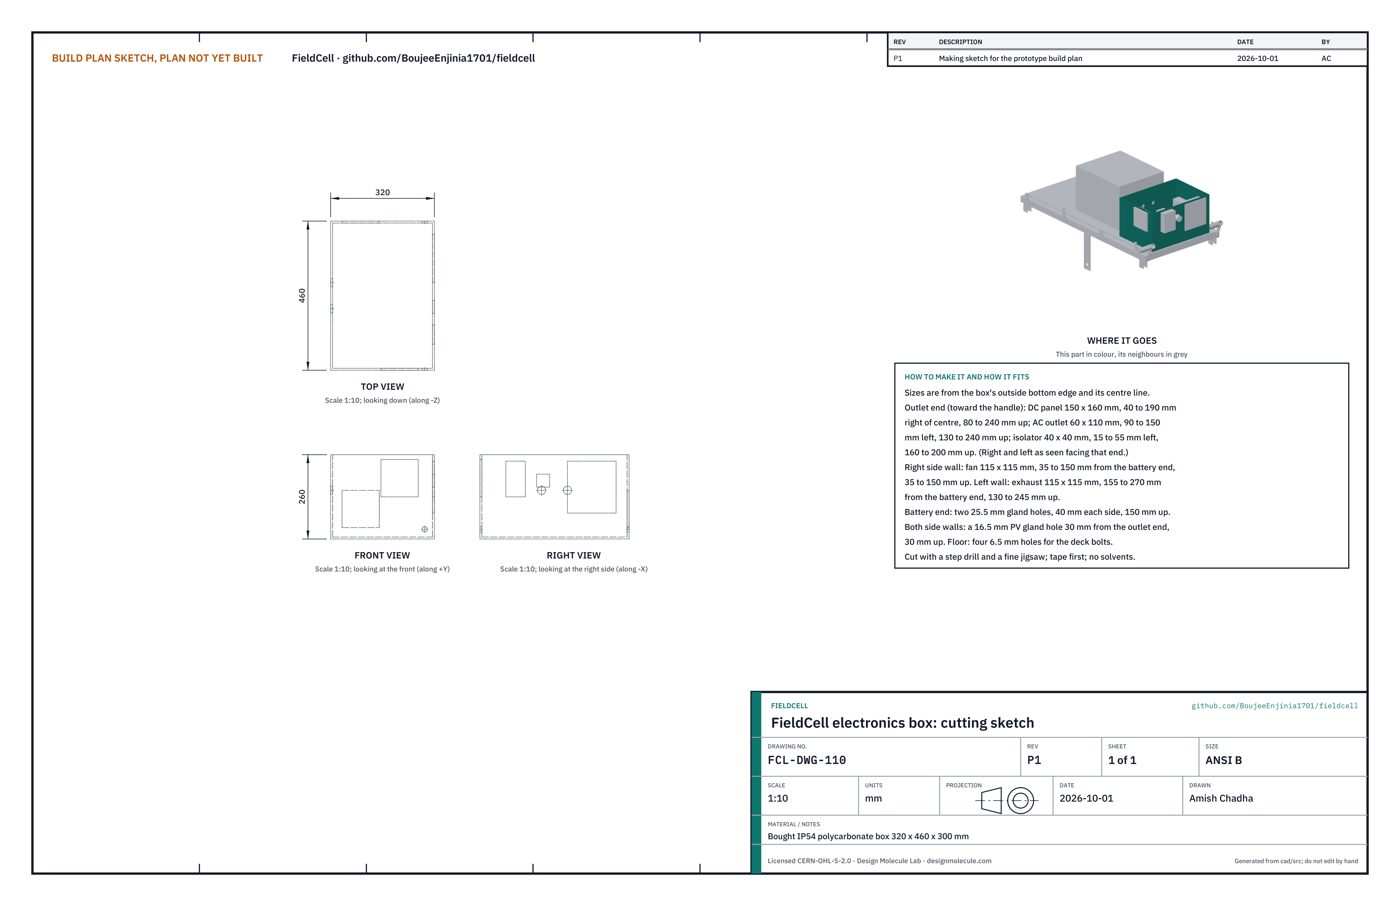
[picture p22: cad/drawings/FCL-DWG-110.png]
Figure 12. Cutting sketch of the electronics box


*Figure 12. Electronics box cutting sketch (FCL-DWG-110).*

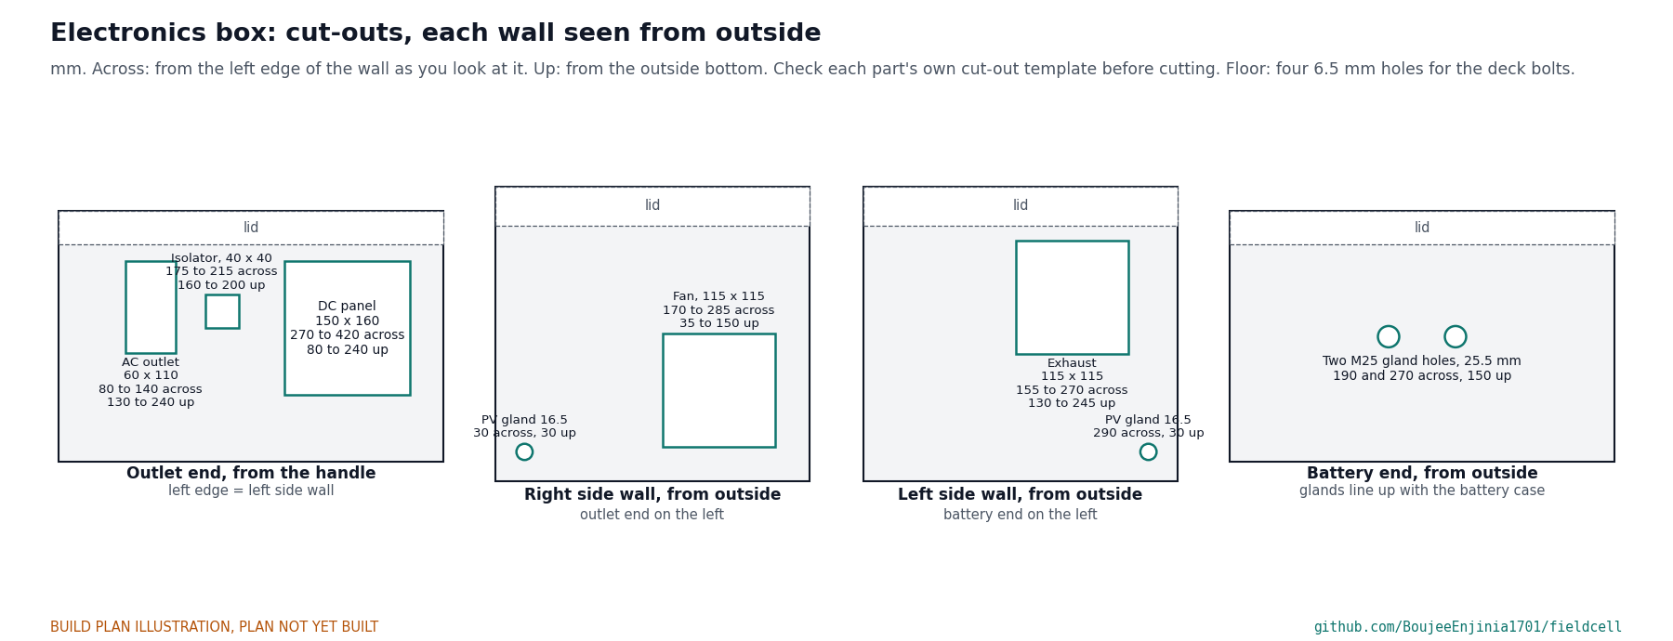
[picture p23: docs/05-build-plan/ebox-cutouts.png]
Figure 13. Cut-outs in each wall


*Figure 13. Every cut-out, each wall seen from outside.*

**What it is and what it is made from.** A bought IP54 polycarbonate box, about 320 x 460 x 300 with a lid and a mounting plate, that holds the inverter, charge controller and breakers and carries the outlets on its handle-end wall.

**How to make it.**

1. Tape each wall and mark the cut-outs from Figure 13, then check each against the template of the part you bought; the part's own template wins.
2. Drill corner holes and cut the rectangles with a fine jigsaw blade; drill round holes with a step drill. Deburr; no solvents.
3. Floor: four 6.5 holes, about 20 in from each corner, for the deck bolts.
4. On the bench, screw the inverter, the charge controller and the DIN rail (breakers and shunt) to the mounting plate as Figure 14 shows: inverter along the left half, charge controller and DIN rail side by side on the right, at least 10 apart.
5. Fit the plate on its bosses. Fit the outlets, isolator, filter fan, exhaust filter and glands through their cut-outs with their gaskets (step 8).
6. Wire as Figure 15 and section 3.6.1.

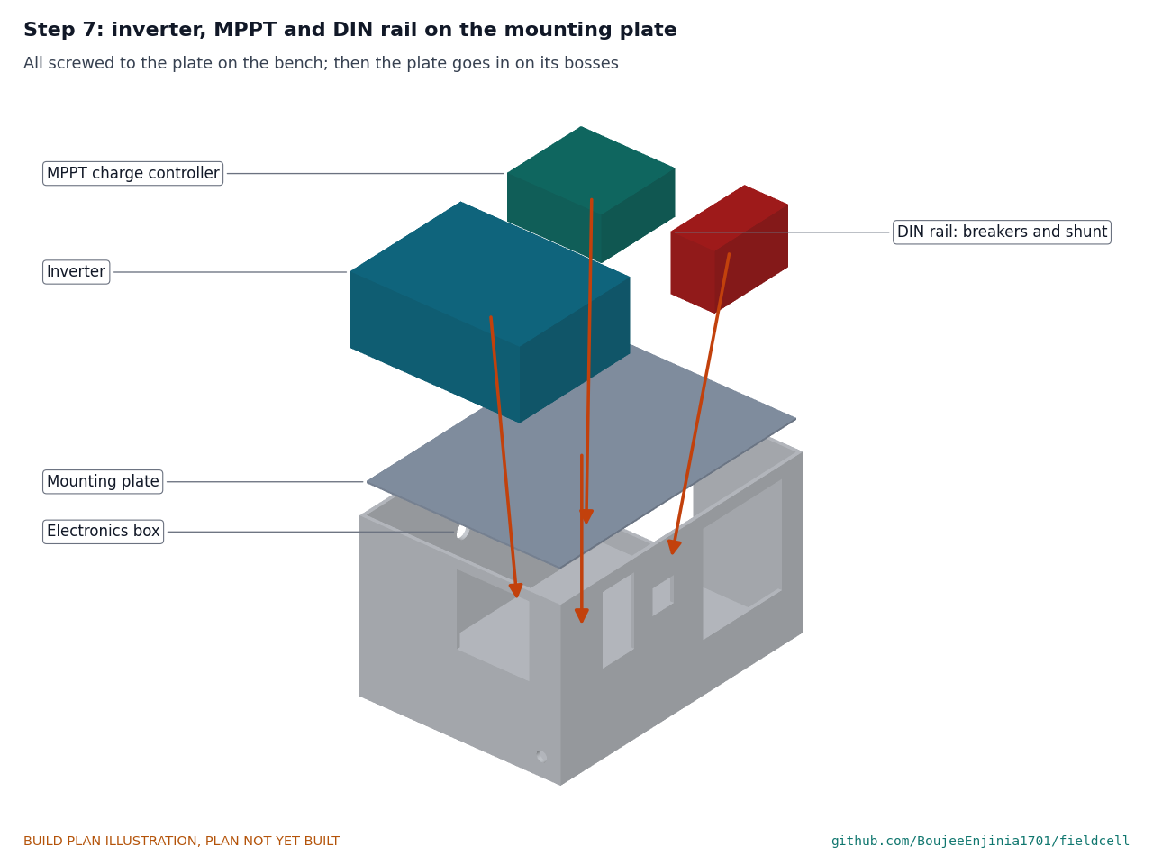
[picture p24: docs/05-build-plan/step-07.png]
Figure 14. Step 7 picture: parts on the mounting plate


*Figure 14. Where each part goes on the mounting plate.*

**How it fits the parts next to it.** The box stands on the deck, its handle-end wall 10 in from the frame end, held by four M6 bolts through the floor and the deck with large washers under the deck. Its two battery glands face the battery case 60 away (Figure 11). The shade uprights stand 28 clear of its sides.

**Check before moving on.** Every part sits flat; the lid closes with no wire across its seal.

#### 3.6.1 Wiring

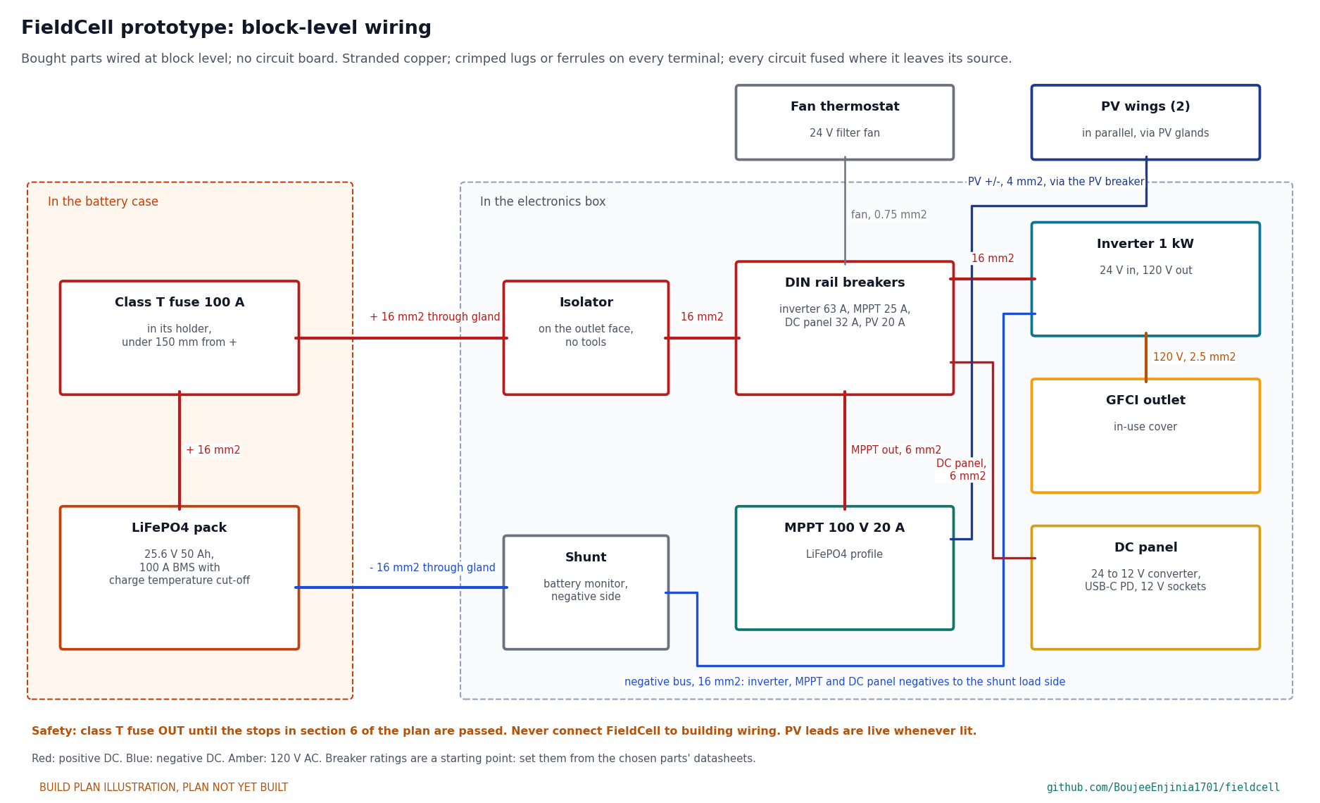
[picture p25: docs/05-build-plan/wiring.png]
Figure 15. Block-level wiring


*Figure 15. Block-level wiring with wire sizes.*

Wire it like this, with stranded copper and a crimped lug or ferrule on every terminal:

1. Pack positive to the class T fuse holder (fuse out): 16 mm² (6 AWG), under 150 long.
2. Fuse holder through a battery gland to the isolator on the outlet face: 16 mm².
3. Isolator to the DIN rail busbar: 16 mm².
4. Inverter breaker to the inverter positive: 16 mm².
5. Pack negative through the other battery gland to the battery side of the shunt: 16 mm².
6. Shunt load side to a negative bus; inverter, charge controller and DC panel negatives to that bus: 16 mm² for the inverter, 6 mm² for the others.
7. Charge controller output through its breaker to the busbar: 6 mm².
8. DC panel (24 to 12 V converter, USB-C modules, 12 V sockets) through its breaker: 6 mm².
9. Inverter AC output to the GFCI outlet: 2.5 mm² (14 AWG), green-yellow earth to the frame only as the inverter maker specifies.
10. Each wing's leads through its PV gland, joined in parallel at the PV breaker, then to the charge controller input: 4 mm².
11. Fan thermostat and filter fan from a 24 V breaker: 0.75 mm².

Set every breaker from the datasheets of the parts you bought; the ratings in Figure 15 are a starting point.

**Check before moving on.** Every wire continuous end to end; with the fuse out, the busbar reads open to the negative bus; every wire labelled.

### 3.7 Wing frames, modules and hinges (make 2)

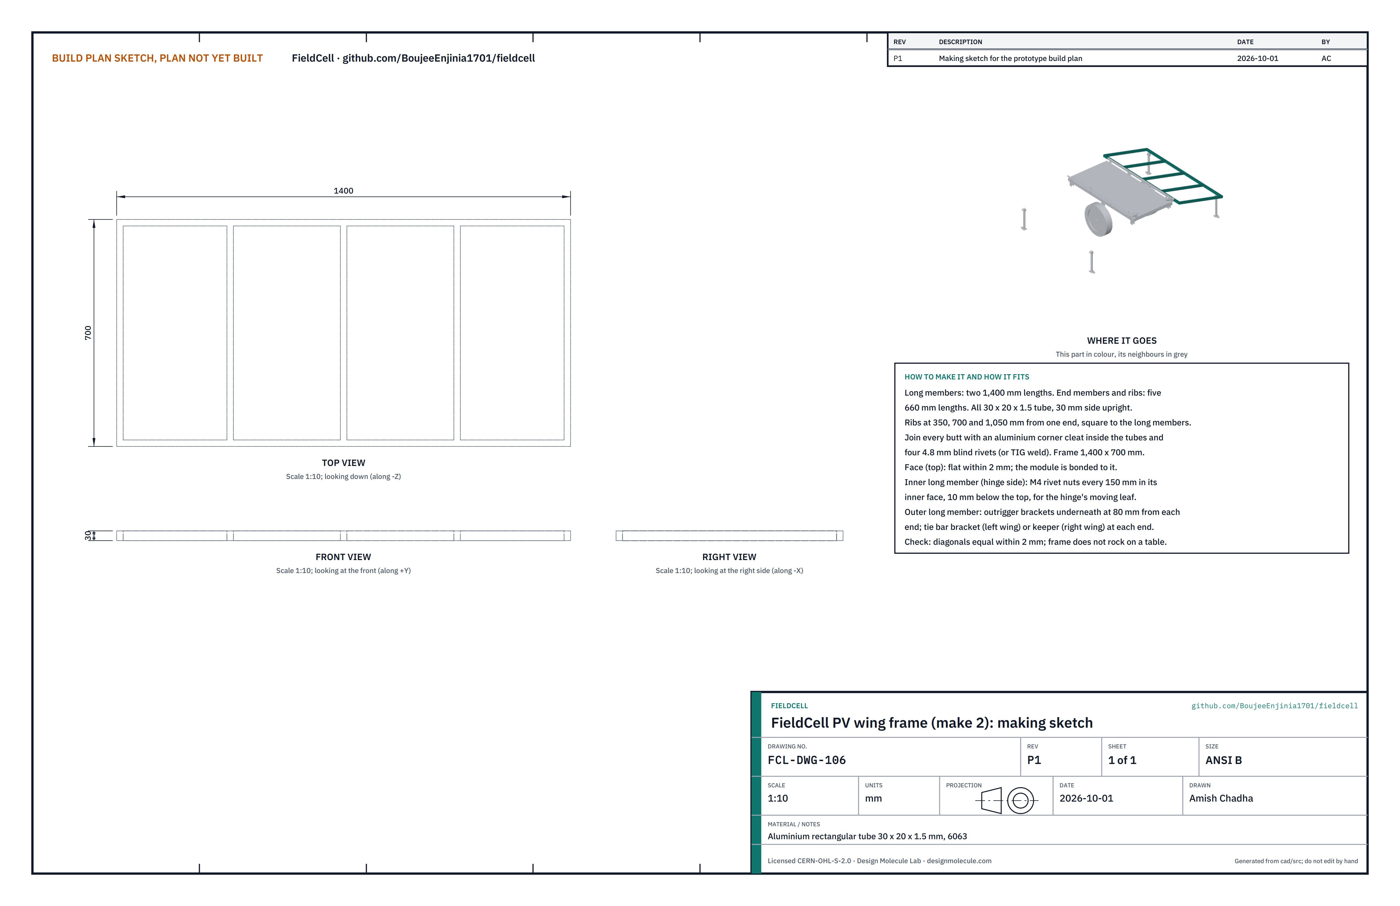
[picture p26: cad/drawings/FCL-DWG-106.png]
Figure 16. Making sketch of the wing frame


*Figure 16. Wing frame making sketch (FCL-DWG-106).*

**What it is and what it is made from.** Each wing is a 200 W semi-flexible solar module bonded to a light frame. Aluminium rectangular tube 30 x 20 x 1.5 mm (6063 class), aluminium corner cleats, 4.8 mm blind rivets, structural bonding tape.

**How to make it.**

1. Cut two long members 1,400 and five cross members 660 (two ends, three ribs), the 30 side upright.
2. Lay them out flat: ribs at 350, 700 and 1,050 from one end. Fit a corner cleat inside each butt joint and rivet with four rivets (or TIG weld). Frame 1,400 x 700.
3. Inner long member (the hinge side): M4 rivet nuts every 150 in its inner face, 10 below the top.
4. Clean the top faces, lay structural tape on every member, and lay the module on from one end, centred with a 10 rim all round, rolling it down as you go (step 11).
5. Screw the hinge's moving leaf to the inner member's rivet nuts with M4 screws, knuckle toward the top face.

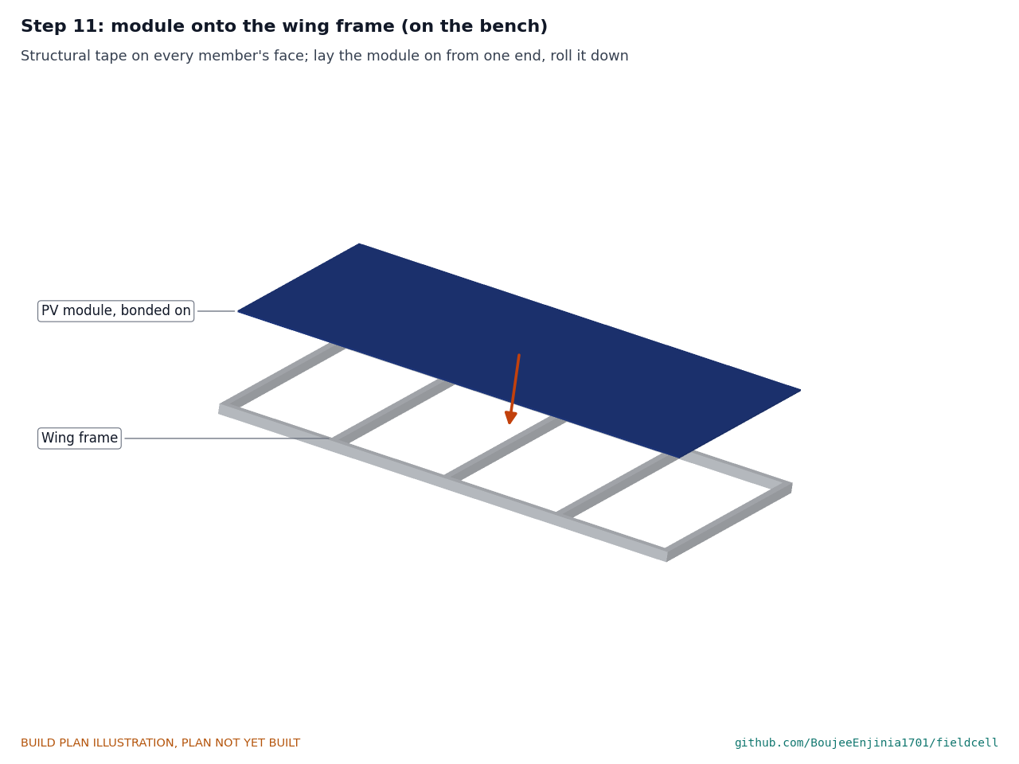
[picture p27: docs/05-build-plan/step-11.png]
Figure 17. Step 11 picture: module onto the wing frame


*Figure 17. The module goes on the frame's top faces.*

**How it fits the parts next to it.** The hinge's fixed leaf screws to the spacer angle (Figure 9) with M4 countersunk screws every 150, nyloc nuts beneath. The hinge pin is 4.5 above the panel face, so the knuckle clears the module; folded out, the wing's underside passes 28 over the tyre and its outer edge is 309 above the ground.

**Check before moving on.** The frame's diagonals are equal within 2 mm and it does not rock on a table; the module is bonded flat with no bubbles over the members.

### 3.8 Outrigger legs and brackets (make 4)

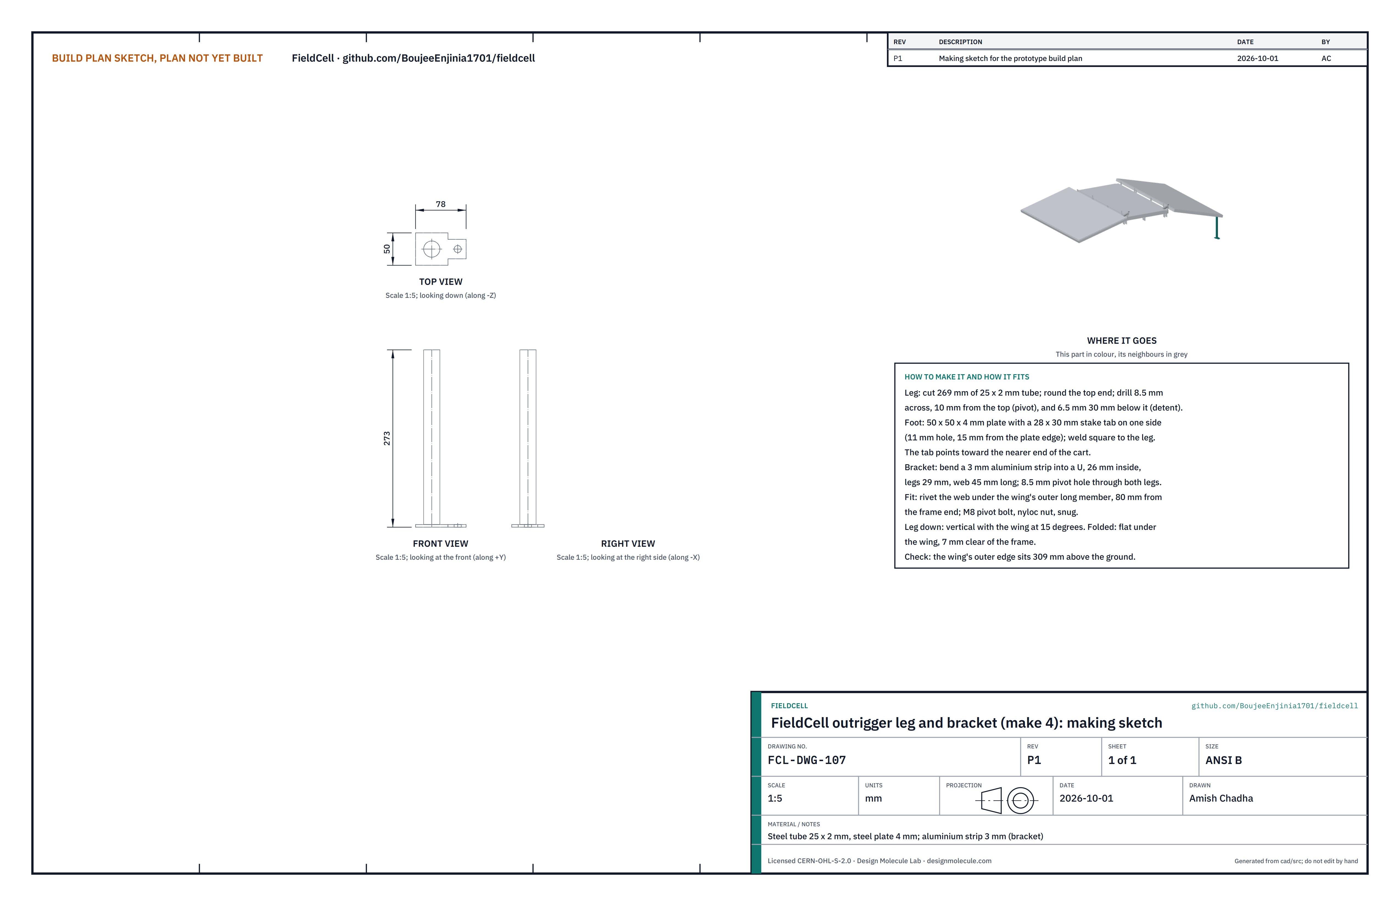
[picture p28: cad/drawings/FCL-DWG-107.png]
Figure 18. Making sketch of the outrigger leg


*Figure 18. Outrigger leg making sketch (FCL-DWG-107).*

**What it is and what it is made from.** Two legs under each wing's outer edge that set the 15° tilt and take a stake each. Steel tube 25 x 2 mm, 4 mm plate, and a 3 mm aluminium strip for the bracket.

**How to make it.**

1. Cut four 269 lengths of tube; round one end; drill 8.5 across 10 from that end (pivot) and 6.5 across 30 below it (detent).
2. Feet: 50 x 50 x 4 plates with a 28 x 30 tab on one side, 11 hole 15 from the plate edge; weld square on the leg, tab pointing toward the nearer end of the cart.
3. Brackets: bend a 3 aluminium strip into a U 26 inside, legs 29 deep, web 45 long; drill 8.5 through both legs.

**How it fits the parts next to it.**

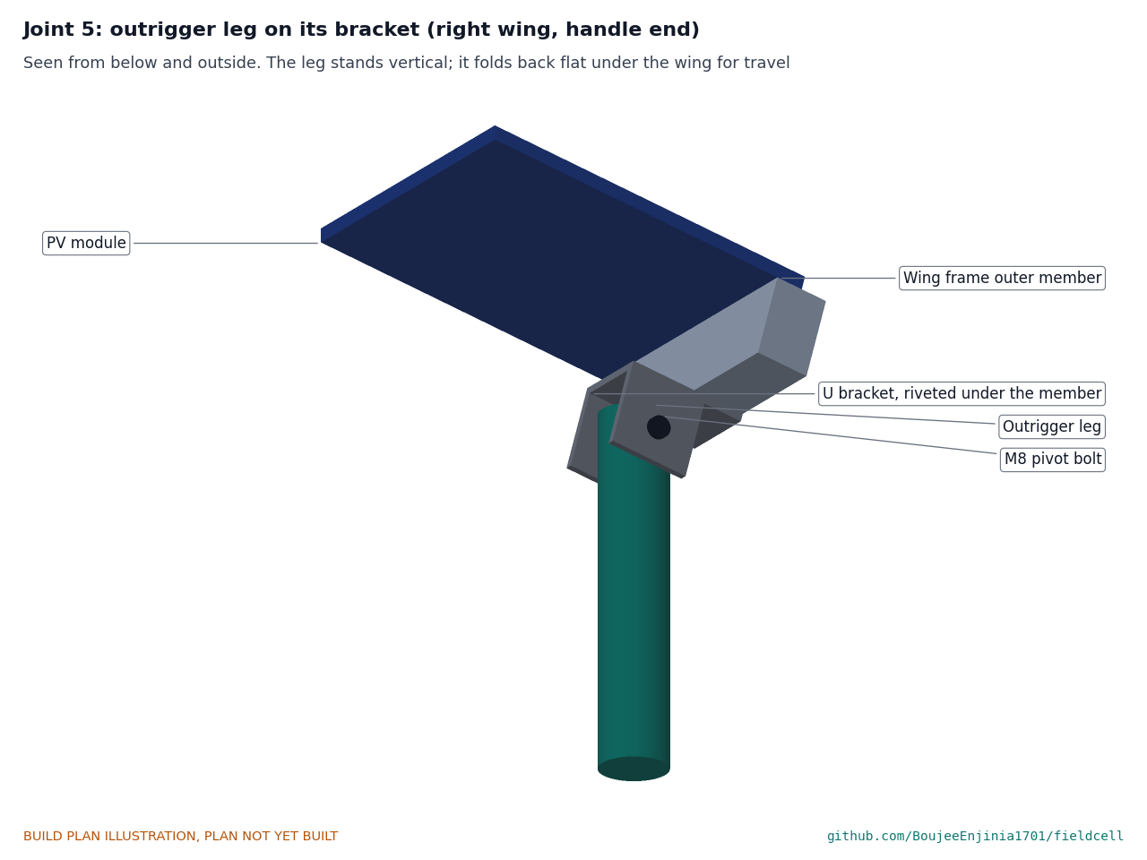
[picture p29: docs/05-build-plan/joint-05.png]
Figure 19. Joint 5: outrigger leg on its bracket


*Figure 19. The U bracket is riveted under the wing's outer member; the leg turns on an M8 bolt.*

The bracket web is riveted under the outer long member, 80 from each end of the frame (step 12). M8 bolt, nyloc nut, snug. Down, the leg is vertical with the wing at 15°; folded, it lies flat under the wing 7 clear of the frame, its foot lying flat too.

**Check before moving on.** Legs down on a flat floor, the wing's outer edge is 309 above the floor at both ends.

### 3.9 Tie bars (make 2)

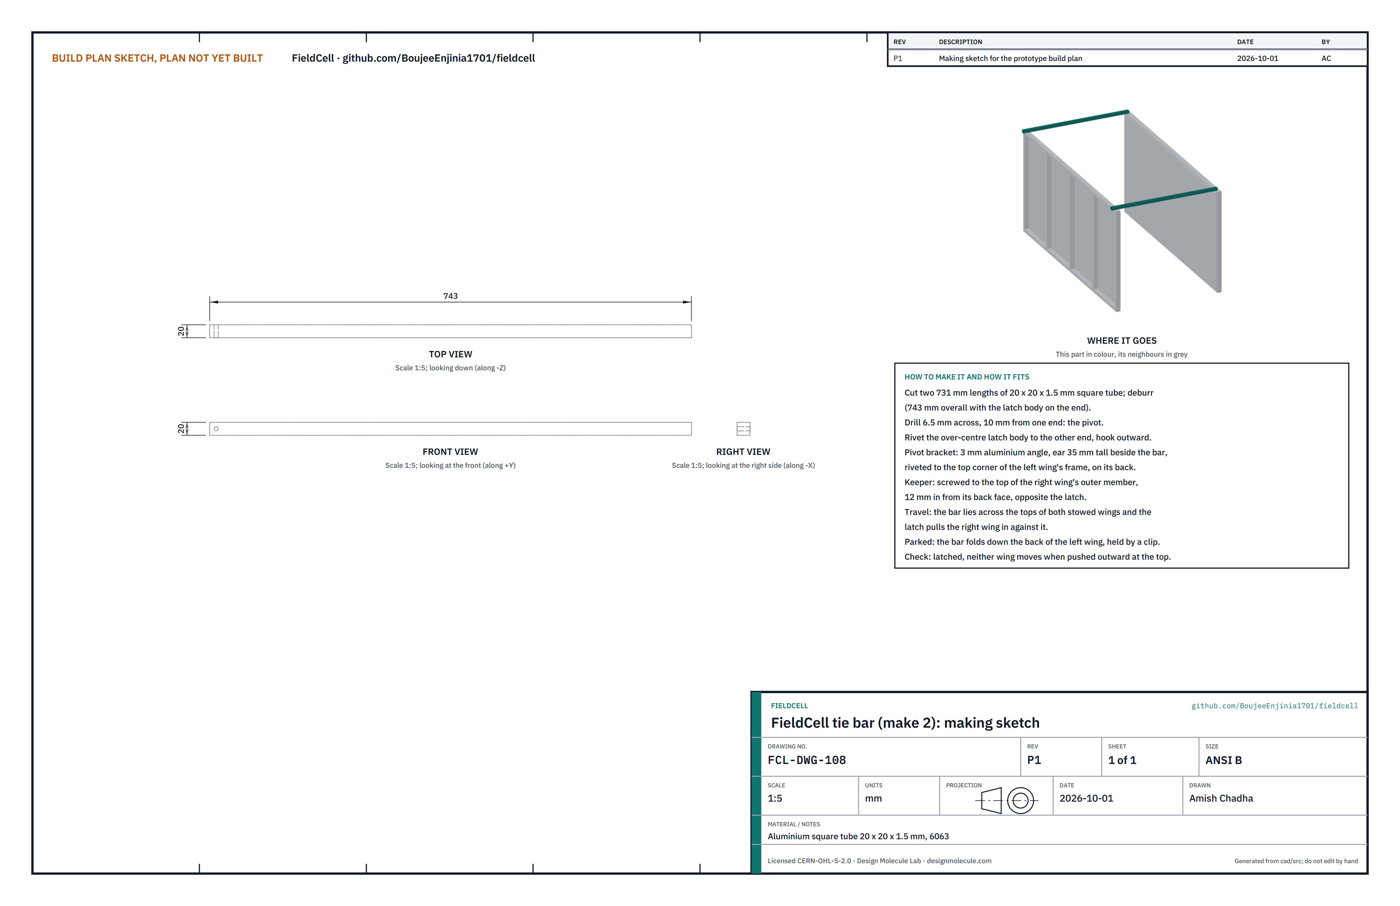
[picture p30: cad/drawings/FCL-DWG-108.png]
Figure 20. Making sketch of the tie bar


*Figure 20. Tie bar making sketch (FCL-DWG-108).*

**What it is and what it is made from.** One bar at each end of the cart that holds the two stowed wings together at the top. Aluminium square tube 20 x 20 x 1.5 mm, a 3 mm aluminium pivot bracket, an over-centre latch and keeper.

**How to make it.**

1. Cut two 731 lengths; drill 6.5 across 10 from one end.
2. Rivet the latch body to the other end, hook outward (743 overall).
3. Pivot brackets: rivet one to the back of the left wing frame at each top corner (the outer member's end, beside the end member), its ear standing 35 above the frame top, beside where the bar lies. M6 bolt and nyloc nut through the ear and the bar, snug so the bar swings.
4. Keepers: screw one to the top of the right wing's outer member at each end, opposite the latch.

**How it fits the parts next to it.**

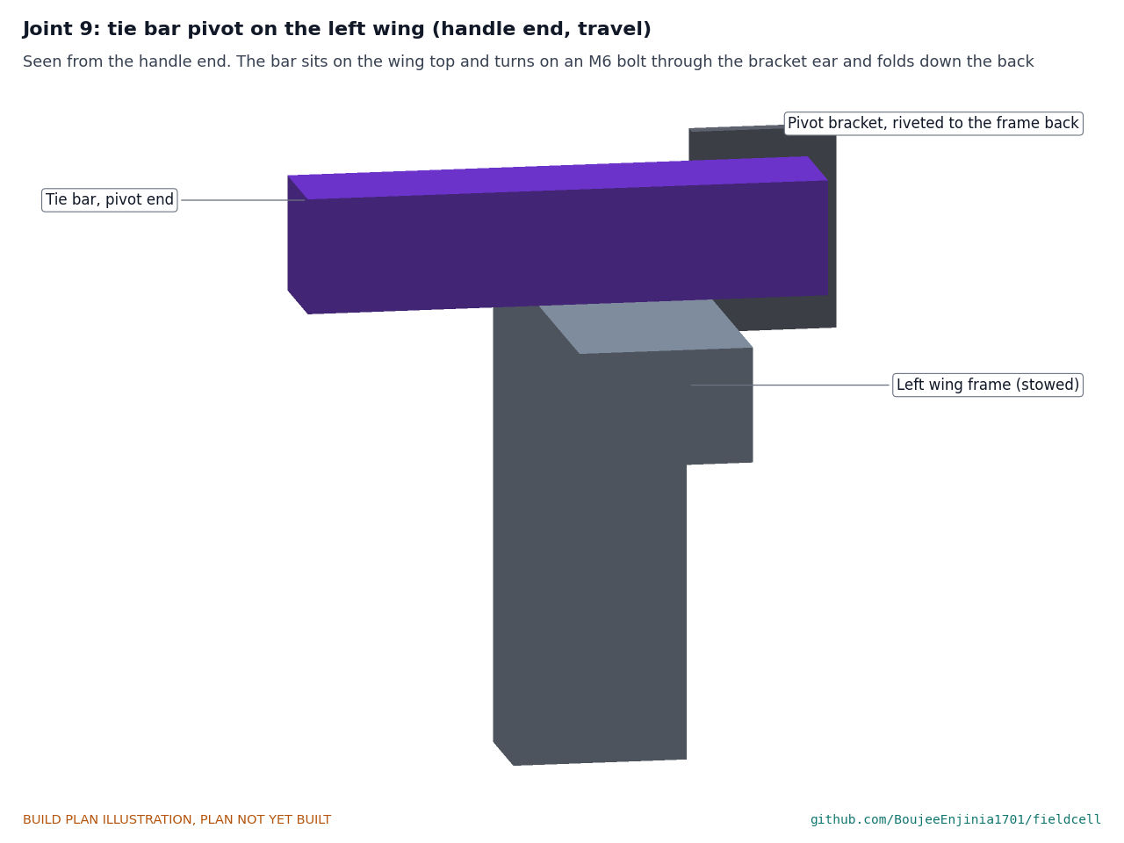
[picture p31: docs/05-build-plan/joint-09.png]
Figure 21. Joint 9: tie bar pivot on the left wing


*Figure 21. The bar sits on the wing top and turns on the bracket ear.*

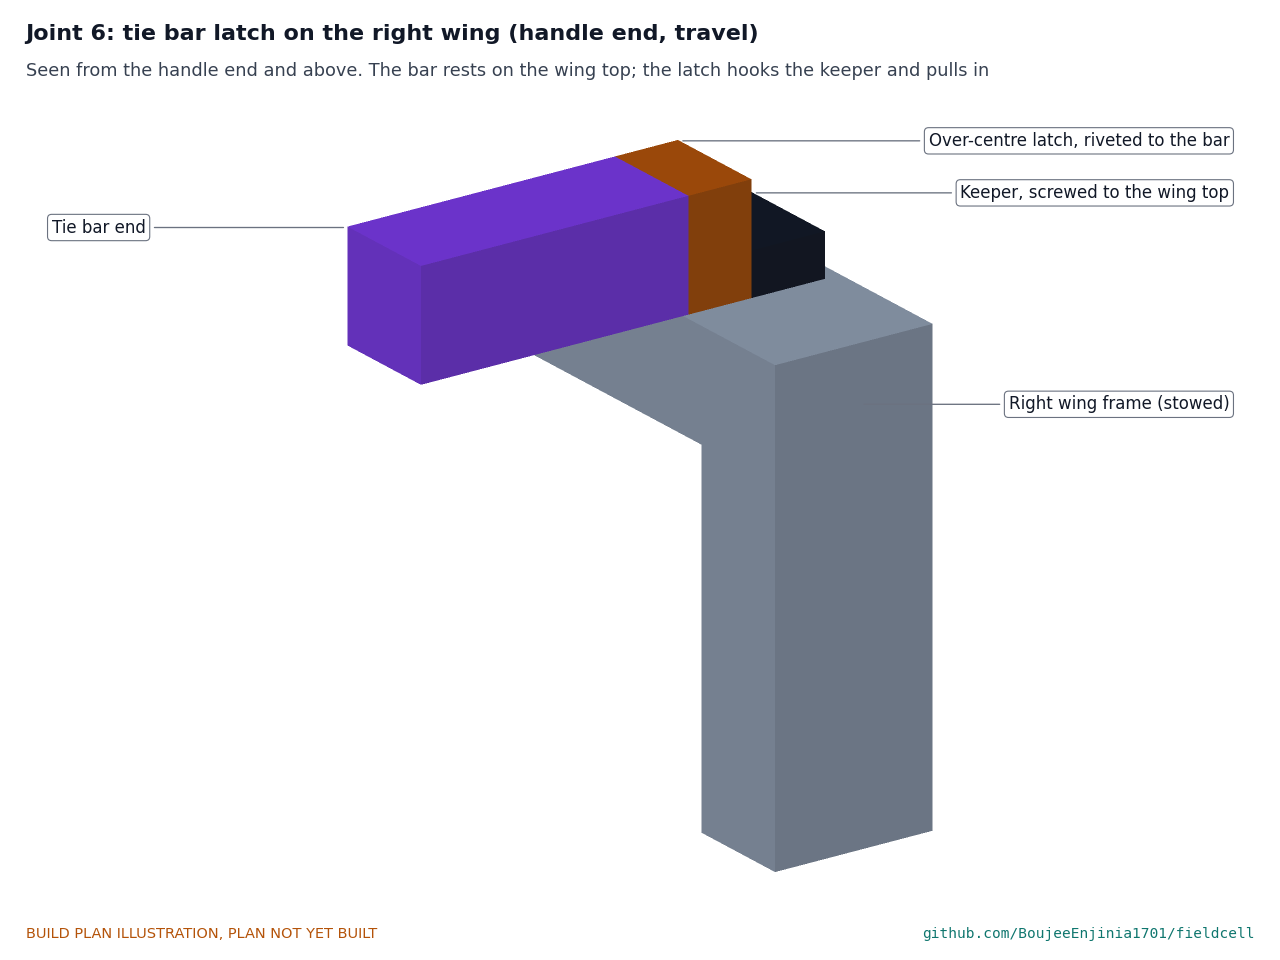
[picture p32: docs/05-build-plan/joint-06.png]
Figure 22. Joint 6: tie bar latch on the right wing


*Figure 22. The latch hooks the keeper and pulls the right wing in against the bar.*

In travel the bar lies across the tops of both stowed wings and the latch pulls them together; nothing presses on the solar faces, which face each other inside. Parked, the bar swings up and over and lies down the back of the left wing, held by a spring clip.

**Check before moving on.** Latched, neither wing moves when pushed outward at its top corner.

### 3.10 Sun shade frame and uprights

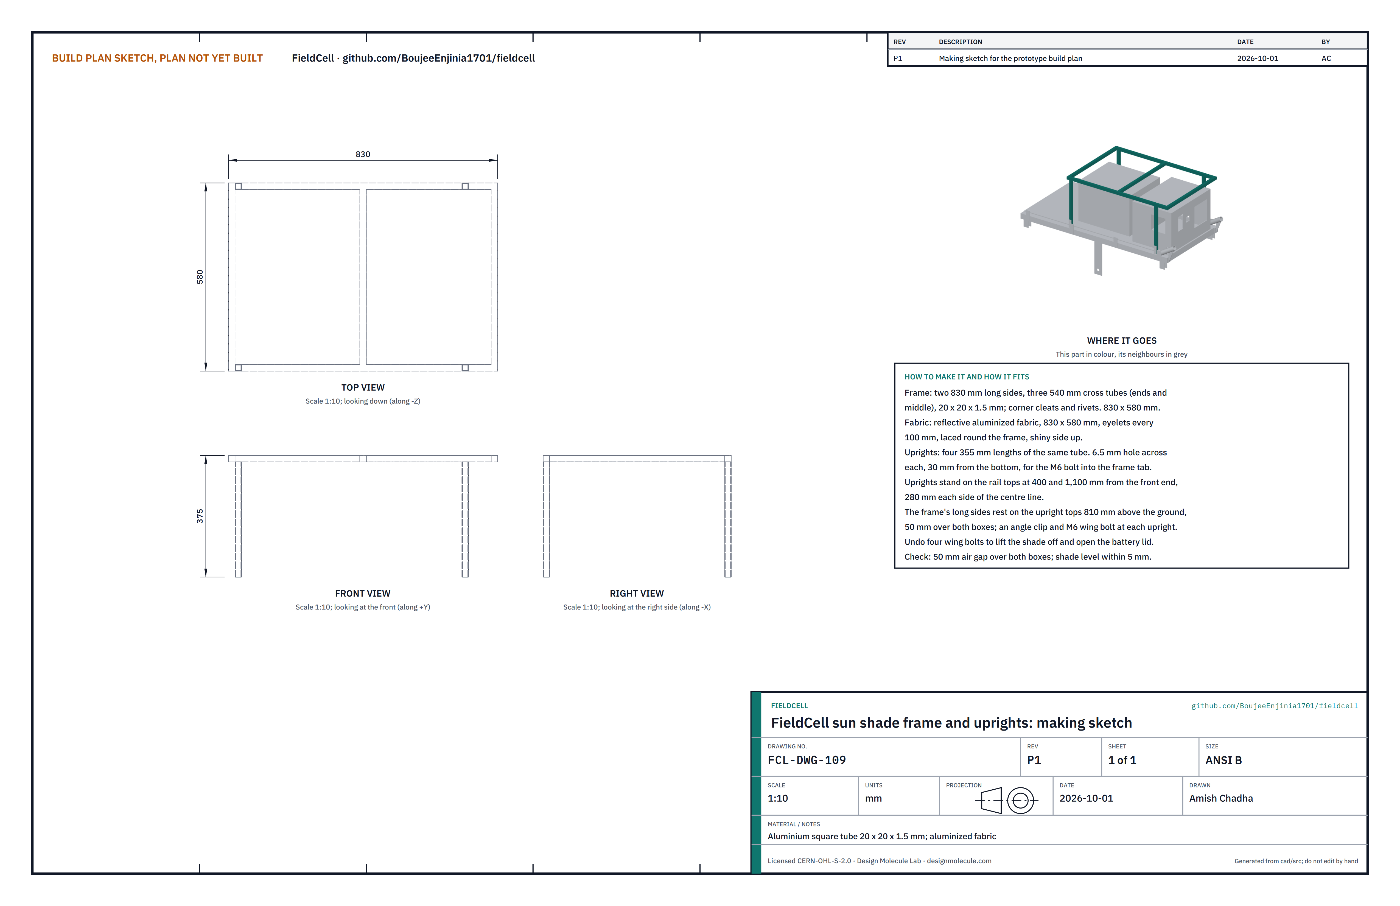
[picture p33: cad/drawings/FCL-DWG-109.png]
Figure 23. Making sketch of the shade frame and uprights


*Figure 23. Shade making sketch (FCL-DWG-109).*

**What it is and what it is made from.** A reflective shade 50 above both boxes, on four uprights. Aluminium square tube 20 x 20 x 1.5 mm and reflective aluminized fabric with eyelets.

**How to make it.**

1. Frame: two 830 sides and three 540 cross tubes (ends and middle); corner cleats and rivets; 830 x 580 outside.
2. Lace the fabric round the frame, shiny side up.
3. Uprights: four 355 lengths with a 6.5 hole 30 from the bottom.
4. Rivet a small 20 x 20 angle clip under each long side tube where it meets an upright, with a 6.5 hole for a wing bolt.

**How it fits the parts next to it.**

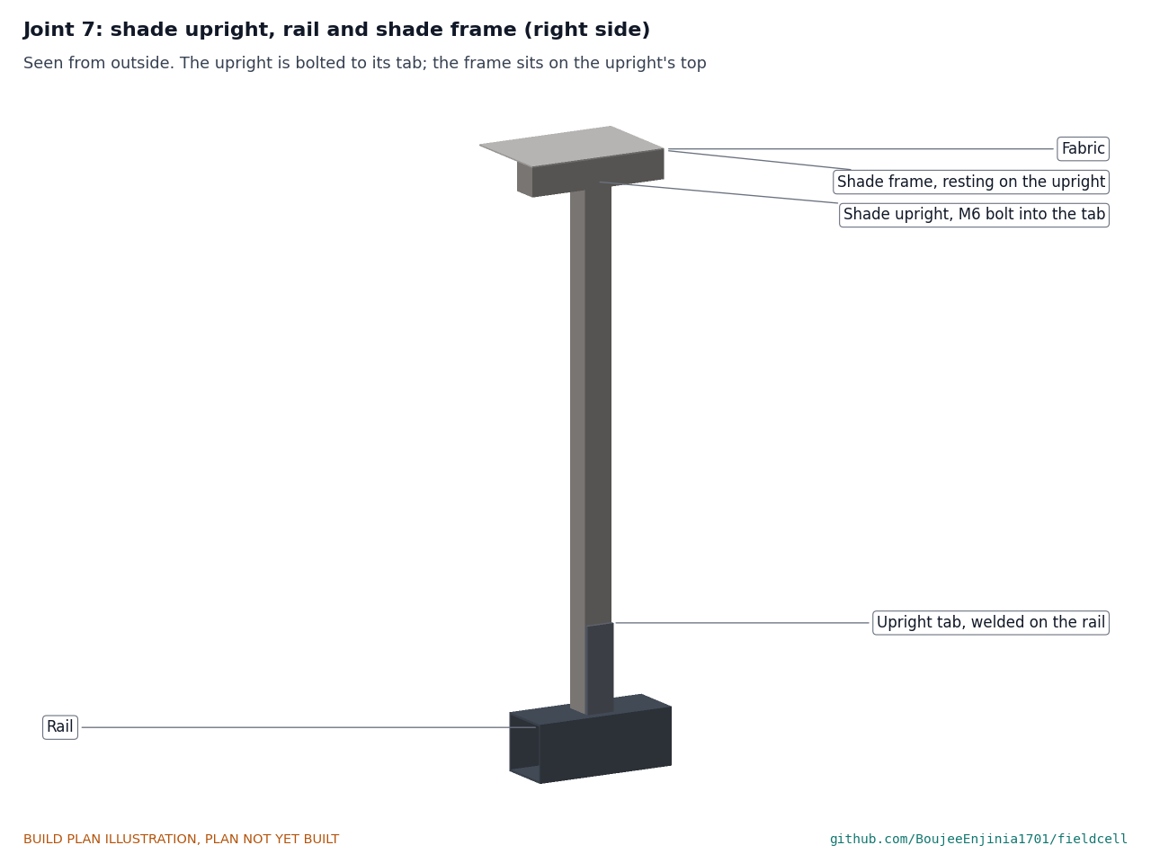
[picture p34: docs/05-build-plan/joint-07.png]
Figure 24. Joint 7: shade upright on its tab


*Figure 24. The upright stands on the rail top, bolted to its tab; the shade frame rests on its top.*

Each upright stands on the rail top against its tab, M6 bolt through both. The shade frame's long sides rest on the four upright tops, 810 above the ground, held by an M6 wing bolt through each clip and upright. Undo four wing bolts to lift the shade off and open the battery case.

**Check before moving on.** The shade is level within 5 and 50 clear of both boxes.

### 3.11 Handle

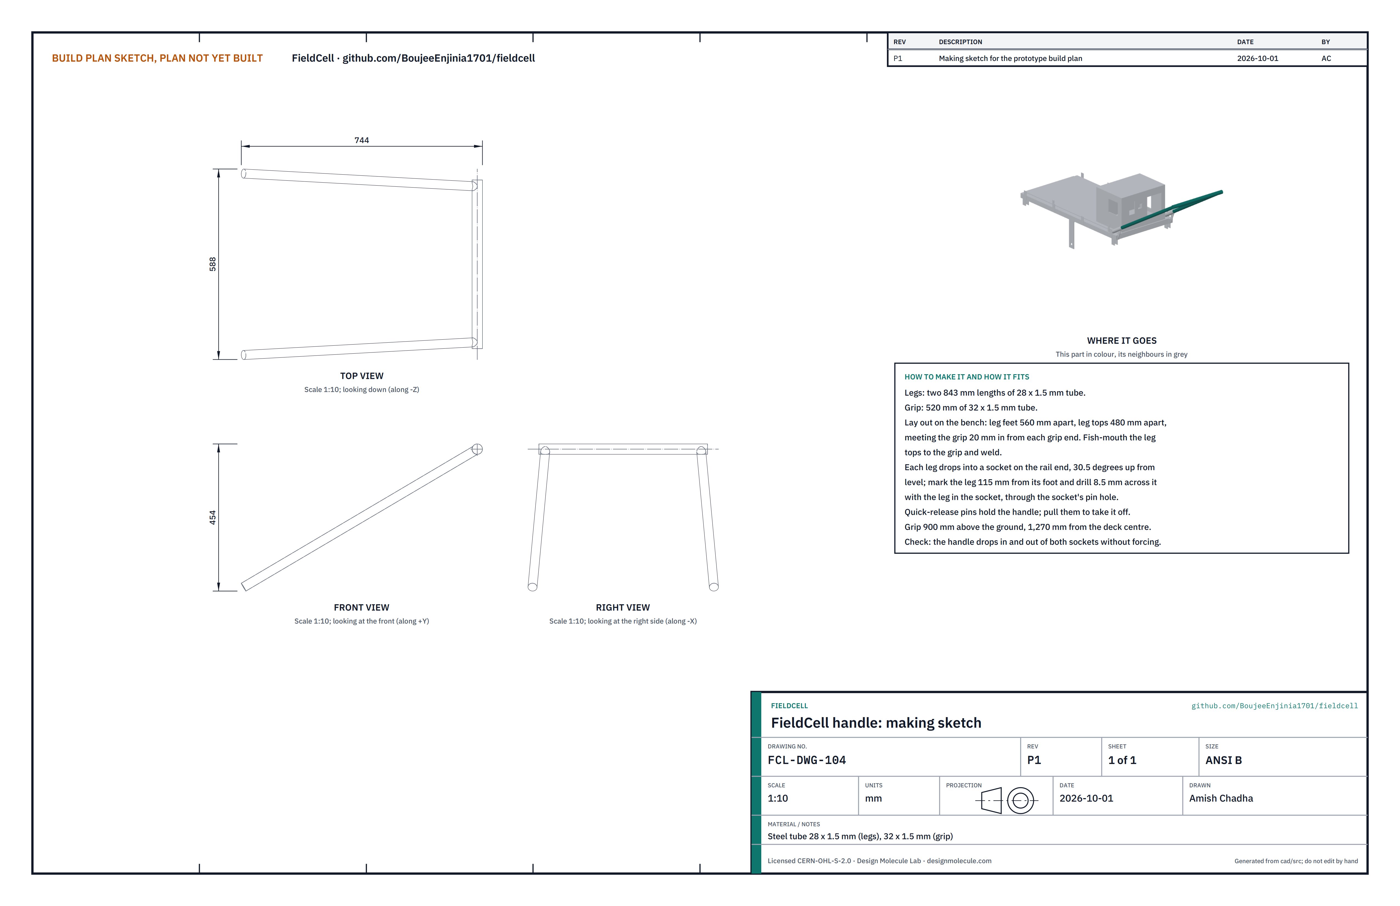
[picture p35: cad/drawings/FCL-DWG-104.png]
Figure 25. Making sketch of the handle


*Figure 25. Handle making sketch (FCL-DWG-104).*

**What it is and what it is made from.** The detachable T-handle. Steel tube 28 x 1.5 mm (legs) and 32 x 1.5 mm (grip), foam grip.

**How to make it.**

1. Cut two legs 843 and a grip 520.
2. Lay out on the bench: leg feet 560 apart, leg tops 480 apart, meeting the grip 20 in from each grip end. Fish-mouth the leg tops, weld, clean up, paint, fit the foam grip.
3. With the legs in the sockets, drill 8.5 across each leg through the socket's pin hole.

**How it fits the parts next to it.**

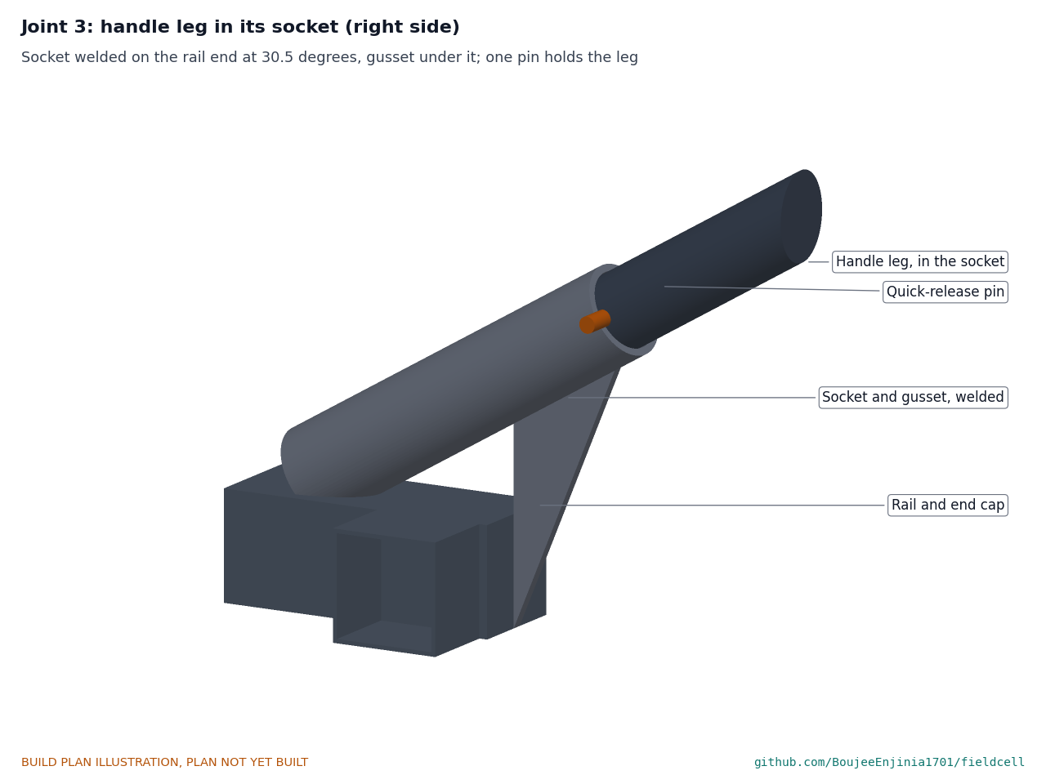
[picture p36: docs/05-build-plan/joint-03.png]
Figure 26. Joint 3: handle leg in its socket


*Figure 26. The leg drops into the welded socket; one quick-release pin holds it.*

**Check before moving on.** The handle drops in and lifts out of both sockets without forcing; the grip is 900 above the ground.

### 3.12 Bought components

Buy to specification, not brand. Line numbers are those of the bill of materials.

- **Wheels (line 2).** Two 16 in (406 mm) flat-free tyres on steel rims, 20 mm bore with bearings, hub about 60 long, about 90 wide, 100 kg or more each; with a spacer collar (26 outside, 20 bore, 37.5 long), a 20 washer and a linch pin each.
- **Battery case (line 5).** IP65 case about 420 x 360 x 300 outside, with a pressure vent and a flat end wall for two glands. Drill as section 3.5.
- **Pack (line 6).** 25.6 V 50 Ah lithium iron phosphate, about 330 x 175 x 220, with a 100 A battery management system that blocks charging below 0 °C and above 45 °C.
- **Electronics box (line 7).** IP54 polycarbonate box about 320 x 460 x 300 with lid and mounting plate; IP54 24 V filter fan (about 40 m³/h) with thermostat and a matching exhaust filter. Cut as section 3.6.
- **Charge controller (line 8).** 100 V 20 A MPPT for a 24 V battery, lithium iron phosphate profile, about 150 x 140 x 70.
- **Inverter (line 9).** 1,000 W pure sine, 2,000 W surge, 24 V in, 120 V 60 Hz out, 10 W or less no-load draw, about 270 x 210 x 110.
- **DC panel (line 10) and AC outlet (line 11).** Two 100 W USB-C PD modules, two 12 V sockets and a 24 to 12 V 20 A converter on a sealed panel; a GFCI duplex outlet with an in-use cover.
- **Fusing (line 12).** Class T 100 A fuse and holder; battery isolator for panel mounting; DIN rail breakers for the inverter, charge controller, DC panel and PV; shunt battery monitor.
- **Solar modules (line 13).** 200 W semi-flexible, Vmp 36 V or more at standard test conditions, no larger than 1,380 x 680, with leads long enough to reach the electronics box along the hinge line.
- **Hinges and latches (line 14).** Two stainless piano hinges cut to 1,200, leaves about 26 wide and 1.5 thick; two over-centre latches with keepers.
- **Bin (line 16).** Open plastic bin about 320 x 460 x 240 with a tie-down strap.
- **Wiring and hardware (line 17).** 16 mm² battery cable with lugs; four M25 and two M16 glands; 4 mm² PV cable and connectors; two cam straps; M4, M5, M6, M8 and M10 bolts with nyloc nuts; M4 rivet nuts; 4.8 mm blind rivets; structural bonding tape; foam blocks and a rubber mat.

## 4. Putting it together

In each picture the parts already fitted are grey and the part being fitted is in colour, with an arrow showing the way it goes in.

### Step 1: axle through the brackets

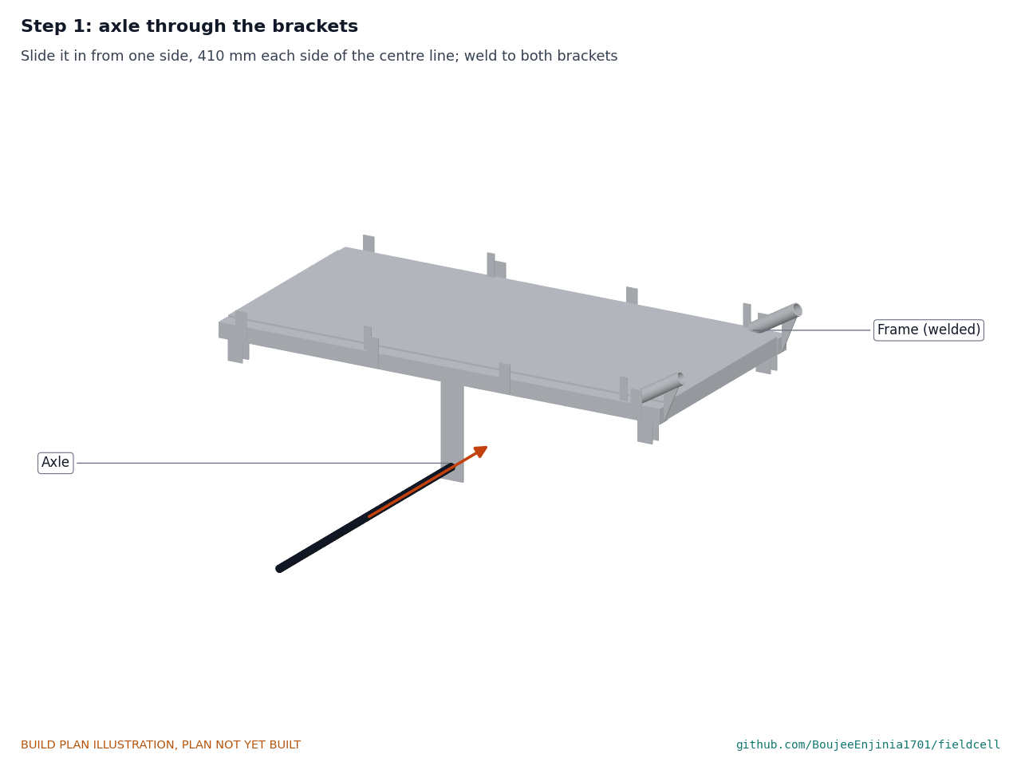
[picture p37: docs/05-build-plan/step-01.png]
Step 1


Slide the axle through both brackets, 410 each side of the centre line, cross holes vertical; weld to both faces of both brackets.

### Step 2: wheels onto the axle

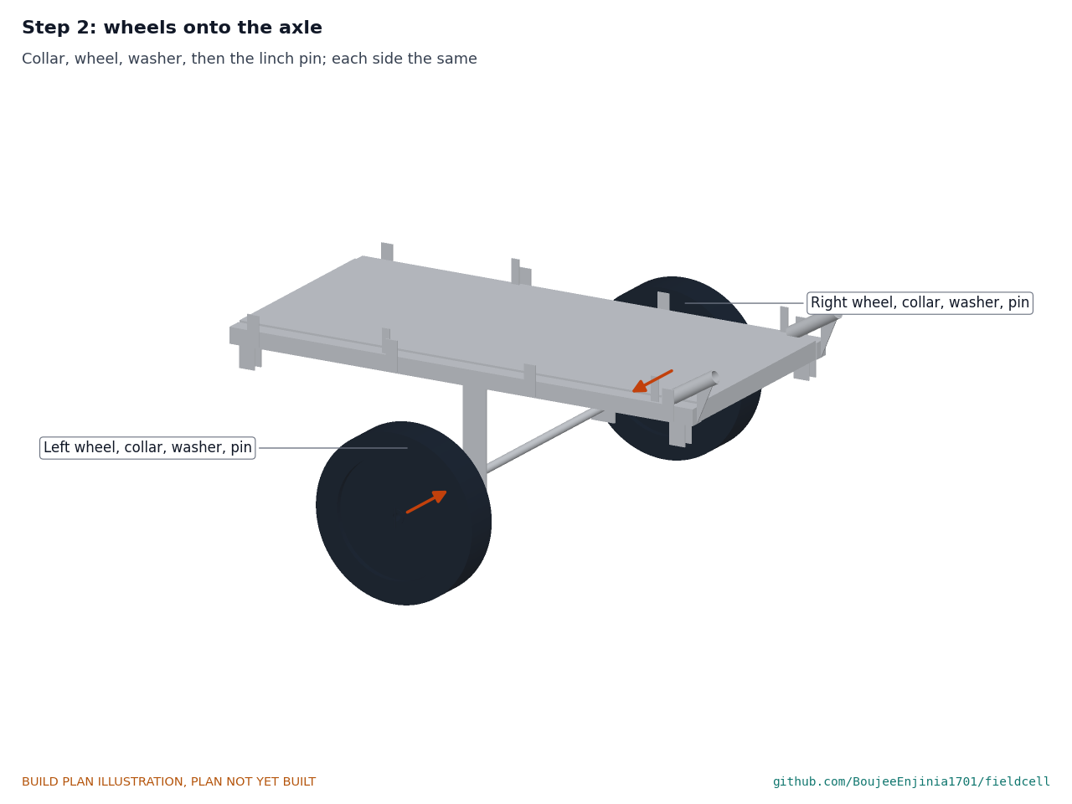
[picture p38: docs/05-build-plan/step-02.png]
Step 2


Collar, wheel, washer, linch pin, each side the same. Grease the bearings if the maker says so.

### Step 3: stand legs into their clevises

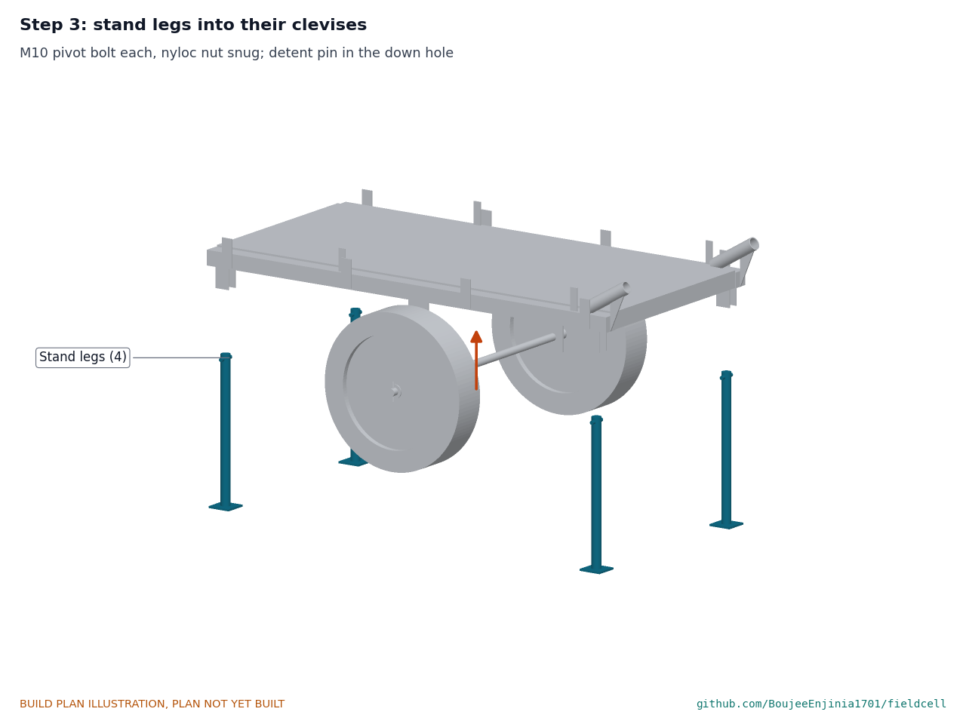
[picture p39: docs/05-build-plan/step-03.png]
Step 3


M10 bolt and nyloc nut each, snug; detent pin in the down holes. The cart now stands level on its own.

### Step 4: hinge spacer angles onto the tabs

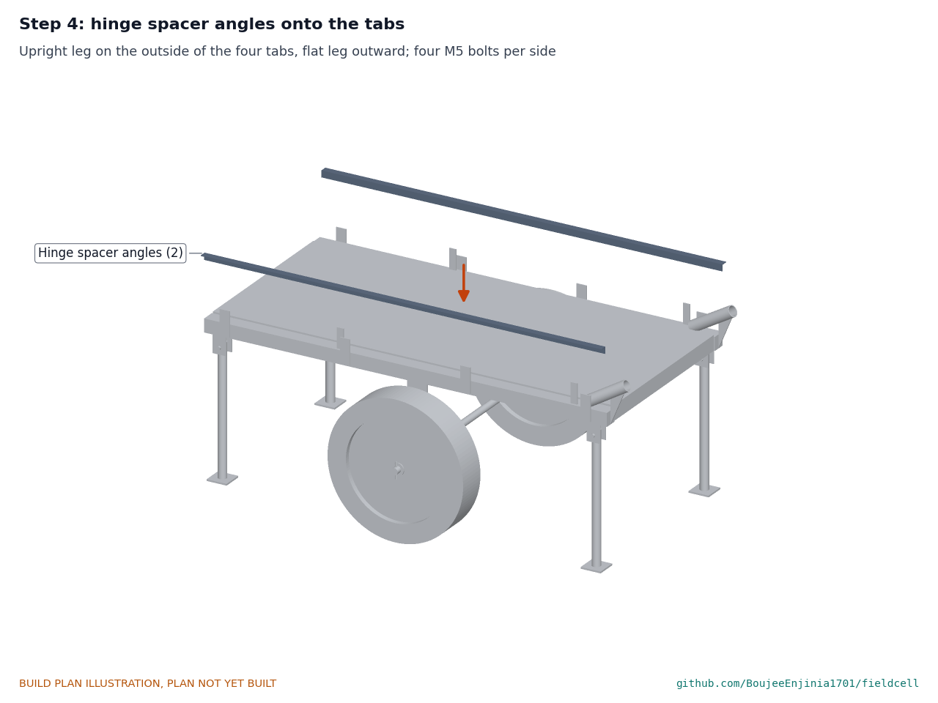
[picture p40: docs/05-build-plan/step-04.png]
Step 4


Upright leg on the outside of the four tabs, flat leg outward and flush with the tab tops; four M5 bolts per side, nyloc nuts inside.

### Step 5: battery case onto the deck

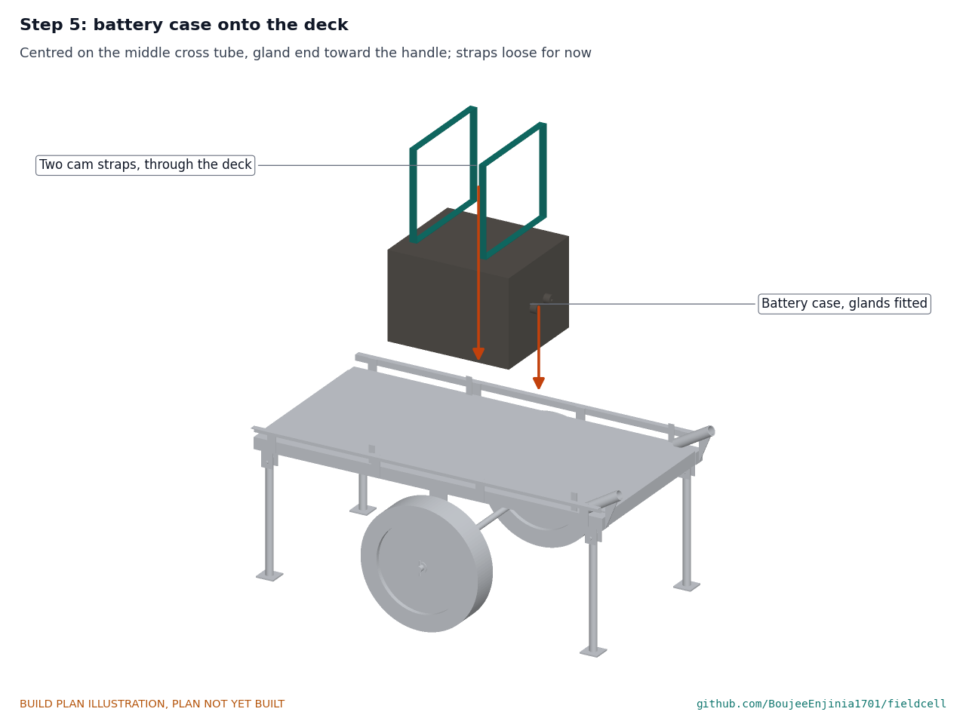
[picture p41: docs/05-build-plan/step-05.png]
Step 5


Glands fitted. Stand the case on the deck centred on the middle cross tube, gland end toward the handle. Pass the two cam straps through the deck and round the case, loose for now.

### Step 6: pack and class T fuse into the case

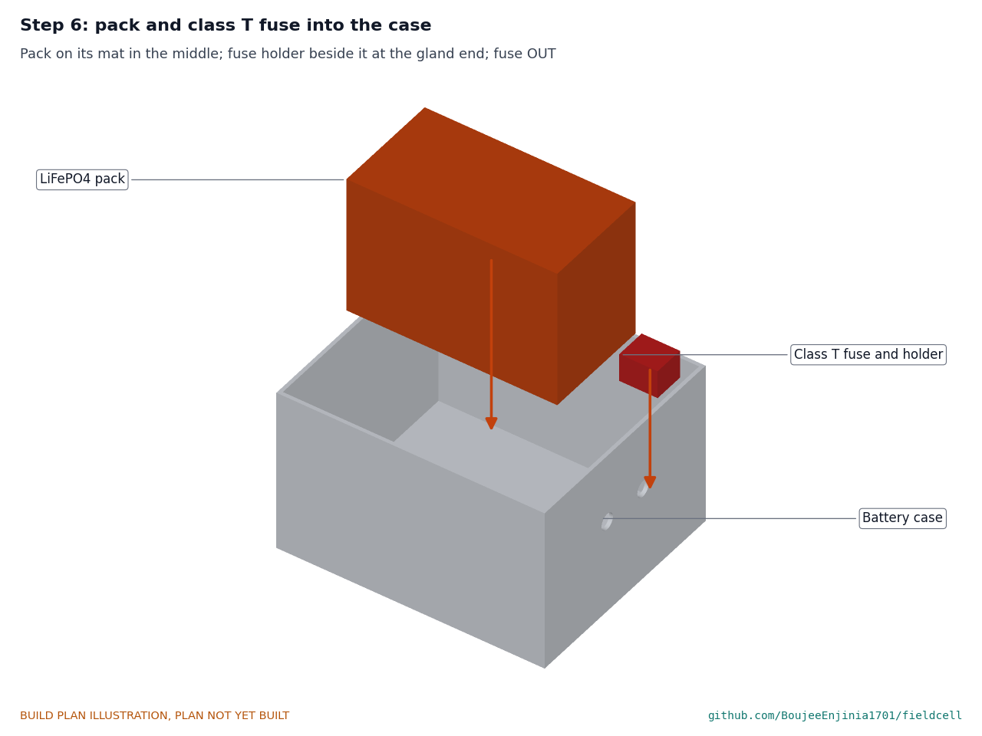
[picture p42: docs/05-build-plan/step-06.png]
Step 6


**Hold point:** safety stop S1. Pack on its mat in the middle of the case; foam blocks round it; fuse holder beside it at the gland end. Connect the short positive lead from the pack to the fuse holder. **The fuse stays out.**

### Step 7: inverter, charge controller and DIN rail on the mounting plate

Step 7

On the bench, screw each part to the plate as Figure 14 shows; then fit the plate into the box on its bosses.

### Step 8: outlets, isolator, fan and exhaust filter

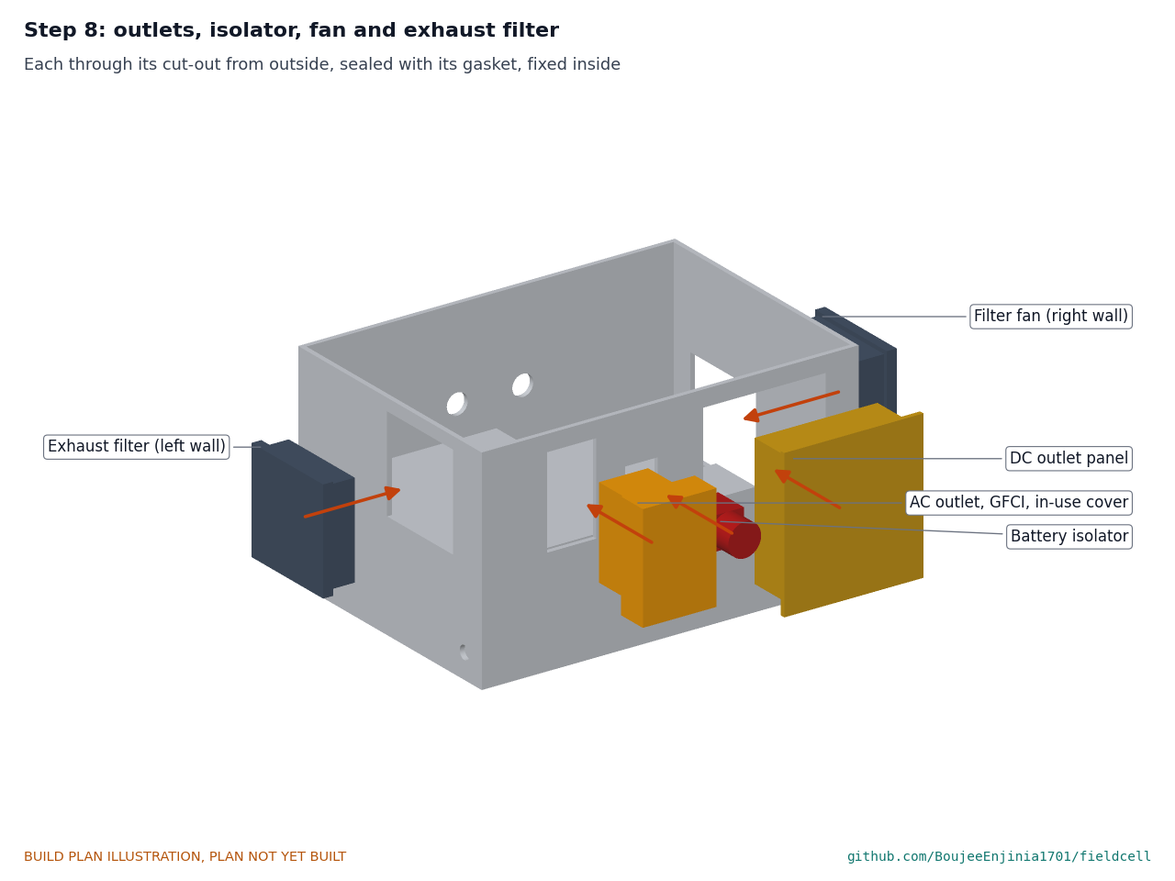
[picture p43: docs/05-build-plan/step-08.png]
Step 8


Each through its cut-out from outside, with its gasket, fixed from inside. Fit the battery and PV glands.

### Step 9: electronics box onto the deck

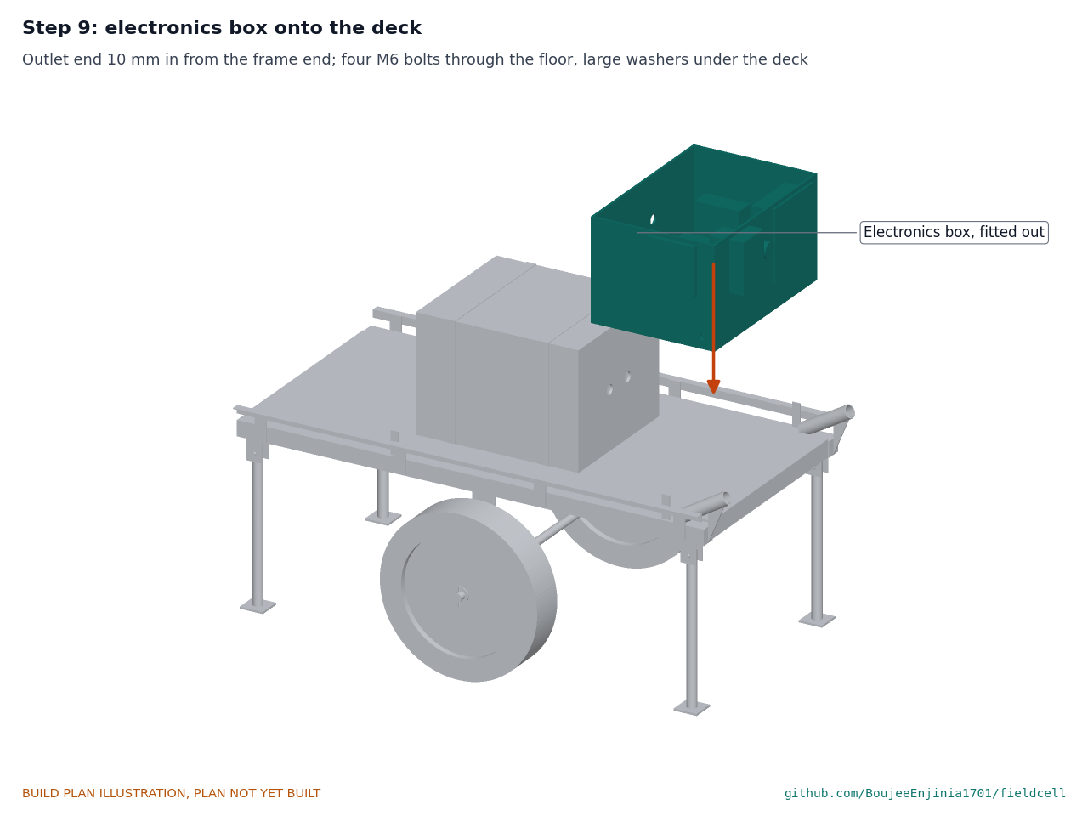
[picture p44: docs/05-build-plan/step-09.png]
Step 9


Handle-end wall 10 in from the frame end, battery glands lined up with the case's. Four M6 bolts through the floor and the deck, large washers under the deck.

### Step 10: battery cables, then the lids

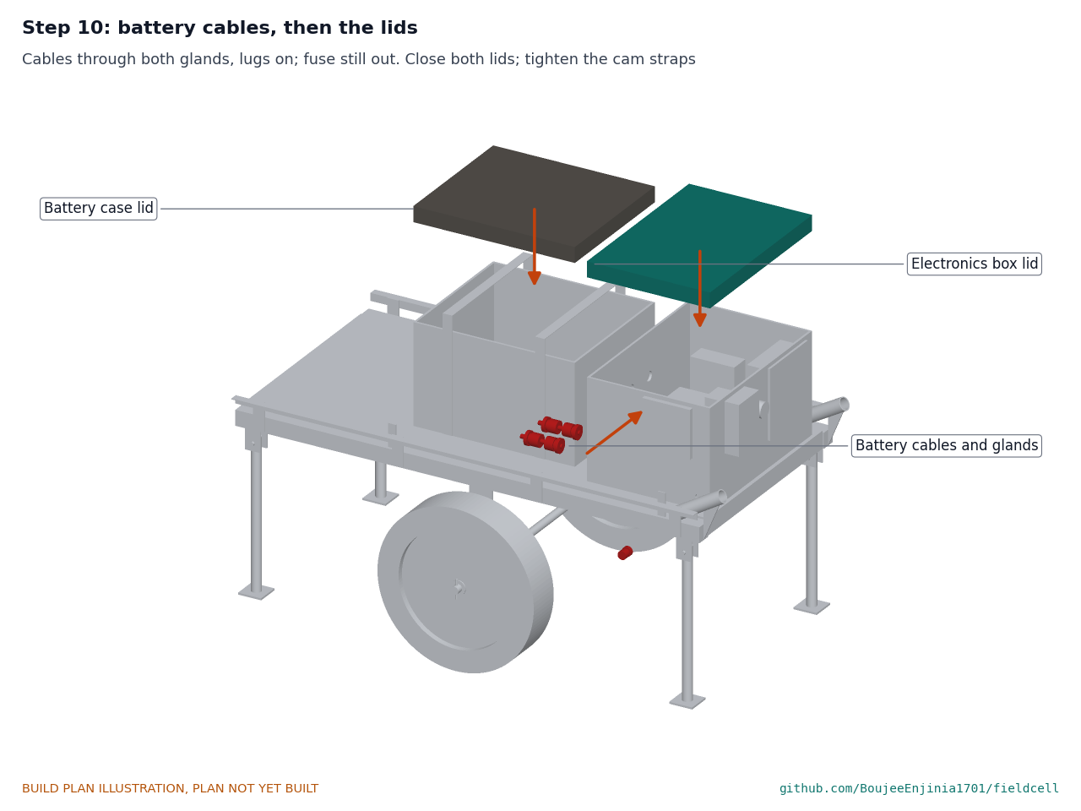
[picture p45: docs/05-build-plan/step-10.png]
Step 10


Pass the two 16 mm² cables through both pairs of glands, crimp the lugs and connect them as section 3.6.1; finish the wiring. Close both lids; tighten the cam straps over the battery lid. **Hold point:** safety stop S2.

### Step 11: module onto each wing frame (on the bench)

Step 11

Structural tape on every member, module on from one end, rolled down; then the moving hinge leaf onto the inner member.

### Step 12: outriggers onto the wings

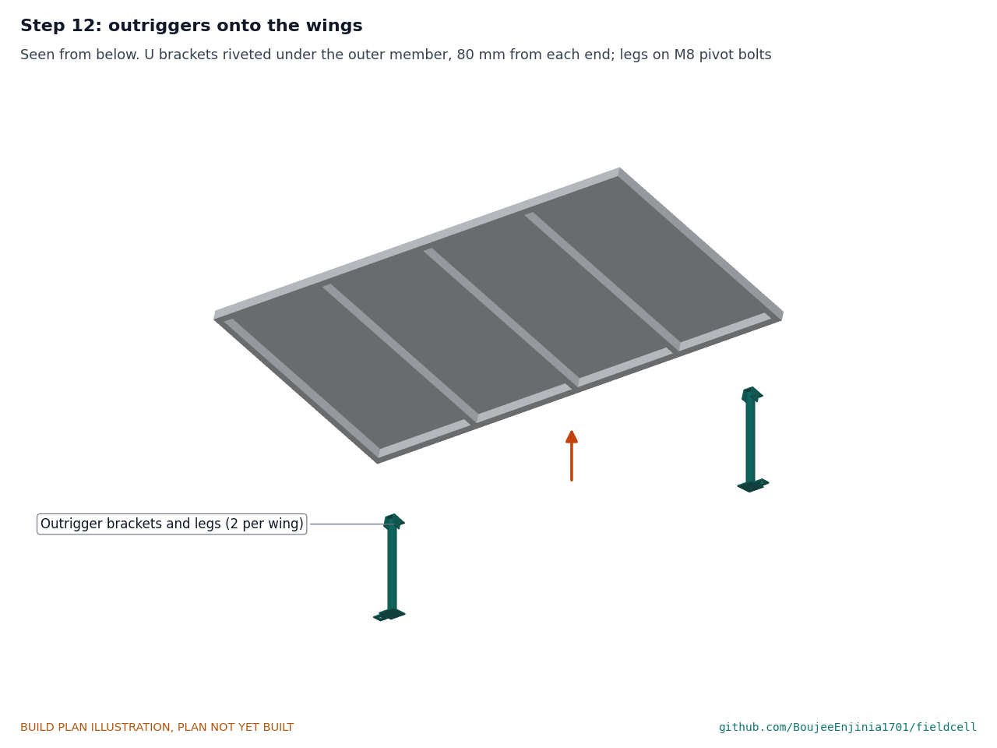
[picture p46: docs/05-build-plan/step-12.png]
Step 12


Seen from below. Rivet the U brackets under each outer member 80 from the ends and fit the legs on M8 bolts. On the left wing rivet the two tie bar brackets and fit the tie bars; on the right wing screw on the two keepers.

### Step 13: wings onto the hinge angles

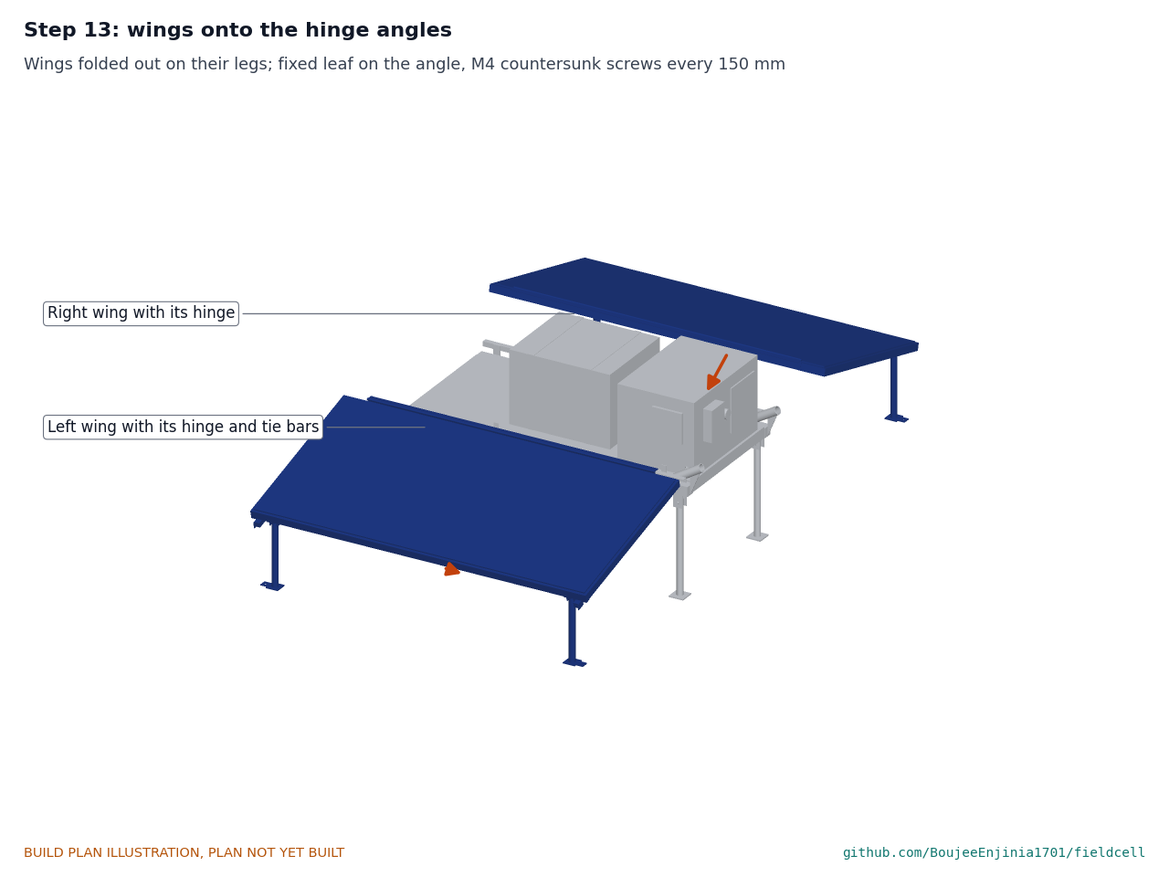
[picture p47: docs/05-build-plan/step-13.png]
Step 13


With a helper and the outrigger legs down, lay each wing in place and screw the hinge's fixed leaf to the spacer angle with M4 countersunk screws every 150, nyloc nuts beneath. Route each wing's leads along the hinge line to its PV gland but **do not connect them** (safety stop S3).

### Step 14: shade uprights, then the shade

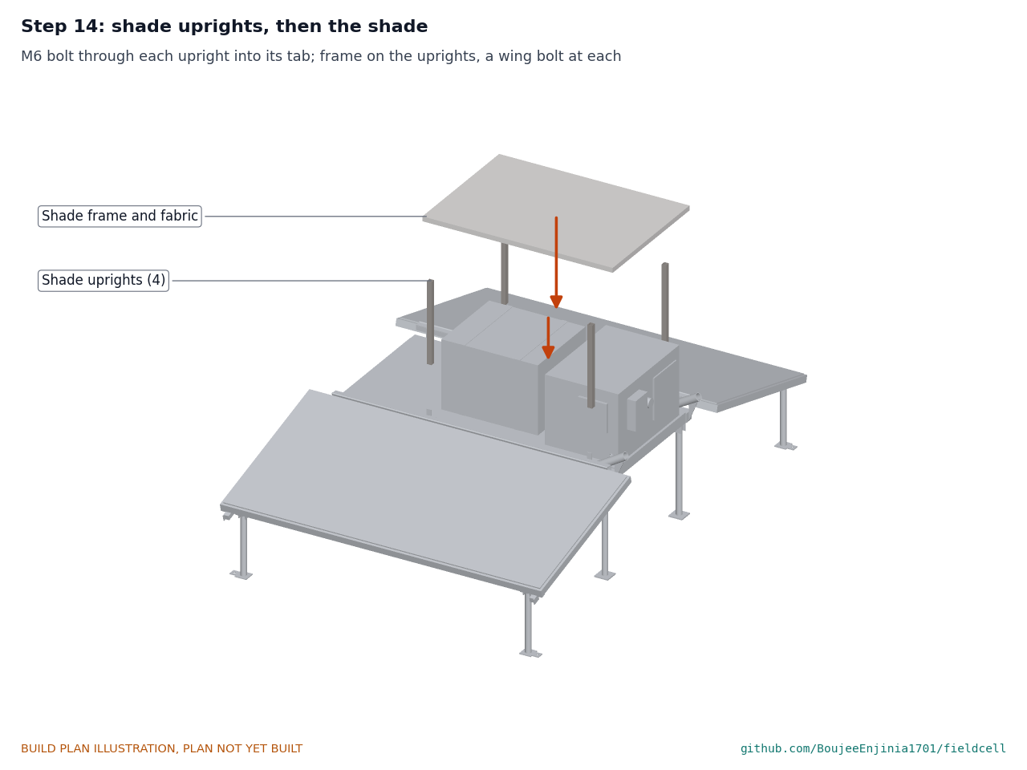
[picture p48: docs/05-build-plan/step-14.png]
Step 14


M6 bolt through each upright into its tab; lay the shade frame on the uprights and fit a wing bolt at each.

### Step 15: handle into its sockets

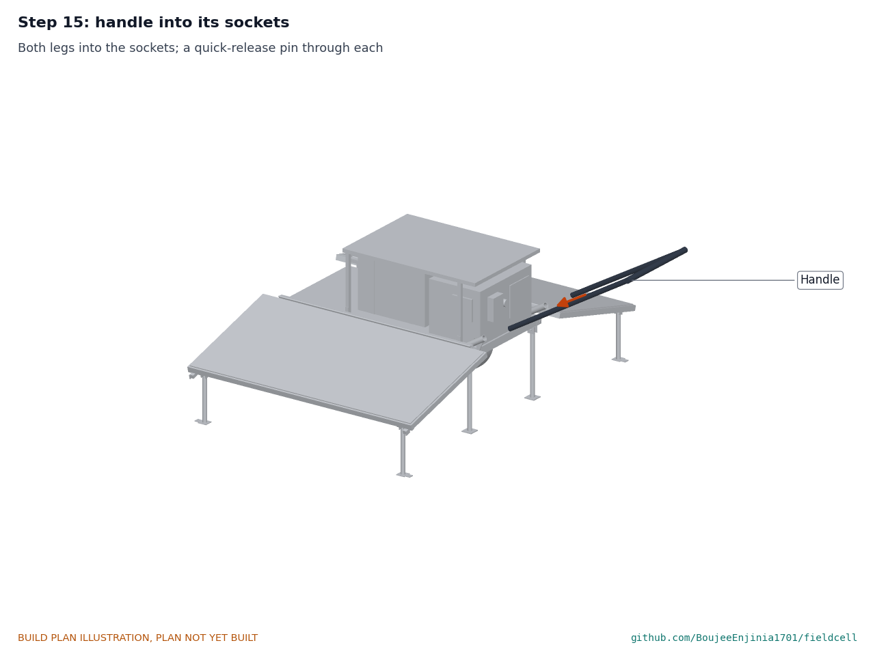
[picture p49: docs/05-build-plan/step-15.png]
Step 15


Both legs into the sockets; a quick-release pin through each.

### Step 16: accessory bin and strap

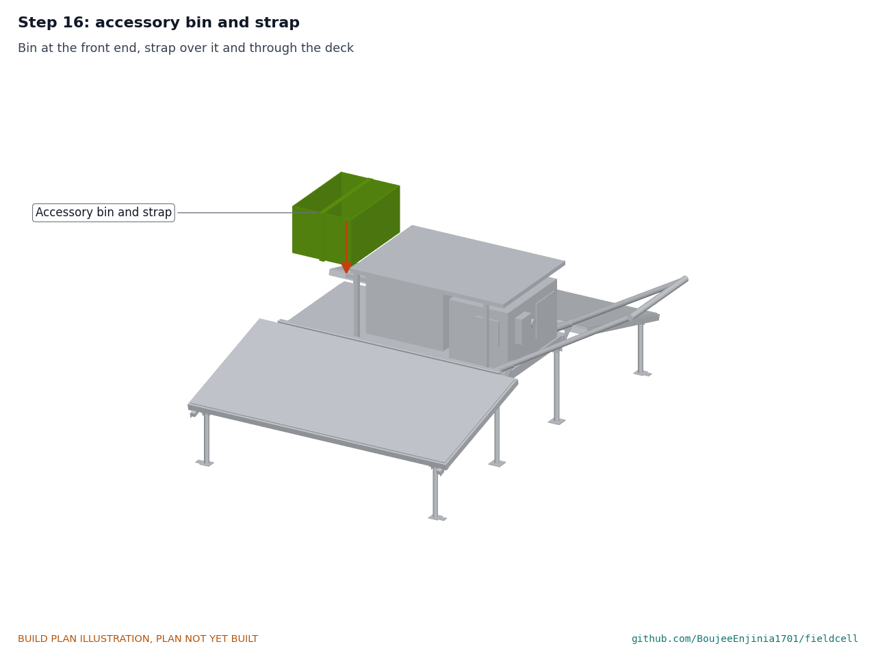
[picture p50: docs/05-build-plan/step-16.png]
Step 16


Bin at the front end, strap over it and through the deck.

### Step 17: fold for travel and tie the wings

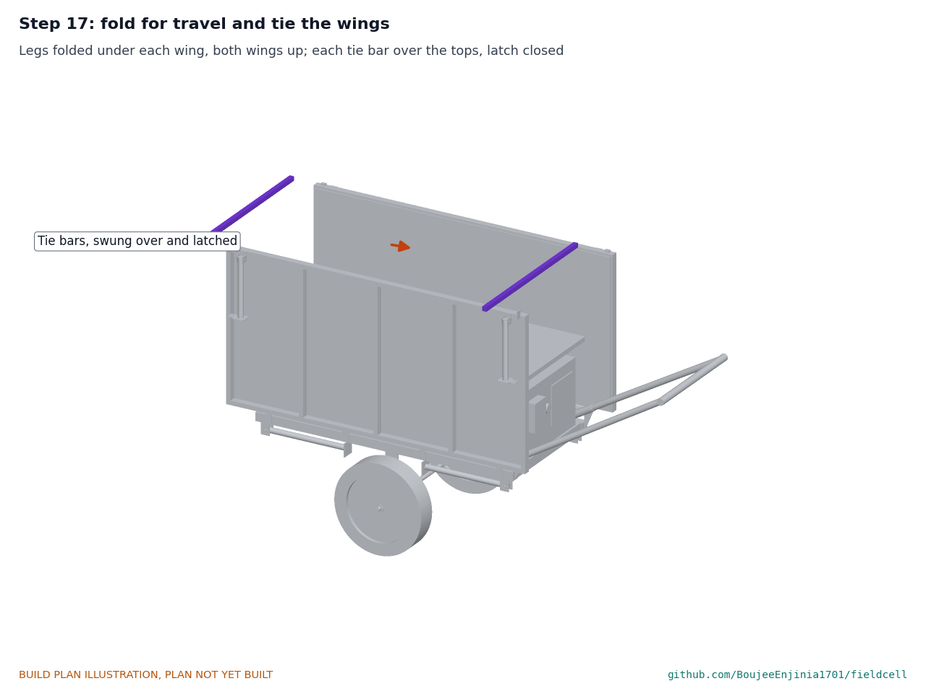
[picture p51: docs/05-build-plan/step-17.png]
Step 17


Fold each wing's outrigger legs flat under it; raise both wings until they stand upright; swing each tie bar over the tops and close its latch. Fold the stand legs. **Hold point:** safety stop S6 before the cart is moved.

## 5. First checks

These are the checks a TRL 4 test report would record; this plan only lists them. Requirement numbers are those of FCL-REQ-001.

*Table 2. First checks.*

| Check | Requirement | How | Pass when |
| --- | --- | --- | --- |
| Mass and handle force | R6 | Weigh the cart; spring balance under the grip, level and at 5° either way | Mass 82 kg or less (about 80 kg estimated); over 82 kg, the frame becomes bolted aluminium (FCL-DEC-001); handle force 10 to 150 N, never negative |
| Pull force | R7 | Spring balance at the grip on a measured 10 % grade, gravel and grass | 150 N or less on gravel, 160 N or less on grass (125 and 156 N estimated) |
| Ground clearance and step | R7 | Measure under the axle; pull over a 150 mm step | 150 mm or more; the step climbed by pulling |
| Wing to tyre and tilt | R3 (tilt); design check (gap) | Wings out on flat ground: gap over the tyre, angle finder on the panel | Gap 25 mm or more (28 mm modelled); 15°, give or take 1° |
| Deploy and stow | R5 | One person, timed, from arrival to power on and back | 10 minutes or less each (6.5 and 5.5 min estimated) |
| Tie bars hold | Design check | Stowed, latched: push each wing outward at the top | Nothing moves |
| Stand legs | Design check | Fold and unfold each leg; deck level when down | Detent holds both ways; deck level within 1° |
| Glands and lids | R8 | Look at every gland and seal; lids closed with cables in | Seals even, no gaps (the spray test comes later) |
| Fusing | R12 | Continuity and polarity with the fuse out; isolator off and on | Busbar open to negative with the isolator off; correct polarity everywhere |
| Charge | R3, R9 | Wings connected in sun; charge current at the controller | Current flows; charging stops above 45 °C cell temperature per the pack's datasheet |
| AC output | R2, R12 | Inverter on; GFCI test button | 120 V; GFCI trips |
| DC output | R2 | USB-C and 12 V outlets under a test load | Rated output at each |
| Stakes | R10 | Pull each staked outrigger foot upward | Holds 50 N or more |

## 6. Safety stops

Stop at each point. Carry on only when everything listed is true.

- **S1. Before the pack comes into the workshop.** Pack voltage about 24 to 27 V; no swelling, dents or leaks; a datasheet from its maker. Class T fuse out of its holder. A clear non-combustible floor area, and an extinguisher for electrical fires within reach. Two people to lift the 12 kg pack into its case.
- **S2. Before the class T fuse goes in.** Every connection tight and insulated; polarity checked with a meter, not by wire colour; with the isolator off, the busbar reads open to the negative bus; every breaker off; both lids closed.
- **S3. Before the wings are connected.** Cover both modules with an opaque sheet; the PV breaker off; polarity of each wing's leads checked at the gland; the open-circuit voltage of each wing measured below the charge controller's 100 V limit. PV leads are live whenever light falls on the modules.
- **S4. First charge.** Attended the whole time, in the open, on a dry day; pack temperature checked every 15 minutes. Stop if the pack passes 45 °C or any cable or terminal is warm to the touch.
- **S5. Before the inverter is switched on.** GFCI outlet wired and tested with its button; the inverter's earth and neutral connected only as its maker specifies for a stand-alone source; no cord connected to any building wiring, ever.
- **S6. Before the cart is moved or lifted.** Tie bars latched, stand legs folded and pinned, handle pinned. The cart is about 80 kg: two people to lift it into a vehicle, with the pack removed first if possible. Do not cross slopes across the fall line.
- **S7. Before deploying outdoors.** Stake the four outrigger feet whenever wind is expected; unstaked, the wings can lift at about 9 m/s; stow above that if they cannot be staked. Keep fingers out of the hinges and folding legs.

## 7. Tools, skills and workspace

**Tools.** MIG welder with a 0.8 mm wire for 1.5 to 5 mm steel; angle grinder with cutting and flap discs; metal-cutting chop saw or bandsaw; bench drill and drills 3 to 20.5 mm; step drill to 30 mm; countersink; jigsaw with fine metal and plastic blades; files and a deburring tool; welding table or a flat bench; clamps and magnetic squares; tape measure, steel rule, square, angle finder and calipers; hand rivet tool for 4.8 mm rivets and a rivet nut tool for M4; spanners and sockets to 17 mm; crimp tool for 16 mm² lugs and ferrules, wire strippers; digital multimeter and a DC clamp meter; spring balance to 25 kg and a platform scale to 100 kg; stopwatch.

**Skills.** Basic MIG welding of thin steel tube, marking out, drilling, riveting, and crimping heavy battery cable. The DC system is extra-low voltage (up to about 29 V at the pack and about 50 V from the wings), but it carries up to about 100 A; the 120 V AC side is limited to bought parts plugged and wired as their makers specify. Anyone wiring the AC outlet must be competent with mains-voltage wiring under local code.

**Workspace.** A garage bay about 3 x 4 m with a welding area kept clear of anything that burns, and a separate clean bench for the electronics so grinding dust stays off them.

**Personal protective equipment.** Welding helmet, gloves and jacket; safety glasses for cutting, grinding and drilling; hearing protection; cut-resistant gloves for sheet and tube; insulated tools and no rings or watch when working on the battery.

## 8. Where the numbers come from

- Model and constructability checks: `cad/src/model.py` (`python cad/src/model.py --check`); STEP and STL exports in `cad/step/` and `cad/stl/`.
- Pictures: `cad/src/build_plan_media.py`, using `.kit/build_views.py`; written to `docs/05-build-plan/` and `cad/drawings/FCL-DWG-101` to `FCL-DWG-111`.
- General arrangement: `cad/drawings/FCL-DWG-002.pdf`, Rev P4.
- Calculations: `docs/04-calcs/01-sizing.md` (FCL-CAL-001 v0.3) and `docs/04-calcs/sizing.py`; mass [E1] to [E8], pull and step [F1], [F2], wing to tyre [F4], wind [H1], [H2], deploy and stow [I1], envelope [K1].
- Bill of materials: `bom/bom.csv`.
- Decisions: `docs/decisions/0003-design-for-construction.md` (FCL-DDR-003), with FCL-DDR-001 and FCL-DDR-002.
- Requirements: `docs/03-requirements.md` (FCL-REQ-001 v0.5).

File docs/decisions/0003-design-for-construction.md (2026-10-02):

---
doc_id: FCL-DDR-003
title: FieldCell design for construction
project: FieldCell
doc_type: Design decision record
version: "0.3"
status: Draft
date: '2026-10-02'
author: Amish Chadha
license: CERN-OHL-S-2.0
revisions:
- version: "0.1"
  date: '2026-10-01'
  author: Amish Chadha
  change: Changes that make the concept physically buildable, with the reason for each; made under Amish's 2026-09-30 instruction to make the design physically buildable; open for his review
- version: "0.2"
  date: '2026-10-01'
  author: Amish Chadha
  change: Budget treated as a value-engineering target
- version: "0.3"
  date: '2026-10-02'
  author: Amish Chadha
  change: "Accepted by Amish on 2026-10-02, with A1 sharpened (R6 at 82 kg, R7 grass pull at 160 N), A3 and A4 as recommended"
---

# 0003: Design for construction

- **Date:** 2026-10-01
- **Status:** accepted. Amish, 2026-10-02: "i approve your recommendations for all 555 open decisions." This covers every change in Tables 1 and 2 (P1 to P13) and the items in Table 3, now decided and recorded in the design decisions register (FCL-DEC-001). A1 was decided in a sharpened form: R6 is set at 82 kg and the R7 grass pull at 160 N, not 80 kg, so that the 80.0 kg cart keeps a margin.

## Context

On 2026-09-30 Amish asked for every repo to have an illustrated prototype build plan and wrote: "If you are realising that the design cannot be built as per concept - fix the design assumptions to match and be physically feasible as you draw the illustrations." The concept model of FCL-DDR-002 showed what FieldCell does, but it was a massing model: build123d checks found parts cutting into each other, parts standing in mid air and parts with no fixing. Examples: the deck sheet cut 5 mm into all three cross tubes (36,660 mm³ of overlap); the hinge spacers stood 20 mm clear of the rails, which the appearance-model session of 2026-09-26 had already noted; the hinge tubes cut 1.25 million mm³ into the folded-out wings; the axle stopped at the wheel centres and the wheels had no bore; the sun shade posts stood beside the boxes, 300 mm above the frame, touching nothing; and the fusing block sat on top of the charge controller.

The changes keep what FieldCell does: the same cart, frame size, wheels, deck height, wings, 15° tilt, hinge line and 28 mm wing-to-tyre clearance, the same battery, electronics, outlets and shade, the same layout rule (heavy parts low and over the axle) and the same deploy-by-one-person sequence. They do not change the pitch or the safety case; the class T fuse moves to where the safety section already says it must be. Every change is in `cad/src/model.py`, which now runs 96 constructability checks in both the parked and travel poses (`python cad/src/model.py --check`): parts that must touch do touch, and parts that must not touch are apart by at least the stated clearance. All 96 pass.

## Decision

*Table 1. Changes made to the model, the BOM and the calculations.*

| # | Problem in the concept | Change made | Why this way |
| --- | --- | --- | --- |
| P1 | Deck sheet inside the frame, cutting 5 mm into the cross tubes | Expanded steel sheet 1,200 x 520 mm laid on top of the three cross tubes, between the rails, stitch welded; all tubes 5 mm lower so the deck top stays 460 mm above the ground | The sheet is carried by the cross tubes instead of hanging in the frame opening; deck height, clearance and every height above it are unchanged |
| P2 | Open rail ends | 3 mm steel end caps on the four rail ends | Seals the tubes and gives the handle socket gussets a face to weld to |
| P3 | Axle brackets cut 10 mm into the rails, unbraced; axle ended at the wheel centres; wheels had no bore | Brackets 60 x 5 mm plate, 247 mm long, welded under each rail 290 mm out, with a 5 mm gusset to the middle cross tube; 20 mm axle 820 mm long welded to both brackets; each wheel (20 mm bore with bearings) between a 37.5 mm spacer collar and a washer, held by a linch pin | A fixed axle with the bearings in the bought wheels is the simplest garage build; the collar sets the wheel clear of the bracket; the gusset carries side loads into the frame |
| P4 | Stand legs half under the rails, touching them, with no pivot or lock | Legs under the rail centre line on pairs of 3 mm clevis plates welded under the rails 40 mm from each end; M10 pivot bolt 35 mm below the rail; spring detent pin; 60 x 60 x 5 mm feet; legs fold inward along the rail | The concept says the legs fold; this is a fold that clears the wheels (8.6 mm) and the rails (5 mm) |
| P5 | Handle tubes ran into the end cross tube with no joint, although the handle detaches | Two 33.7 x 2.6 mm sockets welded on the rail ends at 30.5°, each with a 4 mm gusset to the end cap; the 28 mm handle legs slide in (0.25 mm clearance) and a quick-release pin holds each | Keeps the detachable handle and the 900 mm grip height |
| P6 | Hinge spacer angles 20 mm clear of the rails; hinge tube inside the folded-out wing; no hinge leaves | Eight 30 x 3 mm steel tabs welded to the rail outer faces carry the decided 20 x 20 x 2 mm angle on M5 bolts; a 1.2 m stainless piano hinge with 26 x 1.5 mm leaves, fixed leaf screwed to the angle, moving leaf to the wing's inner member; hinge pin 4.5 mm above the panel face (330 mm out, 495 mm up) | The angle decided in FCL-DDR-002 is kept and given something to bolt to. The pin sits just above the panel face so the panel clears the knuckle and lies exactly where the concept put it: 28 mm over the tyre, 15° tilt, 2,012 mm span |
| P7 | Each wing a solid block | 200 W semi-flexible module (about 1,380 x 680 mm) bonded with structural tape to a 1,400 x 700 mm frame of 30 x 20 x 1.5 mm aluminium tube with three ribs, joined by inside corner cleats and rivets; wing about 6.0 kg (6.5 kg assumed) | The "ventilated aluminium backing frame" of the BOM made definite: open bays ventilate the module, every member supports it |
| P8 | Outrigger legs pushed into the wing underside with no fixing | Aluminium U bracket riveted under the wing's outer member, 80 mm from each end; M8 pivot; 269 mm leg of 25 x 2 mm steel tube; 50 x 50 x 4 mm foot with its stake loop pointing along the cart; legs fold flat under the wing, 7.5 mm clear of the frame | A leg that folds and locks, with the loop placed so the folded leg lies flat |
| P9 | Over-centre latches with nothing to latch to: stowed, the wing's inside face is the PV module | Two tie bars (20 x 20 x 1.5 mm aluminium, 731 mm) pivoted on brackets at the top corners of the left wing; in travel each lies across the tops of both wings and an over-centre latch on its end pulls the right wing in against it; parked, it folds down the back of the left wing. Two latches and keepers instead of four | Nothing may press on the module face, and the frame's only free faces are its tops and backs. One bar at each end, both kept on the wing, nothing loose. Adds about 0.5 min to deploy and to stow |
| P10 | Shade posts stood beside the boxes in mid air; the shade blocked the battery lid | Four 20 x 20 x 1.5 mm aluminium uprights, 355 mm, bolted to tabs on the rail tops at 400 and 1,100 mm from the front end; shade frame 830 x 580 mm (was 540 mm wide) rests on them with a wing bolt at each; lift it off to open the battery lid | Same 50 mm air gap over both boxes; the uprights sit on the frame, 28 mm clear of every box; the frame rests on the uprights, so the extra 40 mm of width is where they stand |
| P11 | Fusing block sat on top of the charge controller; outlets and fans drawn as boxes outside the wall; class T fuse in the electronics box, more than 250 mm from the battery terminal | Inverter, charge controller and DIN rail (breakers and shunt) side by side on the box's mounting plate; outlets, isolator, filter fan and exhaust filter through cut-outs; class T fuse holder inside the battery case beside the pack, within 150 mm of the positive terminal; isolator on the outlet face | Every part has a fixing and at least 10 mm to its neighbours. The fuse goes where the safety section (FCL-PRC-001) already requires it |
| P12 | 50 mm between the boxes: two M25 gland domes and the cables did not fit | Electronics box moved 10 mm toward the handle (its end 10 mm inside the frame end); 60 mm between the boxes; two M25 glands in each facing wall, 40 mm each side of centre, 150 mm up; 16 mm of cable between the domes; two M16 PV glands in the electronics box side walls | Shortest, straight cable run; nothing bends between the boxes |
| P13 | Battery case, electronics box and bin not fixed to the deck; pack loose in its case | Two cam straps round the battery case and lid, through the deck; four M6 bolts through the electronics box floor with large washers under the deck; bin strap through the deck; pack on a rubber mat with foam blocks | So nothing moves on rough ground or in a tip |

*Table 2. Knock-on changes.*

| Item | Change | Reason |
| --- | --- | --- |
| Mass | 75.06 kg to 79.99 kg (+4.93 kg) [E3]. Frame 12.8 to 15.4 kg, weighed from the model's own solids [E1]; stand legs 1.8 to 2.5 kg; hinges, latches, outriggers and stakes 3.0 to 4.1 kg; shade 1.0 to 1.55 kg; tie bars 0.5 kg and straps 0.3 kg added; wings 13.0 to 12.0 kg [E8] | Brackets, gussets, tabs, sockets, clevises, end caps and fixings that the massing model did not have |
| Requirements | R6 not met by 5.0 kg (was 0.06 kg); handle force 14 to 54 N [E4]. R7 now not met: 156 N pull on grass against 150 N [F1]. R12 cost over the value-engineering target by USD 1 [J1]. Unstaked wing lift 9.2 to 8.9 m/s [H1]; stake pull-out 28 N [H2]. Deploy 6.0 to 6.5 min, stow 5.0 to 5.5 min [I1] | Follows the mass and the tie bars |
| Envelope | Stowed without the handle 1,400 x 784 x 1,190 to 1,400 x 830 x 1,220 mm [K1] | Folded outrigger feet and the tie bars, now in the model |
| Cost | BOM lines 1, 2, 3, 4, 12, 13, 14, 15, 16, 17 and 18 re-specified, line 19 (tie bars) added; $2,051 to $2,101 against the unchanged $2,100 value-engineering target (`budget_usd`) | Parts added for construction |
| Drawing | FCL-DWG-002 Rev P4; making sketches FCL-DWG-101 to 111 added | Follows the model |
| Documents | FCL-CAL-001 v0.3, FCL-PRC-001 v0.5, FCL-REQ-001 v0.5 | Follows the model |
| Thermal | Unchanged: boxes, shade gap and fan unchanged; the class T fuse adds no heat of note | |

*Table 3. Proposed, then decided by Amish on 2026-10-02.*

| # | Question | Options | Recommendation |
| --- | --- | --- | --- |
| A1 | The buildable cart is about 80 kg: R6 (75 kg) is missed by 5 kg and R7 (150 N on a 10 % grass grade) by 6 N | (a) relax R6 to 80 kg and the R7 grass figure to 160 N, keeping the decided steel frame and flat-free tyres; (b) bolted aluminium frame, about 72.7 kg and 142 N, meeting both but reversing D5 (FCL-DDR-001); (c) pneumatic tyres, about 77.6 kg, still over; (d) both, about 70.3 kg | (a) for the first prototype, and weigh it at TRL 4; take (b) if the weighed cart is over 80 kg. **Decided 2026-10-02:** (a) with R6 at 82 kg and the R7 grass pull at 160 N; (b) if the weighed cart is over 82 kg |
| A2 | The BOM is $2,101 against the $2,100 value-engineering target (`budget_usd`, a hypothetical control target), USD 1 over | No decision needed. The target stays $2,100; supplier quotes for the pack, wings and inverter will give the real cost | Carry in the value engineering section of FCL-DEC-001 |
| A3 | Tie bars add a step to deploy and stow (R5 still met at 6.5 and 5.5 min) | (a) tie bars as modelled; (b) two webbing straps with cam buckles over the wing tops | (a): stiffer, nothing to lose, and they hold both wings at once. **Decided 2026-10-02: (a)** |
| A4 | The shade must be lifted off (four wing bolts) to open the battery case | (a) accept, since the battery case is opened only for service; (b) hinge the shade on its handle-end uprights | (a). **Decided 2026-10-02: (a)** |

## Consequences

- `design_state: constructable` in `project.yaml`. The build plan FCL-BLD-001 shows every component and step in pictures generated from the model (`cad/src/build_plan_media.py`); the decisions are recorded in the design decisions register FCL-DEC-001.
- Requirement status (FCL-CAL-001 v0.3): 6 met, 2 not met (R6, R7), 1 over its value-engineering target (R12), 1 at risk (R9), 2 not verifiable at TRL 3 (R8, R11). Before: 7 met, 1 not met, 2 at risk, 2 not verifiable. With A1 decided on 2026-10-02 (R6 at 82 kg, R7 grass pull at 160 N): 8 met, none not met, 1 over its value-engineering target (R12), 1 at risk (R9), 2 not verifiable at TRL 3.
- The photoreal renders (`media/render-*.png`), `media/card.png`, `media/social-preview.png` and the appearance model `cad/src/product_model.py` still show the concept hinge spacer, shade posts, outrigger feet and electronics layout, and have no tie bars; they need updating on Amish's Mac, where Blender is.
- The wing module, wheels, enclosures and outlets are chosen at TRL 4; their sizes must be checked then against the model (FCL-DEC-001, "To confirm when parts are bought").

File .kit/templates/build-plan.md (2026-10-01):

---
doc_id: PRJ-BLD-001
title: Project prototype build plan
project: Project name
doc_type: Build plan
version: "0.1"
status: Draft
date: YYYY-MM-DD
author: Amish Chadha
license: CERN-OHL-S-2.0
revisions:
  - version: "0.1"
    date: YYYY-MM-DD
    author: Amish Chadha
    change: First build plan; design made constructable
---

# Project prototype build plan

**Plan, not yet built.** How to build the first proof-of-concept prototype, component by component. Building and testing to it is TRL 4 work. Decisions still to be made are kept in the design decisions register (`docs/06-design-decisions.md`), not here.

## 1. What you are building

Every component, pulled apart and numbered in build order

One short paragraph: what the prototype is, how many components, which are made and which are bought, and the main ways they are made.

## 2. What changed to make it buildable

| Component | The concept had | The buildable design has | Why |
| --- | --- | --- | --- |

## 3. Making the components

### 3.1 Component name

Making sketch

**What it is and what it is made from.**

**How to make it.**

1. Mark out ...
2. Cut ...

**How it fits the parts next to it.**

Close-up of the joint

**Check before moving on.**

## 4. Putting it together

### Step 1: ...

Step 1

## 5. First checks

| Check | Requirement | How | Pass when |
| --- | --- | --- | --- |

## 6. Safety stops

## 7. Tools, skills and workspace

## 8. Where the numbers come from

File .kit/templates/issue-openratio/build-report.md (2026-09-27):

---
name: Build report
about: Tell us what happened when you built, printed or tested part of this design
title: "Build report: "
labels: build-report
---

This is a research and educational prototype, not a medical device. It is a TRL 3 concept and is not released for fabrication. If you build any part of it, you do so at your own risk. Reports help everyone.

**What you built** (part, sub-assembly or test)

**Materials, tools and settings**

**What worked**

**What did not work, with photos or measurements if you have them**

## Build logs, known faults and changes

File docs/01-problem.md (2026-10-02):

---
doc_id: FCL-PRB-001
title: FieldCell problem statement
project: FieldCell
doc_type: Problem statement
version: "0.5"
status: Draft
date: '2026-10-02'
author: Amish Chadha
license: CERN-OHL-S-2.0
revisions:
- version: "0.1"
  date: '2026-09-24'
  author: Amish Chadha
  change: Initial scaffold
- version: "0.2"
  date: '2026-09-24'
  author: Amish Chadha
  change: Populate to TRL 2 (users, context, constraints, out of scope, prior work)
- version: "0.3"
  date: '2026-09-25'
  author: Amish Chadha
  change: Record decisions of FCL-DDR-001 (first user group, 120 V first build); budget note from FCL-CAL-001
- version: "0.4"
  date: '2026-09-25'
  author: Amish Chadha
  change: Recommendations accepted by Amish (DDR-002)
- version: "0.5"
  date: '2026-10-02'
  author: Amish Chadha
  change: "Responder review decided by Amish on 2026-10-02; Team Rubicon named as the first candidate to approach"
---

# FieldCell problem statement

Disaster responders and remote crews power small loads (radios, lights, laptops, chargers) with portable fuel generators that are loud, give off carbon monoxide, need a steady fuel supply and run far below their rated power most of the time.

## The problem

A typical field post draws a few hundred watts on average: radio and phone charging, LED area lighting, a laptop and a router, with short bursts from a power tool or a small pump. The usual answer is a 2 to 5 kW petrol or diesel generator. At these loads a generator spends most of its life near idle, where fuel use per kilowatt-hour is worst, and it must be refuelled every few hours from a supply chain that a disaster may have cut.

The generator also shapes the site. Open-frame units are commonly rated at about 65 to 75 dB(A) at 7 m, loud enough to mask radio traffic and voices, so they are placed away from people and run on long cords. Exhaust carbon monoxide is a recurring cause of injury and death after storms, when generators are run in or near shelters, garages and tents. Fuel adds a storage and spill hazard.

Solar plus battery systems solve the noise, fumes and fuel problems, but the field options fall into two awkward groups. Portable power stations are easy to carry but hold under about 1 kWh in most sizes under 15 kg and need separate folding panels that must be laid out, aimed and cabled. Towed solar trailers and containerized systems carry several kilowatts but need a vehicle and often a crew to deploy. There is no open, inspectable design in between: a single-person, wheel-it-in unit with about 1 kWh of storage and a few hundred watts of built-in PV that is working within minutes of arrival.

## Users and context

*Table 1. Users, needs and context.*

| User | Need | Context |
| --- | --- | --- |
| Disaster responder (search and rescue, field medical post, incident command) | Quiet, fume-free power for comms, lighting and chargers from the first hour; no refuelling | Damaged areas, debris, mud, rain; set up next to people and tents |
| Humanitarian field team | Power a registration or water point for days with little resupply | Camps and distribution sites, hot or cold climates |
| Remote crew (trail, survey, environmental monitoring, utility) | Daytime power for tools and battery charging away from any vehicle track | Rough ground, hills, grass and gravel |
| Community resilience hub or event | A shareable unit to power phones, lights and a router during outages | Parks, schools, community centers |
| Open hardware builder | A reproducible design to build, audit and adapt | Garage or makerspace |

## Constraints

- Prototype parts cost about $2,100 USD (`project.yaml`, raised from $1,500 by Amish on 2026-09-25, FCL-DDR-002), using off-the-shelf electronics and a welded steel frame. The TRL 3 BOM totals about $2,051 (FCL-CAL-001).
- One person must move, deploy and stow it, without tools, on uneven ground.
- Must work in rain and dust, and through a range of field temperatures, while its lithium cells stay within safe charging limits.
- Electrical safety: fused circuits, ground-fault protection on AC outlets, a clear disconnect, and no connection to building wiring.
- Garage-buildable: common tools, no custom printed circuit boards for the first build.
- Must fit a pickup bed or van with the handle removed, and be light enough for two people to lift into one.

## Out of scope

- Connection to building or grid wiring, including back-feeding through an outlet or a transfer switch.
- Fuel-hybrid operation (a generator input may be discussed later as an option, not designed here).
- Life-critical medical loads that need a certified uninterruptible power supply.
- Towing behind a vehicle at road speed.
- Megawatt-hour or multi-kilowatt site power; that is the domain of trailers and containers.

## Prior work

- **Portable power stations** (for example EcoFlow, Jackery and Bluetti) package a lithium battery, inverter and outlets in one box, with folding panels sold separately. They are closed designs, and most units above 1 kWh are heavy to carry by hand.
- **Towed solar trailers and solar light towers** are used on construction sites and in military expeditionary power. They carry more energy and PV but need a vehicle to move.
- **Hybrid generator programs** in humanitarian and military logistics pair a generator with a battery bank so the engine runs less often, which shows the value of storage at small field loads.
- **Open designs** for solar carts and DIY "solar generators" exist as hobby builds and videos, but few publish a complete, reviewed design with requirements, safety analysis and a bill of materials.

## Open questions

- First user group: disaster response. Decided by Amish, 2026-09-25 (FCL-DDR-001, D8). Humanitarian field teams and remote crews remain secondary users.
- Which responder organization, if any, could review the deployment sequence and load profile? Decided by Amish, 2026-10-02: seek one now, for a paper review only. The first candidate to approach is a US volunteer disaster response organization such as Team Rubicon, since the first build is 120 V 60 Hz; nothing is agreed (FCL-DEC-001).
- Output voltage: 120 V 60 Hz for the first build, with a 230 V 50 Hz variant documented. Decided by Amish, 2026-09-25 (FCL-DDR-001, D4).

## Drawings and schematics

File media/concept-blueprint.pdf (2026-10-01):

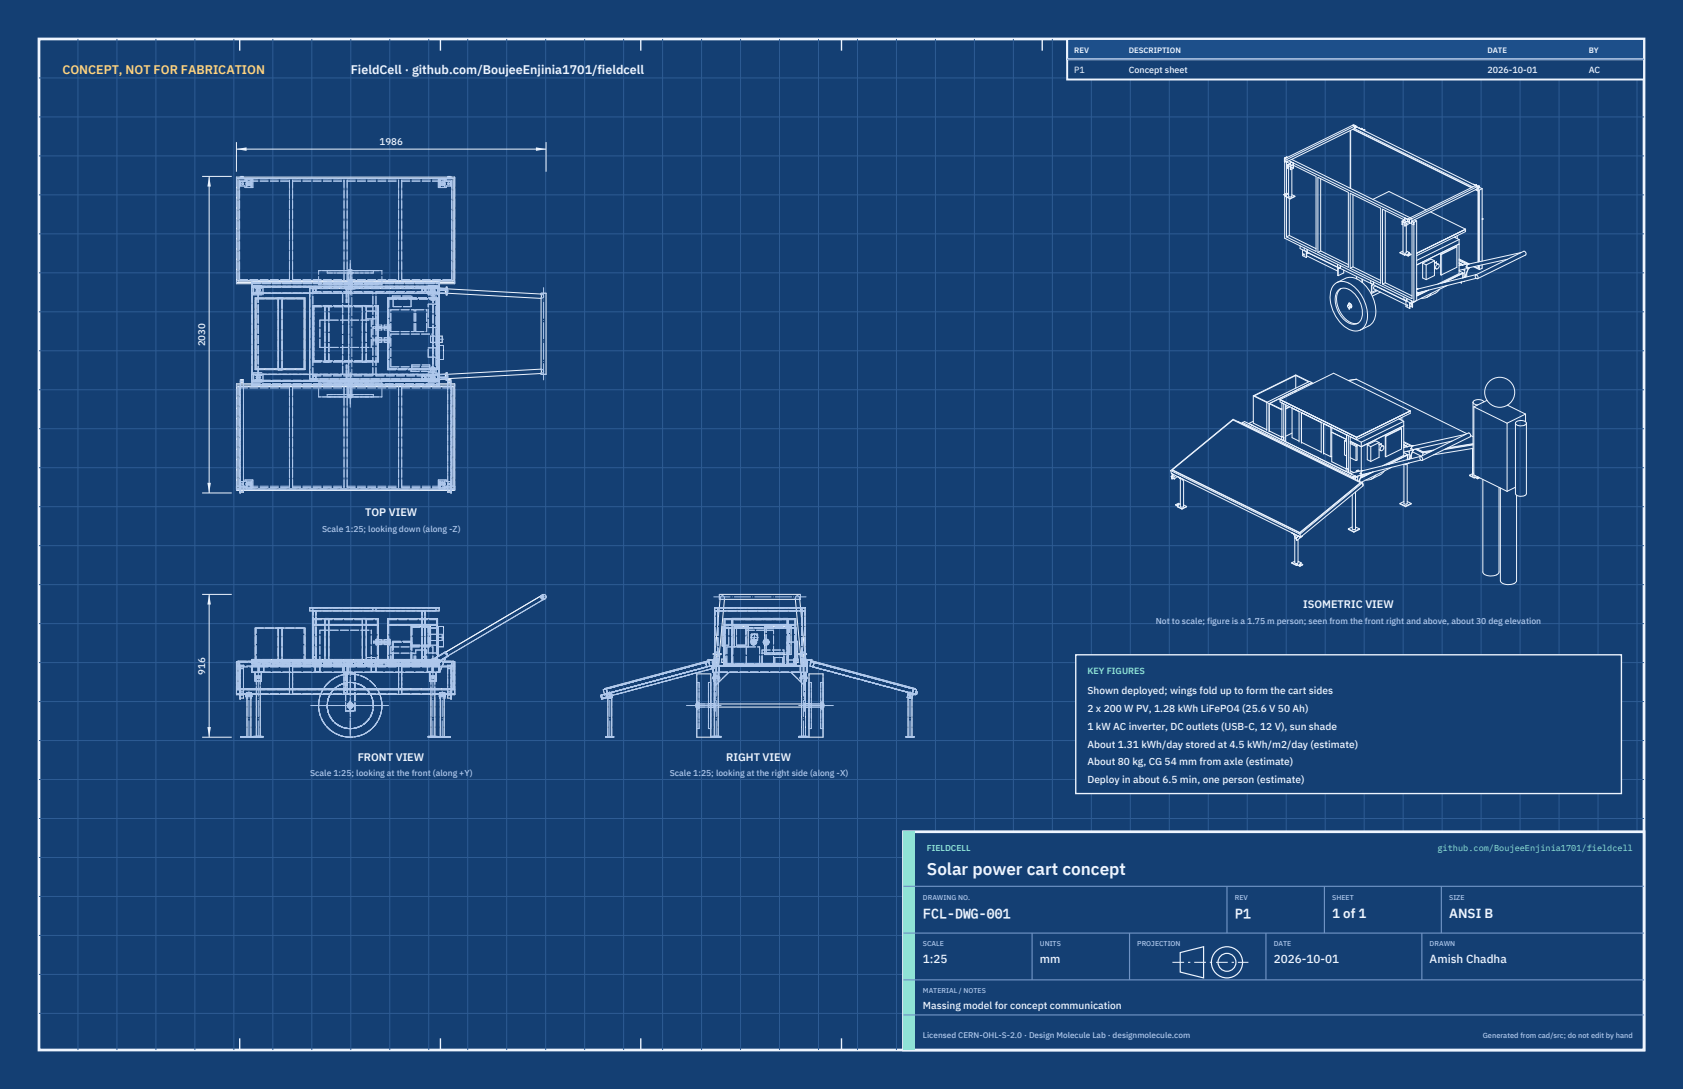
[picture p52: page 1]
CONCEPT, NOT FOR FABRICATION; FieldCell · github.com/BoujeeEnjinia1701/fieldcell; FRONT VIEW; TOP VIEW; RIGHT VIEW; ISOMETRIC VIEW; REV; DESCRIPTION; DATE; Concept sheet; FIELDCELL; github.com/BoujeeEnjinia1701/fieldcell; DRAWING NO. FCL-DWG-001; REV P1; SHEET 1 of 1; SIZE ANSI B; SCALE 1:25; UNITS mm; PROJECTION; DRAWN Amish Chadha; Licensed CERN-OHL-S-2.0 · Design Molecule Lab · designmolecule.com; Generated from cad/src; do not edit by hand

Scale 1:25; looking down (along -Z)

Not to scale; figure is a 1.75 m person; seen from the front right and above, about 30 deg elevation

KEY FIGURES
Shown deployed; wings fold up to form the cart sides
2 x 200 W PV, 1.28 kWh LiFePO4 (25.6 V 50 Ah)
1 kW AC inverter, DC outlets (USB-C, 12 V), sun shade
About 1.31 kWh/day stored at 4.5 kWh/m2/day (estimate)
About 80 kg, CG 54 mm from axle (estimate)
Deploy in about 6.5 min, one person (estimate)

Scale 1:25; looking at the front (along +Y)

Scale 1:25; looking at the right side (along -X)

Solar power cart concept

MATERIAL / NOTES
Massing model for concept communication

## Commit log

2026-09-24 Initial scaffold: standard open hardware layout, CERN-OHL-S v2 + MIT licenses
    Claude-Session: https://claude.ai/code/session_01XuhhSU4W6fYhgCfURbrkut
    [bom.csv]
2026-09-25 Adopt portfolio kit v1.3.0: session commands, scale figure, 3D viewer, flow diagrams
    Adds .claude/commands (/populate, /advance-trl3, /rein-in, /refresh-media)
    so every Claude Code session starts from the standard prompts, and extends
    concept media with a 1.75 m scale figure, an interactive glTF viewer and
    system or energy flow diagrams. TRL cap 3 unchanged.
    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
2026-09-25 Kit v1.3.1: renderer fixes from the TremorTrace pilot
    Context scale parts for small objects, cutaway exclusions, and text
    labels in flow diagrams.
    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
2026-09-25 Populate fieldcell to a strong TRL 2 with concept media (batch 1)
    Problem, requirements and precis v0.2, massing model and concept media,
    indicative BOM, docs/REVIEW.md with decisions proposed and awaiting Amish.
    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
    [bom.csv]
2026-09-25 Advance fieldcell to TRL 3 (batch 1)
    Decisions approved by Amish 2026-09-25 recorded in DDR-001. TRL 4 is on hold.
    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
    [battery-enclosure.step, battery-enclosure.stl, bom.csv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]
2026-09-26 Accept all recommendations (DDR-002), switch footer to designmolecule.com, add README write-up with new inspiration point
    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
    [battery-enclosure.step, bom.csv, electronics-enclosure.step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]
2026-09-27 Product appearance model and photoreal renders
    Adds cad/src/product_model.py (appearance model for renders only, all main
    dimensions from model.py) and Blender renders in media/render-*.png,
    captioned with the project, repository and viewing direction. README leads
    with the product render; trl stays 3.
    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
2026-10-01 Image quality pass: legible exploded views, flow diagrams and drawing sheets
    Kit 1.6.1 image layout: the parts list sits in its own column, number bubbles sit on visible parts and never overlap, small parts get a leader, pictures are cropped to the subject, flow labels keep numbers with their units, and sheet captions and the revision table no longer overprint. Concept images, blueprint and general arrangement sheet regenerated; repo-specific labels moved clear of other text and lines.
2026-10-01 Kit 1.7.0: constructable design, illustrated build plan and design decisions register
    The design is now constructable: every part can be made and fits its neighbours, with each change recorded in a Design for construction decision record (made under Amish's 2026-09-30 instruction; ope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
    [battery-enclosure.step, battery-enclosure.stl, bom.csv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]
2026-10-02 Record Amish's approval of the open-decision recommendations
    Amish approved the recommendation on every open decision in the design decisions register ("i approve your recommendations for all 555 open decisions.", 2026-10-02). Each decision is moved to Decisio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
2026-10-03 Carry approved follow-ups into the design and redo photoreal renders
    Amish approved the follow-up actions from the open-decision sign-off ("APPROVED CHANGES, COMPLETE THESE", 2026-10-02), the design-for-construction change tables in ten repos, the last wave's open dec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

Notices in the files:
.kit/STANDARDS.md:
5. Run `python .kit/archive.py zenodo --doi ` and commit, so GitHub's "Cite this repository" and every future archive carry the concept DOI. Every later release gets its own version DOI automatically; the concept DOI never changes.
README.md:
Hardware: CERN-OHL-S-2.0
